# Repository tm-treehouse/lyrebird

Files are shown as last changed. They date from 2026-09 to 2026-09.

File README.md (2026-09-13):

# lyrebird

PCM audio from a host PC to an FPGA over USB, with no USB IP in the fabric.

```
Host PC ──USB 3.0──> FT601Q ──245 Sync FIFO, 32-bit, 66.67 MHz──> GateMate
                                                                     │
                                              28 element lines over mezzanine
                                                                     │
                            reclock ──> matched resistors ──> filter ──> line / headphone
```

An FTDI bridge puts the USB device controller and endpoints in silicon and
presents the FPGA with a dumb synchronous FIFO, so the fabric needs no USB
knowledge. The FPGA owns the audio clock; the host is flow-controlled by
backpressure.

There is no DAC chip. The FPGA runs an interpolator and a three-bit
delta-sigma modulator with dynamic element matching, and drives a resistor
network directly.

Two boards, joined at the element lines. The main board carries USB, the FPGA,
and the power tree. The output module carries the oscillators, the reclocking
flip-flops, the resistors, and the analog stage, so nothing analog crosses a
connector and the output stage can be revised without respinning the expensive
half.

See [docs/usb-audio-handoff.md](docs/usb-audio-handoff.md) for the original
design context, [docs/decisions/](docs/decisions/) for the rationale behind the
load-bearing choices, [docs/open-items.md](docs/open-items.md) for what is
still undecided, and [hardware/interface.md](hardware/interface.md) for the
contract between the two boards.

## Layout

| Path | Holds |
| --- | --- |
| `hardware/` | Two KiCad projects, datasheets, fab output, board interface |
| `hdl/` | Synthesizable RTL, constraints, cocotb testbenches |
| `host/` | C driver and WAV pump against the FTDI D3XX API |
| `docs/` | Design context and architecture decision records |
| `tools/` | Build, program, and bring-up scripts |

## Toolchain

- **PCB** — KiCad
- **FPGA** — Cologne Chip GateMate CCGM1A1, Yosys plus nextpnr-himbaechel via
  Project Peppercorn
- **Simulation** — Verilator with cocotb, driven by `hdl/sim/run.py`
- **Host** — C against FTDI D3XX

See [0013](docs/decisions/0013-simulation-and-build-toolchain.md) for verified
versions and which tools are still missing locally.

## Status

Simulation and synthesis both run end to end. Three HDL modules exist with 35
passing cocotb tests under Verilator, and `tools/synth.sh` takes a design from
source to a packed bitstream.

The audio chain is modelled numerically in [model/](model/), which settled the
modulator order, the interpolation cascade, the fixed-point coefficient widths
and the rotation algorithm with measurements. Both boards are described as code
in [hardware/netlist/](hardware/netlist/), which generates KiCad netlists and
makes an unfinished board show up as unconnected pins.

What is not done is tracked in [docs/open-items.md](docs/open-items.md).

Supports 44.1 through 192 kHz, switched at runtime by an in-band control word.
Bus powered from a single USB cable, with precision regulation confined to the
three module rails that reach the signal. Three-bit differential drive is a
recommendation rather than a measurement, which is why 32 element lines are
provisioned for 28 in use.

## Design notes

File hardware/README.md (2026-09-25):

# hardware

Two boards, split at the I2S boundary per
[0007](../docs/decisions/0007-two-board-split-at-i2s.md). The contract between
them is [interface.md](interface.md).

**The boards are described as code, not drawn.** `netlist/` holds SKiDL
generators that emit KiCad netlists; see [netlist/README.md](netlist/README.md)
for why, and for what is a real part versus a placeholder. Unconnected pins in
the generated netlist are the honest measure of how finished a board is, which
is why a missing part shows up as an open pin rather than as something nobody
wrote down.

- `netlist/` — the generators, and the authority on connectivity.
- `lyrebird-main-reva/` — USB connector, FT601Q, GateMate, power tree, SPI
  flash, programming header, mezzanine header. Generated netlist lands here.
- `lyrebird-dac-reva/` — audio oscillators, clock chain, reclocking registers,
  resistor elements and the analog output stage. There is no DAC chip: the FPGA
  is the converter, per
  [0008](../docs/decisions/0008-multibit-delta-sigma-with-dwa.md).
- `datasheets/` — vendor PDFs for parts on either board. Committed
  deliberately, because vendor links rot faster than the boards do.
- `fab/` — gerbers, drill files, BOM, and pick-and-place. Git-ignored by
  default since it is regenerated from source. When a board is actually
  fabricated, force-add a dated zip so the artifact that was built is
  recoverable.

One directory per board revision, so an old revision stays buildable after a
respin. The two boards revise independently, which is the point of the split.

## Main board

| Part | Role |
| --- | --- |
| FT601Q | USB 3.0 bridge, QFN-76, 32-bit FIFO. VCCIO on the 2.5 V rail |
| GateMate CCGM1A1 | FPGA, BGA324 15x15 mm. GPIO banks on the same 2.5 V rail |
| MX25R6435F | 64 Mbit quad SPI flash, FPGA configuration, SPI Active mode |
| LTM4622 | Dual switching module, the 2.5 V and 1.0 V rails |
| USB 3.0 Micro-B | Bus power and data, one cable |
| 30 MHz crystal | The bridge's only clock source; an oscillator will not do |

Roughly 43 pins face the bridge and 32 are provisioned for element lines to the
mezzanine, against 162 single-ended GPIO. Put the element outputs in their own
GPIO bank. The part has nine independently supplied banks, and while the module
reclocks everything anyway, there is no reason to share a rail between the
element drivers and the bridge interface.

Bus powered, with the core in economy mode. See
[0009](../docs/decisions/0009-usb-bus-power.md).

| Rail | Feeds | Part |
| --- | --- | --- |
| 5 V | Passed through to the module | Ferrite only |
| 3.3 V | FT601Q `VCC33`/`VDDA` | LT3045 |
| 2.5 V | FT601Q `VCCIO`, GateMate GPIO banks, mezzanine logic | LTM4622, ch 1 |
| 1.0 V | GateMate `VDD`, `VDD_PLL`, `VDD_SER`, `VDD_SER_PLL` | LTM4622, ch 2 |

Run the core at 1.0 V in economy mode rather than 0.9 V in low power mode. The
SerDes supplies have a 1.0 V minimum, so the lower setting would force a second
low-voltage rail for pins this design does not even use.

Nothing on this board is precision regulation. Every rail here is reclocked away
on the module, so none of it reaches the audio signal. The 3.3 V rail uses a
regulator rather than a switcher only because it feeds the USB PHY's analog
supply and FTDI's reference design does the same.

**Fit a noise filter between every regulator and the FPGA.** The GateMate
datasheet asks for this explicitly. There are no restrictions on the order rails
come up, so no sequencer is needed; the on-chip power-on reset handles it.

**Gate the FPGA rails with the LTM4622 run pins**, releasing them after the
bridge enumerates, so the board respects the one-unit-load limit that applies
before configuration.

## The 2.5 V rail is load-bearing

GateMate GPIO are LVCMOS up to 2.5 V with an absolute maximum VDDIO of 2.75 V.
They are not 3.3 V tolerant. The FT601Q is on this board specifically because
its VCCIO can be set to 2.5 V, which lets the two parts connect with no level
translation. Do not substitute a 3.3 V-only bridge without adding translators,
and do not hand 3.3 V logic to the mezzanine header. See
[0005](../docs/decisions/0005-ft601q-bridge-io-voltage.md).

Note that 100 MHz FIFO operation requires 2.5 V or 3.3 V on the FT601Q, so the
2.5 V choice does not close off the faster clock. The design uses 66.67 MHz
anyway, for timing margin rather than necessity.

## Output module

There is no DAC chip. The FPGA runs the modulator; this board turns element
lines into an analog waveform. See
[0008](../docs/decisions/0008-multibit-delta-sigma-with-dwa.md).

| Section | Part or role |
| --- | --- |
| Audio oscillators | Crystek CCHD-957 at 49.152 and 45.1584 MHz. One runs, the other in standby |
| Divider and fanout | Divide by two to the element clock, distribute with tight skew |
| Level translator | 74AVC4T245, 2.5 V toward the connector, 3.3 V toward the module |
| Reclocking registers | One 16-bit package per channel, on the element reference rail |
| Matched resistors | Summing network, 28 elements for three-bit differential stereo |
| Reconstruction filter | Passive, before the op amp |
| Output stage | Differential to single-ended, then line and/or headphone |

**The module domain is 3.3 V**, the header stays at 2.5 V, and the translator
sits on this side of the boundary so the mezzanine never carries 3.3 V. Full
scale is therefore 3.3 V rather than 2.5 V, worth about 2.4 dB. See
[0012](../docs/decisions/0012-module-clock-architecture.md).

Two oscillators are required because the sample rate families sit at a ratio of
147 to 160, which no divider bridges. They run at twice the element clock
because jitter expressed in time improves with carrier frequency, and because a
16 ns round trip through the translator would leave only about 4 ns of setup
margin at the undivided rate. The standby pin shuts the resonator down rather
than only gating the output, which is what keeps an idle oscillator from
radiating next to the analog section.

### Reclocking

The flip-flops are what make this architecture work. Without them the analog
output would be generated by the FPGA's output drivers, timed by the FPGA's
global clock mesh, and referenced to the FPGA's I/O bank supply. All three are
poor analog references: the mesh carries tens of picoseconds of jitter, driver
on-resistance shifts with process, voltage and temperature and differs between
the high and low states, and the I/O rail is a switching-regulator-fed digital
supply.

The flip-flop replaces all three at once. Its output swing becomes full scale,
its clock comes from the oscillator, and its drivers are one consistent type on
one die.

**Use one 16-bit register per channel, not two octal parts.** Three-bit
differential is fourteen elements per channel, which fits a single package with
two bits spare, putting both polarities on the same die with one supply pin and
one clock-to-output distribution. Even-order cancellation depends on the two
sides matching, so this is worth protecting. Decouple at the package, because
that supply pin is where the element switching current actually comes from.

**Choose a logic family whose input threshold is 2.0 V at a 3.3 V supply.** The
registers sit on the 3.3 V rail but their data inputs are driven at 2.5 V by
the FPGA, which guarantees 2.4 V. A family referencing its threshold to 0.7
times the supply would sit at 2.31 V and be marginal. This is why the element
lines need no translators, which would otherwise mean seven more packages
injecting skew into the signals least able to tolerate it.

### The element reference rail

**This is a voltage reference, not a logic supply.** Each element contributes
the rail voltage divided by its resistor, so the output is directly
proportional to the rail. Noise there is multiplicative rather than additive:
it rides on the signal as modulation sidebands instead of sitting under it as a
floor.

For a dynamic range near 110 dB, rail noise wants to be about 110 dB below the
rail, which on 3.3 V is roughly 10 uV across the audio band. Good low-noise
regulators reach that and generic ones do not. This is the one place in the
design where the specific regulator part matters.

Separate its two jobs. The regulator sets the DC value and the low-frequency
noise; it cannot hold the rail at the modulator rate, because its loop
bandwidth is orders of magnitude too low. Local ceramics supply the
high-frequency current. Neither substitutes for the other.

Give this rail to the flip-flops alone. Regulate the oscillator and the op amp
stage separately from a common upstream rail.

Differential thermometer drive keeps exactly seven elements high per channel at
every code, which is what stops the load itself from varying with the signal.

### The resistor elements

Dynamic element matching rotates mismatch into out-of-band noise, so absolute
tolerance matters much less than intuition suggests. One percent parts work,
and slow temperature drift is handled for free because it is slow compared to
the rotation.

**But it is not free, and an earlier version of this note overstated it.** The
model measured the cost of one percent mismatch at order 2, where the
modulator's own floor hides the rotation residual. At the recommended order 3
it costs 33 dB, not the fraction of a decibel first reported. What changes is
which component sets the floor: above order 2 it is element matching, not the
modulator.

**Specify the ratio tolerance, not the absolute tolerance.** The rotation
averages the elements against each other, so what matters is how closely the
seven match, and an element's absolute value only sets overall gain, which
nothing here depends on. An array at one percent absolute with a tenth of a
percent ratio spec beats half-percent discretes comfortably. Arrays are
specified this way precisely because it is the number that matters.

Measured end-to-end at order 3, rotation on, one seed —
`model/results/endtoend.txt`:

| Matching | 48 kHz | 96 kHz | 192 kHz | 44.1 kHz | 88.2 kHz | 176.4 kHz |
| --- | --- | --- | --- | --- | --- | --- |
| matched | 137.5 dB | 140.3 dB | 143.8 dB | 137.6 dB | 140.2 dB | 143.3 dB |
| 0.1 % | 137.4 | 140.1 | 143.5 | 137.5 | 140.0 | 143.0 |
| 1.0 % | 132.9 | 133.7 | **134.0** | 132.8 | 132.8 | 133.3 |

**This table replaces one that was wrong, and the way it was wrong is worth
recording.** The version here until now carried 0.05 % and 0.5 % rows, and the
only mismatch values ever measured anywhere in `model/` are 0, 0.1 % and 1 %.
It also made 192 kHz the *worst* rate where the model makes it the best, and
described itself as averaged over three element draws when no such run exists.
The two conclusions drawn from it — that tightening from one percent to half
buys about 4 dB, and that going past a tenth of a percent buys nothing — rested
on rows that were never produced.

What the real numbers say instead:

- **0.1 % is free.** It costs 0.1 to 0.3 dB against perfectly matched elements
  at every rate. There is no reason to pay for tighter.
- **1 % costs 4.6 dB at 48 kHz and 9.8 dB at 192 kHz**, and the loss grows with
  rate because a matched chain improves with oversampling while the rotation
  residual does not. That is the opposite of what the old table implied.
- **The number to hold the hardware to is 132.8 dB**, the worst rate at 1 %.
  Two cautions on it, both from measurements made since: it is a *tone's*
  figure and a median window's, not a bound — real material's worst window is
  111.5 dB — and a single seed spans 5.3 dB across five draws, so this row is
  one sample of a distribution rather than a property.

The elements specified for the board are 0.1 % thin film, which is the first
row that costs nothing.

What the rotation does not fix is nonlinearity within a single resistor.
Voltage coefficient is real in thick film and small in thin film, so specify
thin film and do not let a purchasing substitution quietly change it. Prefer
thin film arrays over discretes for the same die-sharing reason as the
registers.

The summing resistors are already in the signal path, so a shunt capacitor at
the summing node buys the first filter pole for one part, before anything
active sees the stepped waveform.

**Filter the out-of-band noise passively before the op amp.** Noise shaping
works by moving quantization noise above the audio band, and it is still there.
An op amp asked to slew on it will intermodulate it back down.

A combined module shares the differential-to-single-ended stage, then splits to
a fixed-gain line buffer that bypasses volume control and a volume-controlled
headphone amplifier gated by the jack switch contact.

If the output stage needs a bipolar supply, generate it on the module and
post-regulate it. Op amp power supply rejection falls off steeply with
frequency, so at a charge pump's switching frequency the op amp rejects far
less than its headline figure. Run the pump a little hot and drop to the final
rail through low-dropout regulators.

## Layer stack

Roughly 43 FIFO signals run between the bridge and the FPGA on the main board,
plus USB 3.0 SuperSpeed differential pairs needing controlled impedance.
Cologne Chip advertises that the BGA324 escapes in two signal layers. Do not
take that as permission to build a two-layer board; budget for a solid ground
plane.

## Configuration

GateMate selects its configuration mode by strapping `CFG_MD[3:0]` to GND or
VDD_WA at reset. This design uses SPI Active, so the FPGA loads itself from
flash with no host involvement. A separate header carries the programming
interface. See [0006](../docs/decisions/0006-configuration-from-spi-flash.md).

**The flash is an MX25R6435F, 64 Mbit.** Two things fix that. The bitstream
scales with utilisation rather than being a fixed image
([0013](../docs/decisions/0013-simulation-and-build-toolchain.md)), so the
2 Mbit an earlier revision called ample is not; and Cologne Chip's own
evaluation board for this die fits exactly this part at exactly this size.
Its 1.65 to 3.6 V supply range is the other half of the choice: `VDD_WA` is
2.5 V and an ordinary 2.7 to 3.6 V flash cannot run there.

**Power-on reset is deliberate rather than default.** `POR_EN` goes to
`VDD_WA` and `RST_N` to `VDD_CLK`, as the datasheet's figure 3.4 has it, and
`POR_ADJ` carries a 47 k to `VDD_CLK` with 2.2 uF to ground. Against the
internal 133 k / 75 k divider the datasheet's formula gives about 19.4 ms of
release delay, which clears the 4.3 ms programmed soft start on the 2.5 V
rail by better than four times. Keeping R3a at or below 100 k is the
datasheet's own condition for the network never latching the part in reset,
so it only sets the release time.

## Committing KiCad

Commit `.kicad_pro`, `.kicad_sch`, `.kicad_pcb`, local symbol and footprint
libraries. Local state (`.kicad_prl`), autosave, lock files, and the footprint
cache are ignored. Never commit a `-backups/` directory.

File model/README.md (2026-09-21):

# model

A numerical model of the audio chain, built to answer the questions the
repository left open with numbers rather than adjectives. Run it:

```
./.venv/bin/python model/run_experiments.py   # order, cascade, coefficients, rotation
./.venv/bin/python model/run_endtoend.py      # the chain connected, and datapath width
./.venv/bin/python model/run_idle.py          # idle channel, and what the window was doing
./.venv/bin/python model/run_programme.py     # real programme material, window by window
```

Figures land in `figures/`, the logs in `results/measurements.txt`,
`results/endtoend.txt`, `results/idle.txt` and `results/programme.txt`.

**If you read an earlier version of this file, four of its claims were wrong.**
Two were measurement errors: the low-frequency limit cycle it reported does not
exist, and the 15.7 dB it attributed to round-half-up was the same error. Two
were correct measurements stated with the wrong scope: **132.8 dB is a tone's
figure and a median window's figure, not a worst case** -- real material's
worst window is 111.5 dB -- and **3 dB of headroom does not cover the case the
headroom budget exists for**, which is clipped material, at 5.39 dB. All four
are corrected below, with what actually caused them.

Real material also turned up one thing nothing predicted: **the error is worst
where the signal is quietest.** See "The error is worst where the signal is
quietest" below.

## Recommendations

### Modulator order: 3

| Order | Max stable amplitude | SNDR, 20 Hz to 20 kHz |
| --- | --- | --- |
| 2 | 0.996 | 126.3 dB |
| 3 | 0.918 | 168.1 dB |
| 4 | 0.855 | 204.2 dB |
| 5 | 0.818 | 215.3 dB |

Order 2 already clears the 110 dB target by 16 dB, so the honest statement is
that every order works and [0008](../docs/decisions/0008-multibit-delta-sigma-with-dwa.md)
was right that the modulator is not where performance is decided.

Take order 3 anyway. It costs one integrator and buys 42 dB, which covers the
idealisations this model does not include: coefficient quantisation, finite
integrator gain, and clock jitter. The real cost is stability, not logic.
Maximum stable amplitude falls from 0.996 to 0.918, so roughly 0.7 dB of
output range is given up. Going beyond order 3 spends more range for margin
that is already far past what the analog section will deliver.

### Interpolation cascade: nine stages, 163 taps in the first

Designed for a 120 dB stopband, then measured after design.

| Stage | In | Out | Taps | Non-zero | Stopband |
| --- | --- | --- | --- | --- | --- |
| 1 | 48 kHz | 96 kHz | 163 | 83 | -122.1 dB |
| 4 | 384 kHz | 768 kHz | 27 | 15 | -133.6 dB |
| 5 | 768 kHz | 1.536 MHz | 15 | 9 | -130.3 dB |
| 6 | 1.536 MHz | 3.072 MHz | 11 | 7 | -135.6 dB |
| 7 | 3.072 MHz | 6.144 MHz | 11 | 7 | -168.9 dB |
| 8 | 6.144 MHz | 12.288 MHz | 7 | 5 | -140.7 dB |
| 9 | 12.288 MHz | 24.576 MHz | 7 | 5 | -163.6 dB |

Stages 2 and 3 reuse the stage-1 design at their own rates, which is why only
seven distinct filters appear. The cost that matters for the FPGA:

| | 48 kHz | 192 kHz |
| --- | --- | --- |
| Multipliers at the element clock | 2.86 | 2.62 |
| Coefficient words | 62 | 62 |
| Delay words | 567 | 241 |
| Group delay | 1501 us | 235 us |
| Passband ripple, peak to peak | 34.9 micro-dB | 15.0 micro-dB |
| Worst image | -122.1 dB | -122.1 dB |

Under three multipliers at the element clock is the number to design against.
The delay line storage is small next to the elastic buffer.

**The group delay at 48 kHz is 1.5 ms and is not free.** It adds to the
prefill latency rather than hiding inside it.

### Coefficient word width: 26 bits worst case, 8 bits for the fast stages

Float is not buildable on an FPGA, so every filter is specified as a fixed
signed fraction. The criterion is the 120 dB design target rather than the
double-precision result, because several stages land far past the target in
float and holding them there would buy stopband nobody asked for at the price
of wider words.

| Stage | Rate in | Min bits | Stopband achieved | CSD adders |
| --- | --- | --- | --- | --- |
| 1 | 48 kHz | 26 | -120.1 dB | 249 |
| 4 | 384 kHz | 22 | -120.4 dB | 41 |
| 5 | 768 kHz | 19 | -120.2 dB | 18 |
| 6 | 1.536 MHz | 18 | -123.0 dB | 17 |
| 7 | 3.072 MHz | 10 | -142.2 dB | 9 |
| 8 | 6.144 MHz | 8 | -122.7 dB | 3 |
| 9 | 12.288 MHz | 8 | -146.8 dB | 3 |

The shape is the useful part and it favours the hardware. The stages needing
wide coefficients run slowly, so they can be time-shared. The stages running at
the element clock need only eight bits and three adders each, so they can be
built as shifts and adds with no multiplier at all.

Worst case is 26 bits. The 340 adder total is dominated by stage 1's 249, and
stage 1 runs at the base sample rate, so it does not need 249 physical adders.

**Both rate families share one coefficient set.** The passband edge is
normalised so 20 kHz falls at the same fraction of the lower family's rate,
which means the 44.1 and 48 kHz families use identical filters and only the
oscillator changes. That halves the coefficient storage.

### Rotation: plain data weighted averaging is enough

Measured over 2^21 samples, with the DC offset removed. Element
mismatch produces a static output offset that real hardware trims or couples
away, and the lowest FFT bins otherwise fall inside a band starting at 20 Hz,
which would count that offset as audio-band noise.

| Element mismatch | Rotation | SNDR | THD |
| --- | --- | --- | --- |
| none | on | 126.9 dB | -144.4 dB |
| 0.1% | on | 126.9 dB | -144.3 dB |
| 0.1% | off | 77.1 dB | -77.1 dB |
| 1% | on | 126.4 dB | -142.5 dB |
| 1% | off | 57.1 dB | -57.1 dB |

Without rotation the output is distortion-limited: SNDR and THD track each
other exactly, which is the signature of mismatch appearing as harmonics rather
than as noise. Element loading was verified constant at seven across every
code, which is the invariant the differential drive exists to provide.

#### Correction: that table is at order 2, and 0.5 dB was the wrong reading

`run_experiments.py` selects the lowest order meeting the 110 dB target, which
is 2, and measures rotation there. At order 2 the modulator's own floor is
126.3 dB, which sits *above* the rotation residual and hides it. Re-measured at
order 3, with the source quantizer removed so nothing else masks it either:

| Element mismatch | Rotation | SNDR, order 2 | SNDR, order 3 |
| --- | --- | --- | --- |
| none | on | 126.9 dB | 167.9 dB |
| 0.1% | on | 126.9 dB | 154.5 dB |
| 0.1% | off | 77.1 dB | 77.1 dB |
| 1% | on | 126.4 dB | 134.7 dB |
| 1% | off | 57.1 dB | 57.1 dB |

**One percent mismatch costs 33.3 dB with rotation, not 0.5 dB.** The residual
is a real noise floor at 134.7 dB, and it only looked free because a noisier
modulator was sitting on top of it. The lower panel of
[endtoend_spectrum.png](figures/endtoend_spectrum.png) shows it directly: with
rotation on, the mismatch error is shaped, rising out of the audio band exactly
as 0008 claims; with rotation off it is a flat -125 dBFS floor plus a comb of
harmonics.

The recommendation is unchanged and the argument for it is stronger. Rotation
still buys 77.6 dB at one percent mismatch, it still clears the 110 dB target
by 24.7 dB, and it still confirms the claim in
[hardware/README.md](../hardware/README.md) that ordinary one percent parts are
adequate.

What changes is what sets the floor. **Above order 2 it is element matching,
not modulator order.** Going from order 2 to order 3 buys 8.3 dB at one percent
mismatch, not the 41.8 dB the order sweep promises. Tighter elements buy more
than a higher order does: 0.1 percent parts measure 154.5 dB.

## The chain end to end

`run_endtoend.py` connects the two halves that had only ever been measured
apart: real 24-bit PCM at Fs, through the cascade, into the modulator, through
the rotation and the differential elements, and out of the weighted sum. Order
3, a 1 kHz tone at -3.7 dBFS, which is 3 dB below the order-3 maximum stable
amplitude, 2^20 samples at the element clock, matched elements.

| Rate | SNR | SNDR | THD | Source floor in band |
| --- | --- | --- | --- | --- |
| 48 kHz | 138.5 dB | 137.6 dB | -144.9 dB | -142.2 dBFS |
| 96 kHz | 141.4 dB | 140.3 dB | -146.8 dB | -145.1 dBFS |
| 192 kHz | 144.8 dB | 143.8 dB | -150.5 dB | -148.6 dBFS |
| 44.1 kHz | 138.4 dB | 137.6 dB | -145.0 dB | -142.1 dBFS |
| 88.2 kHz | 141.1 dB | 140.2 dB | -147.4 dB | -144.8 dBFS |
| 176.4 kHz | 144.3 dB | 143.4 dB | -150.5 dB | -148.0 dBFS |

**Every rate clears the 110 dB target by at least 27.6 dB.** The quantizer
never clipped and the loop never left its bound at any rate.

### The chain as it will actually be built

The table above has perfect elements. With everything at once -- 24-bit TPDF
PCM, coefficients at their settled widths, the datapath at the widths
recommended below, order 3, rotation on, and elements with real tolerance:

SNDR, 20 Hz to 20 kHz:

| Rate | Matched | 0.1% elements | 1% elements |
| --- | --- | --- | --- |
| 48 kHz | 137.5 dB | 137.4 dB | 132.9 dB |
| 96 kHz | 140.2 dB | 140.1 dB | 133.7 dB |
| 192 kHz | 143.8 dB | 143.5 dB | 134.0 dB |
| 44.1 kHz | 137.6 dB | 137.5 dB | 132.8 dB |
| 88.2 kHz | 140.2 dB | 140.0 dB | 132.8 dB |
| 176.4 kHz | 143.3 dB | 143.0 dB | 133.3 dB |

**132.8 dB is the worst case over every rate with one percent elements, for a
tone**, 22.8 dB above the 110 dB target of 0012.

**It is not a bound, and an earlier version of this section said it was.**
Measured against real programme material window by window -- `run_programme.py`,
`notes-programme.md` -- the same chain at the same widths gives a median of
128.6 dB and a worst window of **111.5 dB**, 1.5 dB above the target rather
than 22.8. A tone's figure varies by 1.1 dB from window to window; real
material's varies by 27.7 dB.

So the number keeps its meaning and loses its scope. 132.8 dB is what a tone
measures, and it is also what a typical window of music measures, which is why
it is still the right figure to quote for the design and to hold the hardware
to on a bench. What it does not do is bound the worst 42 ms of a record. The
distribution, not this number, is the description of the chain against music;
see [Q1 in notes-programme.md](notes-programme.md) and
[programme_windows.png](figures/programme_windows.png).

### The error is worst where the signal is quietest

This is the one result real material turned up that nothing in the tone
measurements predicted, and it is the wrong way round.

16.7 seconds of real 48 kHz recording, one percent elements, split by how much
in-band signal each 42.7 ms window carries:

| In-band signal in the window | Windows | Median error | Matched elements |
| --- | --- | --- | --- |
| Above -12 dBFS | 5 | -137.3 dBFS | -142.5 dBFS |
| -30 to -12 dBFS | 50 | -135.2 dBFS | -142.3 dBFS |
| **-60 to -30 dBFS** | **71** | **-125.2 dBFS** | **-142.3 dBFS** |
| Below -60 dBFS | 234 | -135.8 dBFS | -142.3 dBFS |

**Windows 30 to 60 dB down measure 12 dB worse than loud ones.** The
matched-element column is flat at -142.3 dBFS across every band, so there is
nothing else it can be: it is the rotation residual, and rotation works less
well where there is less to rotate. Data weighted averaging makes every element
carry every code equally often *over time*; with a small signal the code
sequence has a short range and the pointer traverses the ring less thoroughly
per unit time.

It is not a fault, it is not a limit cycle, and it does not threaten the 110 dB
target -- the worst single window of 360 still measures 111.5 dB. What makes it
worth stating in the README rather than leaving in the notes is that **quiet
passages are where a listener is most able to hear a converter's floor**, and
this chain's floor is at its worst exactly there. Any listening test that plays
loud material will miss it.

The lever is element tolerance, which README already identifies as the term
that sets performance. This says it also sets the worst case, and that the
worst case is not where a tone measurement would look for it.

Note which term dominates. With one percent elements the mismatch residual sits
close to the 24-bit source floor, so element tolerance and source word length
are within a few dB of each other and everything else in the digital chain --
modulator, cascade, coefficients, datapath -- is 25 dB or more below both. The
rate spread also collapses: matched elements span 6.3 dB across the rates,
one percent elements span 1.2 dB, because mismatch noise is shaped by the loop
and does not care what the sample rate was. That is 0008's "the digital side
has large headroom, the analog side sets performance", now with numbers.

### Yes, it differs from the subsystem numbers, by 30 dB

| | SNDR |
| --- | --- |
| Modulator alone, tone generated at the element clock | 168.1 dB |
| Same modulator behind the cascade, source quantizer removed | 167.9 dB |
| Same, fed real 24-bit TPDF-dithered PCM at 48 kHz | 137.6 dB |

The first two lines answer the question the gap was actually about: **the
cascade costs 0.2 dB, which is the measurement floor.** Its transition-band
behaviour reaches the modulator and does nothing to it. The modulator order
sweep, the cascade design and the coefficient widths all survive contact with
each other unchanged. The rotation *recommendation* survives too; the 0.5 dB
figure quoted for it does not, and is corrected above.

The third line is the one that matters. **The end-to-end figure is set by the
24-bit source, not by anything in the FPGA.** A 24-bit TPDF-dithered sample
stream carries a floor of -142.2 dBFS in a 20 Hz to 20 kHz band at 48 kHz, and
the modulator's own floor is 30 dB below that. The rate trend is the giveaway:
the source floor is white over Fs/2, so every doubling of the sample rate
spreads it over twice the bandwidth and buys about 3 dB in band. Nothing else
in the chain behaves that way.

Two consequences for the HDL:

* **Do not spend logic on modulator order beyond 3.** At order 2 the
  end-to-end figure is 126.8 dB against order 3's 137.6 dB, so order 3 earns
  its integrator. Order 4 would earn nothing: the order-3 modulator floor
  already sits 30 dB below the source floor, and 6 dB of that is spent for
  free by moving from 48 to 192 kHz.
* **Undithered 24-bit input measures 4.5 dB better, not worse** (142.1 dB at
  48 kHz against 137.6 dB), because the cascade decorrelates what would
  otherwise be distortion. Both are reported since the chain has no say in
  which the host sends.

## Headroom: the cascade moves where full scale is

Maximum stable amplitude was characterised against a clean tone generated at
the element clock. Re-measured with PCM through the cascade, same bisection and
same bound, so the numbers compare directly:

| Content | MSA at the PCM input | Peak reaching the quantizer |
| --- | --- | --- |
| Modulator alone, clean tone | 0.900, -0.92 dBFS | -0.92 dBFS |
| 1 kHz tone, 48 kHz | 0.900, -0.92 dBFS | -0.92 dBFS |
| 1 kHz tone, 192 kHz | 0.911, -0.81 dBFS | -0.81 dBFS |
| Passband-edge tone, 21.6 kHz at 48 kHz | 0.911, -0.81 dBFS | -0.81 dBFS |
| Passband-edge tone, 86.4 kHz at 192 kHz | 0.955, -0.40 dBFS | -0.40 dBFS |
| Fs/4 inter-sample, 48 kHz | 0.644, **-3.83 dBFS** | -0.82 dBFS |
| Fs/4 inter-sample, 192 kHz | 0.659, **-3.63 dBFS** | -0.62 dBFS |

**Max stable amplitude holds, measured at the quantizer. It does not hold
measured at the PCM input.** Every row above overloads at the same place, a
peak of -0.4 to -0.9 dBFS at the quantizer. What changes is how much PCM level
that corresponds to, and for inter-sample content it is 3 dB less.

The last two rows are the standard inter-sample overload probe: a tone at Fs/4
sampled at 45 degrees, so every sample sits at the stated level and the
reconstructed waveform peaks 3.01 dB above it. The cascade is a reconstruction
filter, so it produces that peak faithfully and hands it to a modulator that
cannot take it. Measured peak out of the cascade for a 0 dBFS record of this
kind is exactly 1.4142.

This is not a corner case. Heavily limited material contains inter-sample overs
routinely.

### The headroom budget exists for clipping, and 3 dB does not cover it

Measured against real material by `run_programme.py`, two things changed here.

**Nothing that has not been clipped asks for any headroom at all.** Sixteen
seconds of real 48 kHz recording, crest factors 15 to 26 dB, normalised so its
loudest sample sits at full scale, hands the quantizer a peak of exactly
1.0000 -- zero overshoot -- and survives to within 0.66 to 0.80 dB of full
scale. A 1 kHz sine asks for 0.84 dB. The synthetic percussive record, at a
21.8 dB crest factor, overshoots by 0.029 dB.

What creates an inter-sample over is the run of samples sitting flat at full
scale that only clipping produces, and the probe is the limiting case of it:
every one of its samples is at full scale by construction, which is why it
reaches exactly 3.010 dB. **So the budget has a named cause. It is not sized by
how loud music is; it is sized by how hard the host's material was limited.**

**And 3 dB is 2.4 dB short of the worst case measured.** Percussive material
clipped 12 dB overshoots by 4.876 dB and needs **5.39 dB** of headroom against
the probe's 3.84:

| Material | Overshoot | Headroom needed |
| --- | --- | --- |
| Real audio, unprocessed | +0.000 dB | 0.80 dB |
| Real audio, clipped 12 dB | +0.653 dB | 1.22 dB |
| Percussive, unprocessed | +0.029 dB | 0.61 dB |
| **Percussive, clipped 12 dB** | **+4.876 dB** | **5.39 dB** |
| 1 kHz tone | +0.000 dB | 0.84 dB |
| Fs/4 inter-sample probe | +3.010 dB | 3.84 dB |

**Recommendation: clip at the modulator input. Do not use a -3 dBFS volume
default.** README previously offered the two as equivalent alternatives; they
are not. A fixed -3 dB default gives away 2.2 dB of range on everything that
was never limited *and* is still 2.4 dB short of material that was. A clipper
costs nothing on material that never reaches it and has no upper bound to get
wrong. Either sits inside the interpolation chain, which is where
[0010](../docs/decisions/0010-192khz-and-control-word.md) already puts the
volume control and for the same reason.

**A cheap indicator comes with it.** The fraction of samples sitting on the top
or bottom quantizer code -- one comparator, free in the FPGA -- rises about
threefold per dB for several dB before the loop lets go:

| PCM level | Real audio | Real, clipped 12 dB |
| --- | --- | --- |
| -6 dBFS | 0.0000 | 0.0000 |
| -3 dBFS | 0.0016 | 0.0052 |
| -2 dBFS | 0.0056 | 0.0163 |
| -1 dBFS | 0.0164 | **unbounded** |
| 0 dBFS | **unbounded** | -- |

The in-band error stays flat at -135 to -137 dBFS right up to the edge, so
performance does not degrade into the overload: it is fine, and then it is
gone. A threshold anywhere between 1e-4 and 1e-2 gives warning with margin.
One caveat: percussive material clipped 12 dB goes from 0.0002 to unbounded in
1.5 dB, so the warning is shortest where it is most needed. The counter is an
early indication to pair with the clipper, not a replacement for it.

A measurement note that cost a wrong answer here: **the analysis window has to
be centred on the peak the cascade reconstructs, not on the loudest sample.**
For unprocessed material they are the same event. For clipped material they are
seconds apart -- 1.5 s on the percussive record, 5.9 s on the real one --
because clipping makes the reconstruction overshoot wherever a flat run happens
to sit, not where the record is loudest. Windowed on the loudest sample this
same bisection returned 3.75 dB and appeared to confirm the probe to 0.09 dB.

A smaller correction to the existing table: the 0.918 in the order sweep was
measured over 2^15 samples, which is 1.3 cycles of a 1 kHz tone. Over 2^18 it
is 0.900. The order recommendation does not change; the figure is 0.17 dB
optimistic.

## Datapath width

Coefficient width was settled above. These are the other two numbers the HDL
needs, both measured rather than reasoned.

The criterion is stated before the measurement. The most demanding source floor
of any supported rate is 192 kHz at -148.6 dBFS, so the whole interpolator is
budgeted 10 dB below that, at -158.6 dBFS, which costs 0.41 dB end to end. Nine
stages share it equally, so each gets -168.2 dBFS.

Noise is measured by difference: the same record is run twice, once at the
stated widths and once exact, and the in-band power of the difference is taken.
The difference carries no signal, so there is no lobe to excise and no pair of
near-equal spectra to subtract, and a floor 80 dB below the signal reads as
directly as one 10 dB below it.

### Signal word: 28 bits, flat across all nine stages

Sign, one integer bit, 26 fractional bits. One integer bit because the largest
peak the cascade can present is the inter-sample 1.4142, and anything past that
is already overloading the quantizer and belongs clipped rather than
represented.

Measured one stage at a time, with the rest exact, the minimum does taper with
the rate, exactly as the noise argument predicts -- a stage's rounding is white
over its own output rate, so the same word is 3 dB quieter in band at every
doubling:

| Stage | 1 | 2 | 3 | 4 | 5 | 6 | 7 | 8 | 9 |
| --- | --- | --- | --- | --- | --- | --- | --- | --- | --- |
| Output rate, MHz | 0.096 | 0.192 | 0.384 | 0.768 | 1.536 | 3.072 | 6.144 | 12.288 | 24.576 |
| Minimum fractional bits | 27 | 26 | 26 | 25 | 24 | 24 | 24 | 23 | 22 |

**Building that taper is a mistake, and this is the main datapath finding.** A
half-band stage has two phases. The filtered phase accumulates products and has
to round. The pass-through phase is the centre tap against an interpolation
gain of two -- a wire -- and it rounds only if the next word is narrower than
the one the sample already sits on. A tapering chain therefore re-rounds every
sample at every stage. Measured on the whole chain:

| Schedule | 48 kHz, 9 stages | 192 kHz, 7 stages | Delay-line bits at 48 kHz |
| --- | --- | --- | --- |
| taper 26..22 | -155.9 dBFS | -156.3 dBFS | 15,259 |
| flat 24 | -153.3 dBFS | -159.1 dBFS | 14,579 |
| flat 25 | -160.5 dBFS | -165.4 dBFS | 14,983 |
| **flat 26** | **-165.5 dBFS** | **-172.3 dBFS** | **15,387** |
| flat 27 | -172.0 dBFS | -178.8 dBFS | 15,791 |

**The taper is 9.6 dB noisier than a flat word of the same starting width and
saves 0.8 percent of the delay-line storage.** Per-stage minima are real;
composing them is not, because the per-stage measurement cannot see a cost that
only exists where two stages meet. The taper measured is 26..22, one bit
narrower at stage 1 than the per-stage table asks for, so if anything the
comparison flatters it.

25 fractional bits is the narrowest flat word that meets the budget at every
rate. 26 is the recommendation, for 5 dB of margin at 2.7 percent more storage,
which is nothing against the 25 block RAMs 0011 spends on the elastic buffer.

The equal per-stage share of -168.2 dBFS is an allocation device for the table
above, not a constraint on the answer. The flat word is chosen against the
chain budget directly, and clears it by 6.9 dB, because only stage 1 comes
anywhere near its share and the other eight land far under it.

### Accumulator: 35 bits at the steep stages, 31 at the fast ones

Each product is rounded into the accumulator, which is the pessimistic reading:
a MAC whose output register is the accumulator rounds every product, not only
the final sum. The criterion is that the accumulator must not be the louder of
the two noise sources in its own stage, at or below 0.5 dB added to the signal
word's own contribution.

| Stage | Products | Signal word alone | Min fractional bits | Guard | Bits above the point | Total | Full precision would be |
| --- | --- | --- | --- | --- | --- | --- | --- |
| 1 | 41 | -167.8 dBFS | 30 | +4 | 4 | 34 | 51 |
| 2 | 41 | -170.8 dBFS | 31 | +5 | 4 | 35 | 51 |
| 3 | 41 | -174.2 dBFS | 31 | +5 | 4 | 35 | 51 |
| 4 | 7 | -177.4 dBFS | 30 | +4 | 3 | 33 | 47 |
| 5 | 4 | -180.7 dBFS | 30 | +4 | 3 | 33 | 44 |
| 6 | 3 | -182.9 dBFS | 28 | +2 | 2 | 30 | 43 |
| 7 | 3 | -185.4 dBFS | 28 | +2 | 2 | 30 | 35 |
| 8 | 2 | -188.2 dBFS | 28 | +2 | 2 | 30 | 33 |
| 9 | 2 | -191.7 dBFS | 29 | +3 | 2 | 31 | 33 |

Rounded into three groups the HDL can parameterise: **35 bits for stages 1-3,
33 for stages 4-5, 31 for stages 6-9.** A full-precision accumulator would be
51 bits at stage 1, so this saves 16 bits there and 2 at stage 9.

Bits above the binary point come from the L1 norm of each stage's filtered
phase against the largest peak the cascade can present. That bound is 4.06 at
the three steep stages and under 2 from stage 6 on. The symmetric pre-add is
exact and one bit wider than the signal word; keeping it costs nothing.

The shape is the opposite of the coefficient result and favours the hardware
the same way. The stages needing the widest accumulators run slowest, so they
are time-shared; the stages at the element clock need 31 bits and two products.

### Round ties to even

Round-half-up is one adder and is the obvious choice. It is also biased: a word
already sitting on a finer grid ties exactly half the time and every tie goes
up, so each rounding leaves about a quarter of an LSB of offset and nine stages
of them add. Measured at the modulator input that offset is -160.4 dBFS, which
is half an LSB of a 26-bit word and looks like nothing.

It is also very nearly nothing, and an earlier version of this section said
otherwise. **The 15.7 dB this table used to report was a measurement error, not
a property of the rounding.** The corrected figures, from `run_idle.py`
section D:

Measured over 2^22, which is what the corrected columns are; the last column
is the figure this table used to print, from the same records over 2^20 with
the arithmetic mean removed.

| Rate | Ties up | Ties to even | Ties up, as published |
| --- | --- | --- | --- |
| 48 kHz | 138.41 dB | 138.42 dB | 137.45 dB |
| 96 kHz | 141.39 dB | 141.41 dB | **124.58 dB** |
| 192 kHz | 144.35 dB | 144.35 dB | 143.43 dB |
| 44.1 kHz | 137.98 dB | 137.99 dB | 124.73 dB |
| 88.2 kHz | 140.88 dB | 140.88 dB | 140.14 dB |
| 176.4 kHz | 144.10 dB | 144.07 dB | 142.79 dB |

**Worst case costs 0.02 dB**, and `results/endtoend.txt` now prints the same
figure from its own table. The old numbers came from subtracting the
arithmetic mean rather than the windowed mean before a 2^20 transform, which
counts a sub-20 Hz residue as audio-band noise; `spectra.remove_dc` now does
it correctly for every measurement in the model and explains why. The full
account is in [notes-idle.md](notes-idle.md).

The giveaway, had anyone looked: re-running the old code today puts the 124 dB
row at **44.1 kHz**, not 96 kHz. Half-up leaves the same offset at every rate,
so a fault caused by that offset cannot move between rates from one run to the
next.

**Round ties to even anyway.** It costs one adder's difference and it removes a
real static offset: measured at the modulator input, half-up leaves -168.7 to
-170.3 dBFS where ties to even leaves -187.3 to -210.3 dBFS. That offset
reaches the output as DC, where it is the output coupling capacitor's problem rather than
the FPGA's, and an unbiased rounding is the cheaper place to deal with it. What
is no longer claimed is that it costs audio-band performance. It does not,
measurably.

### What the recommended datapath measures

Signal word 28 bits flat, accumulators as above, coefficients as settled, ties
to even. `SNDR exact` is the same chain with an infinite-precision datapath.

| Rate | Datapath noise | SNDR exact | SNDR sized | Cost |
| --- | --- | --- | --- | --- |
| 48 kHz | -165.8 dBFS | 137.57 dB | 137.54 dB | 0.03 dB |
| 96 kHz | -168.6 dBFS | 140.29 dB | 140.25 dB | 0.04 dB |
| 192 kHz | -172.7 dBFS | 143.83 dB | 143.83 dB | 0.00 dB |
| 44.1 kHz | -165.6 dBFS | 137.56 dB | 137.55 dB | 0.01 dB |
| 88.2 kHz | -168.6 dBFS | 140.18 dB | 140.15 dB | 0.03 dB |
| 176.4 kHz | -171.7 dBFS | 143.40 dB* | 143.33 dB | 0.07 dB |

**The whole sized datapath costs at most 0.07 dB.**

\* This row used to read 125.06 dB and carried a footnote blaming a limit
cycle. **That was a measurement error.** The same record, with the windowed
mean removed instead of the arithmetic mean, measures 143.40 dB; measured over
2^21 with nothing else changed it measures 143.69 dB. The conclusion the
footnote drew -- that the discrepancy had nothing to do with word width -- was
right, for the wrong reason. See below and [notes-idle.md](notes-idle.md).

## There is no low-frequency limit cycle. That was a measurement error.

This section used to report one, and several figures elsewhere in this file
were adjusted for it. **All of it was the analysis window.** Anyone who read
the earlier text should discard it: there is no intermittent fault in the loop,
dither was never failing to fix anything, and the 1-in-36 rate was a count of
how often a rounding residue landed where a too-short transform could see it.
`run_idle.py` establishes this and [notes-idle.md](notes-idle.md) gives the
full account.

### What was measured

The claim was that one run in 36 came back 15 to 19 dB low with every bit of
the excess in the 20 Hz to 100 Hz bins, worst case 125.1 against 143.3 dB. That
run reproduces exactly, so it could be taken apart:

| The same 2^20 record | SNDR | 20-100 Hz |
| --- | --- | --- |
| DC removed arithmetically, `x - x.mean()` | 125.06 dB | -130.2 dBFS |
| DC removed with the window | **143.40 dB** | **-172.9 dBFS** |

and the same trajectory, with nothing corrected, simply measured for longer:

| Window | Bin width | DC main lobe reaches | SNDR |
| --- | --- | --- | --- |
| 2^20 | 21.5 Hz | 258 Hz | 125.06 dB |
| 2^21 | 10.8 Hz | 129 Hz | 143.69 dB |
| 2^22 | 5.4 Hz | 65 Hz | 143.94 dB |
| 2^23 | 2.7 Hz | 32 Hz | 144.11 dB |

The Kaiser at beta 26 has a main lobe 12 bins wide, which at 2^20 samples of a
22.6 MHz element clock is ±258 Hz. **At that record length, near-DC energy and
20-100 Hz energy are the same bins.** Subtracting the arithmetic mean does not
remove the DC the transform sees, because the window weights the centre of the
record far above its ends, so whatever residue is left lands in the lowest
audio bins at nearly full strength.

Rerunning the whole limit-cycle experiment -- six rates, six perturbations,
with and without 0.25 LSB of quantizer dither -- gives **1 run of 72 more than
5 dB below its row median as published, and 0 of 72 on the same records
measured correctly.** Dither was not moving the fault around; every remedy
changes the record, every record leaves a different residue, and the short
window reported the residue.

### What is really there, and why it does not matter

A residue is unavoidable and it is not a limit cycle. The output takes eight
levels spaced 2/7 apart, so **the mean of an N-sample record can only sit on a
grid of (2/7)/N**: a finite record of this alphabet cannot express its own mean
exactly. One unbalanced sample per window is

| Window | |
| --- | --- |
| 2^20 | -128.3 dBFS |
| 2^22 | -140.3 dBFS |
| 2^24 | -152.4 dBFS |

and that is what the tripped record had -- measured per 2^20 block, an
imbalance of `+1 -1 +1 -1 0 0 0 0` samples. A -128 dBFS component at about
10 Hz. It is **below the audio band**, it is at the smallest level the output
alphabet can express over that window so nothing in the digital design can
reduce it, and it is DC at the output, which is what the coupling capacitor is
already there for.

Measured directly at idle it is not even that large. Over 180 trials of
`material.py`'s idle catalogue -- fades into silence, digital silence, near
silence at -100 dBFS, small DC offsets, six rates, six preambles each -- the
20 Hz to 100 Hz band of the element sum measures:

| Idle material | 20-100 Hz, over 180 trials |
| --- | --- |
| digital silence | -324 to -346 dBFS |
| small DC offset, -60 dBFS | -321 to -331 dBFS |
| after a fade to silence | -147 to -153 dBFS |
| digital silence, dithered 24-bit source | -162 to -175 dBFS |
| near silence, -100 dBFS | -126 to -140 dBFS |

The last two rows are the source's own noise arriving at the output, which is
what should happen. The first two are nothing at all. Measured the old way the
same trials put 22 of 180 more than 10 dB above their own median, with digital
silence reading -130 dBFS where it is really -340.

A constant at the modulator input does not produce an idle tone either. Swept
from -160 to -60 dBFS, including the -133 to -119 dBFS range where a
first-order loop's correction rate would land between 20 and 100 Hz, the
in-band figure stays at -179 dBFS and all of it is the shaped floor above
2 kHz. A third-order loop with an eight-level quantizer does not lock to a
constant.

### What this cost, and what stops it recurring

Three published results were wrong: this section, the ties table above, and the
capacitor-tolerance table in `results/analog.txt`. Everything else checked --
every per-rate figure, the 132.8 dB tone figure, the rotation table, the order
sweep, the volume placement, the datapath widths -- is unaffected to 0.01 dB,
because the term only shows when the residue happens to be large.

(132.8 dB survived this correction unchanged, and was then corrected for a
different reason: it is a tone's figure and a median window's figure, not a
bound. See the end-to-end section above and `notes-programme.md`.)

The fix is in one place. `spectra.remove_dc` removes the windowed mean and
documents why; `spectra.Measurement` now calls it for every measurement, so a
new measurement site cannot get this wrong by forgetting.

### What this leaves unmeasured

Closing this item is a negative result, and it is worth being precise about how
negative. **The low-frequency behaviour of this loop has not been
characterised; it was mis-measured, and the mis-measurement has been removed.**
What is established is that 180 near-idle trials and 72 tone runs show nothing
in the audio band, and that a constant at the modulator input produces no idle
tone. What is not established: nothing here was measured *below* 20 Hz on
purpose, since every measurement treats sub-20 Hz energy as something to
remove; no record longer than 341 ms was run, so a wander slower than about
3 Hz would not have been seen; and no threshold in physical units was ever set
for what an idle-channel fault worth acting on would look like, because nothing
came close enough to need one. `notes-idle.md` lists these in full.

## Measurement traps found while building this

Each cost real time and would cost it again.

**The FFT has to be long.** At the 24.576 MHz element clock, a 2^16 transform
gives 375 Hz bins, so the entire audio band is about 53 bins. Removing the
signal lobe and the harmonic lobes leaves nothing, and the measurement reports
infinite signal-to-noise with nonsensical distortion. Use 2^20 or longer, which
gives 23.4 Hz bins and around 600 usable noise bins. Simulation is not the
bottleneck: 2^20 samples takes under a second.

**Element mismatch produces a DC offset as well as noise.** Left in, it lands
in the lowest FFT bins, which sit inside a band starting at 20 Hz, and it then
dominates the in-band figure and makes the rotation look ineffective. It showed
up as in-band power 55 dB above a band nine times wider, which is the signature
of concentrated rather than broadband energy.

**Removing the mean means removing the mean the *transform* sees, and this one
cost three published results and two investigations to find.**

`x - x.mean()` zeroes the flat average of the record. The transform does not
take a flat average: it weights by the window, and a Kaiser at beta 26 weights
the record's centre enormously more than its ends. A record whose offset drifts
across the window therefore still has a DC bin after `x - x.mean()`, and that
bin is not confined to bin 0 -- the main lobe is 12 bins, ±281 Hz at 2^20 of
the element clock -- so the leftover lands inside a band starting at 20 Hz and
is counted as audio. Use `spectra.remove_dc`, which subtracts
`sum(w*x)/sum(w)`. `spectra.Measurement` now calls it for every measurement, so
a new measurement site cannot reintroduce this by forgetting.

*What it looks like when you hit it.* A figure comes back 15 to 19 dB low.
Every bit of the excess is in the 20 Hz to 100 Hz bins, so it looks like a
low-frequency fault rather than a raised floor. It is intermittent: most runs
are fine and roughly one in thirty is not. It survives every remedy you try,
and dither appears to *move* it to a different run rather than remove it. It
responds to perturbations far below the audio -- adding 2^-40 at the modulator
input switches it on or off -- so it looks like a real property of an exact
loop. Every one of those is the artifact, and together they are convincing
enough to have been written up here as a loop fault.

The reason a delta-sigma record always has the offset to leak: the output
alphabet is eight levels 2/7 apart, so the mean of an N-sample record can only
sit on a grid of (2/7)/N. One unbalanced sample per 2^20 window is already
-128 dBFS, which is 18 dB above the floor being measured. Which side of that
grid a record lands on is a lottery, and every remedy -- dither, a different
seed, one more sample of settling -- reshuffles it.

*The signature that gives it away, and the general rule.* Rerunning the ties
table today put the bad row at 44.1 kHz where it had been published at 96 kHz.
Round-half-up leaves the same offset at every rate, so **a fault that migrates
between rates from one run to the next cannot be caused by something that is
identical at every rate.** When a fault moves like that, it is a lottery over
records, and a lottery over records means the measurement, not the design. The
cheap confirmation is to measure the same record over a longer window: a real
in-band fault stays, an artifact of this kind is gone by 2^21.

**A DC offset is not only a mismatch problem, and removing the mean is not
optional anywhere.** The interpolator's own rounding leaves one too. Measured
on the nine-stage chain it was -143.1 dBFS against a rounding noise of
-159.5 dBFS, so reporting the chain without removing it made the datapath look
18 dB worse than it is. An earlier version of this paragraph went on to say
that the same offset at the modulator input was "not a measurement problem at
all but a real 15.7 dB fault". It was a measurement problem: see the ties
section above, where it now measures 0.02 dB. Removing the mean correctly is
what settles both. Any time a figure comes back bad, look at the 20 Hz to 100 Hz bins
first: if the excess is all there, it is an offset, not noise. Note what that
check cannot tell you, since it took two independent investigations to notice:
excess confined to those bins is equally the signature of a DC residue the
window is spreading into them, which is what the "limit cycle" turned out to
be. Confirm by re-measuring the same record over a longer window before
believing the loop did it.

**The FFT has to be long enough for the tone's harmonics to clear its own main
lobe, which is a stricter rule than having enough noise bins.** At 2^18 the
element-clock bins are 93.75 Hz and the Kaiser main lobe is 12 bins, so a
1 kHz tone's second harmonic falls inside the signal lobe, the harmonic
excision removes the signal, and SNDR is reported as 0.41 dB. The requirement
is `n > half_lobe * fs / f_sig`, which for a 1 kHz tone at 24.576 MHz is 2^19.
2^20 is the working minimum for both reasons.

**Peaks read off an un-faded record are the record's edge, not the signal.** A
record that switches on at a non-zero sample is a step and the cascade rings on
it. An un-faded 0 dBFS sine measured a peak of 1.118 through the chain where
the true reconstructed peak is 1.000, and the inter-sample probe measured 1.429
where its true peak is sqrt(2) = 1.4142. That is 1 dB of headroom invented out
of nothing, on the one measurement where headroom is the answer.

**If a figure does not move when the input level moves, the instrument has
stopped listening to the input.** This is the cheapest check in the list and it
caught the largest error `run_programme.py` made. An error figure that came
back at -88.4 dBFS at -12, -40 and -70 dBFS, to the last decimal and in the
same FFT bins, was not measuring the converter -- it was measuring a gain fit
that had been taken on un-centred signals, so the mismatch DC offset biased it
by whatever the reference happened to carry below 280 Hz. The fitted gain came
out 1.207 instead of 0.9988 on the quiet record. It cost a complete pass and
produced a 40 dB finding that did not exist. **Removing the mean from the error
is not enough; anything fitted to the error has to have it removed too.**

**A scalar fitted to broadband data has to be fitted in the band you report.**
Signal-to-noise against a tone excises the signal lobe; broadband material has
no lobe to excise, so the equivalent is fitting and removing a scalar gain --
element mismatch is a static weight and shows up as one. Fitted over the whole
record, that fit is dominated by the modulator's out-of-band noise, which is
90 dB above the in-band error and whose inner product with the signal is not
zero. The leftover gain error then injects a pure in-band residual around
-77 dBFS. Restricting the fit to 20 Hz-20 kHz drops it below -160.

**A lag check over a few samples cannot check alignment.** The signal is
band-limited to 20 kHz and sampled at 24.576 MHz, so its autocorrelation is
flat to six decimal places over plus or minus eight samples: an argmax there
reports where the out-of-band noise fell, and it false-alarmed on 34 of 90
segments of real material. Check the in-band error at the offset used against
the in-band error a few hundred samples away instead -- 256 samples is a fifth
of a period at 10 kHz, and a correct alignment wins by 90 dB or more.

**A peak window has to be centred on the reconstructed peak, not the loudest
sample.** They are the same event in unprocessed material and seconds apart in
clipped material. Getting this wrong made a headroom bisection return 3.75 dB
where the answer is 5.39 dB, and it looked right because it agreed with the
inter-sample probe to 0.09 dB.

**Per-stage results do not always compose.** Each interpolator stage's minimum
signal word, measured with the other stages exact, is real. The chain built
from those minima is 9.6 dB noisier than the flat word they suggest is
wasteful, because the cost lives where two stages meet and no single-stage
measurement can see it. Measure the whole chain before believing a schedule.

## What this model does not include

Three gaps listed here previously are now closed and their results are above.
**The interpolator and the modulator are connected**, measured with real
24-bit PCM at all six rates, and the cascade costs 0.2 dB against the
modulator measured alone. **The datapath is sized**: 28-bit signal word flat
across the nine stages, 35/33/31-bit accumulators, ties to even. **The
low-frequency limit cycle did not exist**: it was the analysis window, the
loop is clean at idle down to -324 dBFS in the 20-100 Hz band, and the
measurement is fixed in `spectra.remove_dc` so it cannot recur.

What is still missing, in the order it is likely to matter:

**Programme material has now been run**, by `run_programme.py` against 16.7
seconds of real 48 kHz recording plus multitone and noise; see
`notes-programme.md`. Three things came back: 132.8 dB is a median and not a
bound, the error is worst in quiet passages, and the 3 dB headroom budget is
2.4 dB short of clipped material. All three are in the sections above.

**What programme material still has not tested is anything above 10 kHz.** The
real recordings available carry nothing up there, so 0010's warning that
high-level material above 20 kHz eats modulator headroom remains tested only by
the passband-edge rows in the headroom table. Intermodulation between a signal
and the ultrasonic content a 192 kHz source may carry is still untested. Real
material was also available at 48 kHz only -- the other five rates use
synthetic stand-ins with the right spectra and the wrong crest factors -- and
every figure except the element-draw table uses a single mismatch seed, which
spans 5.3 dB across five draws of the same one percent specification.

**The modulator's arithmetic is sized**, by `run_modarith.py`. Peak integrator
states are small, which is the CIFB-with-feedforward topology doing what its
docstring claims -- every integrator is driven by the loop error, not by the
signal, so the states never carry the audio:

| | Integrator 1 | Integrator 2 | Integrator 3 |
| --- | --- | --- | --- |
| 1 kHz tone at -3.7 dBFS, worst of six rates | 0.069 | 0.265 | 0.361 |
| Inter-sample content at its max stable level | 0.082 | 0.400 | 0.630 |

So the states need no integer bits beyond the sign over the range measured.
That is a starting point for sizing, not a size: how many fractional bits they
need, and what happens when the loop coefficients are truncated, is untested.

### Modulator word widths

| | Total bits | Sign | Integer | Fractional |
| --- | --- | --- | --- | --- |
| Feedback coefficients | 10 | 1 | 1 | 8 |
| Integrator 1 state | 28 | 1 | 1 | 26 |
| Integrators 2 and 3 | 20 | 1 | 1 | 18 |

**Only the first integrator needs a wide word, and that is the opposite of the
obvious guess.** Holding all three at 20 bits and widening one to 28 gains
42.3 dB if it is the first and 0.1 to 0.3 dB if it is either of the others.
Rounding at the first integrator is integrated twice more before it reaches the
quantizer, so it is amplified at low frequency; rounding at the last is not
integrated at all. Sizing per integrator rather than flat costs 68 bits of
state instead of 84.

**The integer bit is required, not margin.** Near the maximum stable input the
third integrator reaches between 0.8 and 1.13 depending on how the coefficients
round, so zero integer bits would overflow. One gives a range of plus or minus
two.

**The coefficients need far less than they are exported at.** Ten bits total
holds full performance, against the 24 in the export. The export is not wrong,
only generous; narrowing it is free if the multiplier size ever matters.

Checked against tones at 1, 6 and 19 kHz and against the inter-sample probe at
its maximum stable level, with no overflow in any case. Tones below about
200 Hz cannot be measured at this transform length, because at 23.4 Hz bins the
signal and its harmonics occupy the whole lower band; their peak states and
overflow counts are still valid.

### Volume goes at the modulator input

Measured at 96 kHz, order 3, comparing a digital gain applied at the chain
input against one applied after the interpolator:

| Attenuation | At the chain input | At the modulator input |
| --- | --- | --- |
| -6 dB | 140.3 dB | 140.3 dB |
| -20 dB | 138.7 dB | 140.2 dB |
| -40 dB | 123.9 dB | 134.2 dB |
| -60 dB | 104.2 dB | 114.6 dB |

Identical to about -6 dB, then late placement pulls ahead by roughly 10 dB.
What decides it is which noise sits downstream of the multiply. Applied at the
input, the interpolator's rounding is added after the attenuation and stays
fixed while the signal shrinks. Applied at the modulator input, that rounding
is attenuated along with the signal, and only the modulator's own quantization
noise stays put, which is 168 dB down and has room to spare.

**Cost: one multiplier at the element clock**, against the 2.86 the
interpolator already needs there. If that binds, the gain could be folded into
the final stage's coefficients instead, merging two multiplies into one, at the
price of wider coefficients and a glitch-free update on volume changes.

**A middle position was not measured.** The datapath analysis puts rounding at
stage 9 some 24 dB quieter in band than the same rounding at stage 1, so the
harm concentrates early and a gain after the first few stages should capture
most of the benefit at a far lower clock rate. Two attempts to measure it both
produced invalid numbers: splitting the cascade breaks the settling offset, and
compensating by taking the settled tail breaks the coherent FFT window. Only
the two endpoints above are trustworthy.

Also absent, as before: finite integrator gain, clock jitter, and the analog
reconstruction filter.

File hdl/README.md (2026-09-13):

# hdl

FPGA sources for the GateMate CCGM1A1. The FPGA is the DAC: it runs the
interpolator and the delta-sigma modulator and drives element lines directly.
See [0008](../docs/decisions/0008-multibit-delta-sigma-with-dwa.md).

- `rtl/` — synthesizable sources only.
- `constraints/` — pinout and timing. One file per board revision.
- `sim/` — cocotb testbenches and the Verilator runner.
- `build/` — Yosys and nextpnr output. Git-ignored.

## What exists

| Module | Role | Tests |
| --- | --- | --- |
| `lyrebird_tag_decode` | Decodes one bus word into a sample or a control word | 8 |
| `lyrebird_unpack` | Left/right framing, resync, lock state on top of it | 8 |
| `lyrebird_sim_stub_ft601q` | Test scaffolding, not design RTL | — |
| `lyrebird_sim_elem_dump` | Test scaffolding, not design RTL | — |

The two `sim_` modules exist so the bus model and the element sink have
something to drive. They are not part of the design and must not be extended
into it.

Still to write: the bus read master, the elastic buffer, the interpolator, the
modulator, the rotation, and the I2S-domain output. The model in
[../model/](../model/) carries the numbers the DSP blocks must be built
against, including fixed-point coefficient widths.

## Signal chain

```
FT601Q words ──> elastic buffer ──> interpolation ──> modulator ──> DWA ──> ELEM[27:0]
  66.67 MHz       hard-block FIFO     Fs to OSR*Fs     3-bit       rotation
                   async, 40K mode                     quantizer
```

## Clock domains

| Domain | Source | Contents |
| --- | --- | --- |
| 66.67 MHz | `CLK` from the FT601Q | FIFO read handshake, word unpacker |
| `MCLK` | Module oscillator, divided by two | Interpolator, modulator, DWA, element output |

Only two domains. The sample rate is a divided enable inside the `MCLK` domain
rather than a clock of its own, so the modulator and the sample tick share one
clock tree. At 24.576 MHz the oversampling ratio is 256 at 96 kHz and 512 at
48 kHz, which is ample for a modest modulator order.

`MCLK` arrives from the output module rather than from an oscillator on this
board. That is only safe because every element line is reclocked on the module
before it reaches a resistor, which removes this FPGA's clock jitter from the
output entirely. See
[0007](../docs/decisions/0007-two-board-split-at-i2s.md).

**The master clock changes frequency.** Switching between the 44.1 and 48 kHz
families switches which oscillator the module runs. Treat it as a
reconfiguration event: mute, drive the other enable, wait for settle, re-lock,
prefill, resume.

## Element output

Three-bit quantizer, thermometer coded, differential. For code k the modulator
asserts k of seven positive lines and seven minus k of the negative lines, so
exactly seven lines per channel are high at any code. That keeps the module's
reference loading constant, which is a distortion mechanism rather than a
nicety.

Dynamic element matching rotates which lines carry a given code, so element and
timing mismatch become high-frequency error the loop shapes out of band rather
than in-band distortion. The rotation state is part of the design; do not assume
a stable mapping from code to line.

The full line allocation is in [hardware/interface.md](../hardware/interface.md).

## Bus interface

245 Synchronous FIFO mode, one IN and one OUT channel. Signals are `CLK`,
`DATA[31:0]`, `BE[3:0]`, `RXF_N`, `TXE_N`, `RD_N`, `WR_N`, `OE_N`, `SIWU_N`.
Only the receive direction carries audio; the transmit direction is available
for status or control later.

## Wire format

One padded sample per bus word, with all four byte enables asserted. Four word
types, distinguished by the tag byte. See
[0010](../docs/decisions/0010-192khz-and-control-word.md).

| Tag | Direction | Payload |
| --- | --- | --- |
| `0xA5` | in | Left sample, 24-bit signed in `DATA[23:0]` |
| `0x5A` | in | Right sample, same |
| `0xC3` | in | Control: opcode in `DATA[23:16]`, payload in `DATA[15:0]` |
| `0x3C` | out | Status, on the transmit direction |

On a 32-bit bus with word-aligned transfers the interface preserves word
boundaries, so the single-dropped-byte failure mode that motivated the tags no
longer really applies. The tags stay because they recover L/R alignment if a
whole word is lost, and because they cost nothing. Require several consecutive
well-formed words before declaring lock, since real audio can contain the tag
values in the sample bits.

Control words are inline, so they take effect in stream order. `SET_RATE`
discards buffered audio, because samples already in the elastic buffer belong
to the old rate: mute, drain, reconfigure, prefill, resume.

## Sample rates

| Rate | Oscillator | Ratio | Half-band stages |
| --- | --- | --- | --- |
| 44.1 / 88.2 / 176.4 kHz | 22.5792 MHz | 512 / 256 / 128 | 9 / 8 / 7 |
| 48 / 96 / 192 kHz | 24.576 MHz | 512 / 256 / 128 | 9 / 8 / 7 |

The modulator always runs at the oscillator rate, so noise shaping is fixed in
absolute frequency and audible-band performance does not vary with sample rate.
Only the interpolator changes.

### Selecting the rate

The host sends a `SET_RATE` control word. The control plane decodes it and
drives one multiplexer in front of each stage; a stage has no bypass of its
own and does not know which rate is running.

**Every stage has one fixed rate pair, whatever the input rate.** Stage 3 takes
192 kHz in and 384 kHz out at 48, 96 and 192 kHz alike. Only the source of its
input changes: the previous stage's output, or the incoming samples. That is
what makes a multiplexer in front sufficient, and it is why the stages could be
built independently.

| Rate | Stages | Enters at | Muxes fed from the stream |
| --- | --- | --- | --- |
| 48 kHz | 9 | stage 1 | stage 1 |
| 96 kHz | 8 | stage 2 | stage 2 |
| 192 kHz | 7 | stage 3 | stage 3 |

The multiplier field of the rate payload is the select directly: entry stage is
one plus the multiplier, so no decode table is needed. See
[0010](../docs/decisions/0010-192khz-and-control-word.md).

**Hold the stages upstream of the entry point in reset.** At 192 kHz stages 1
and 2 have no valid input. Their outputs are not selected, so they cannot
corrupt the audio, but stale state left in their delay lines would be heard on
a later change down to 48 kHz. Reset is cheaper than reasoning about it.

Changing rate within a family needs no oscillator settling; crossing families
does.

Volume is digital and lives here, applied inside the interpolation chain at
full internal precision rather than to the incoming PCM, so truncation lands at
the modulator input where it is shaped.

## The elastic buffer

Every GateMate block RAM has a hardware FIFO controller that runs in
asynchronous mode, with the write and read ports on separate clocks, full,
empty, almost-full and almost-empty flags, and exposed pointers. That is the
clock-domain crossing and the prefill threshold as a hard block rather than
fabric to write and verify. It requires the 40K configuration.

Prefill absorbs host scheduling jitter, which is a time-domain problem, so the
buffer is sized in milliseconds and the sample count scales with rate. Size for
the worst case. SDP 40K mode, 80 bits wide, three 24-bit samples per word, per
[0011](../docs/decisions/0011-pack-three-samples-per-fifo-word.md):

| Prefill | 96 kHz | 192 kHz |
| --- | --- | --- |
| 50 ms | 7 blocks | 13 blocks |
| 100 ms | 13 blocks | 25 blocks |

Thirty-two blocks exist, so the specified 100 ms at 192 kHz uses 25 and leaves
7 spare. Committing every block would reach 128 ms at 192 kHz. Interpolator
delay lines and coefficients come to well under one block.

Read granularity is three samples, so the Fs side reads a word every third
sample tick and tracks left/right by counter rather than by word boundary.

## Resources

Logic is not close to binding. Modulator coefficients are shifts and adds rather
than multipliers, and the early interpolation stages run at a few hundred
kilohertz, so one multiplier can be time-shared across many taps.

## Verification

Verilator with cocotb. See
[0013](../docs/decisions/0013-simulation-and-build-toolchain.md).

```
python hdl/sim/run.py              # every suite
python hdl/sim/run.py tag_decode   # one suite
WAVES=1 python hdl/sim/run.py      # dump FST waveforms
```

Sources are SystemVerilog restricted to the subset Yosys accepts: `logic`,
`always_ff`, `always_comb`, `localparam`. No interfaces, no packed structs.
Verilator would take more, but the same files have to synthesise.

**Two tiers, deliberately.** Functional tests live in cocotb: protocol
handshakes, tag resync, control word decoding, underrun behaviour, the lock
state machine. Short, event-driven, and far easier in Python than in an HDL
testbench.

The audio measurement does not use cocotb. Reading 28 element lines from Python
every cycle makes the binding the bottleneck rather than the simulator. Dump
the element lines from the simulation and analyse them in numpy afterwards,
which means you simulate once and analyse many times. Testing the rotation
against a dozen mismatch distributions then costs one simulation rather than
twelve.

The measurement itself: sum the element lines exactly as the resistors will,
take an FFT, and read in-band signal-to-noise and distortion. Deliberately
mismatch the weights to confirm the rotation converts that into out-of-band
noise rather than in-band distortion. Separately, drive word drops on the
bridge side to exercise tag resync.

**Verilator is two-state**, so it will not show X propagation and will happily
simulate a design whose reset is incomplete. Do not rely on it to catch
uninitialised state.

## Build

```
tools/synth.sh <toplevel> [sources...]
```

Yosys with `synth_gatemate`, then nextpnr-himbaechel. The script stops after
synthesis with a message when place-and-route is unavailable, which keeps it
useful for resource counts.

## Clock routing, and the one pinout constraint

The global mesh is driven from a mux fed by the PLL block, so a clock does not
reach it by an independent route. The bypass path exists and the open toolchain
uses it automatically, but not through the port the datasheet suggests.

**The recipe.** Put the clock on one of the four dedicated clock-capable pins,
`CLK0` to `CLK3`, instantiate a `CC_BUFG` driven by that pad, and do not
instantiate a PLL on it. nextpnr sees the pad is clock-capable and wires the
CLKIN reference straight into the GLBOUT mux, so the clock reaches the global
mesh without passing through the VCO.

**The trap.** `CC_PLL` declares a `CLK_REF_OUT` port, matching the datasheet,
but nextpnr rejects it outright: *"Output CLK_REF_OUT cannot be used if PLL is
used."* The bypass belongs to the CLKIN-to-GLBOUT path, not to a configured
PLL. Do not try to reach it that way.

**The constraint this puts on the pinout.** If the clock lands on an ordinary
pin rather than a clock-capable one, the packer silently falls back to routing
it through the fabric as a user global, which adds exactly the jitter the
bypass avoids. It is not an error, so nothing will tell you. Both `MCLK` and
the FT601Q clock must be assigned to dedicated clock pins.

**No PLL is needed anywhere in this design.** Neither clock requires frequency
synthesis, since the sample rate is a divided enable inside the `MCLK` domain
rather than a clock of its own. All four PLLs stay unused and both clocks
bypass straight to the mesh.

Verified against the Yosys GateMate blackbox library and the nextpnr GateMate
clock packer, not just the datasheet.

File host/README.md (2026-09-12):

# host

PC-side driver. The FT601Q does not enumerate as a USB Audio Class device, so
the OS will not offer it as an output. This program opens a **D3XX** handle and
writes raw PCM.

- `src/` — implementation
- `include/` — public headers

D3XX is the FT60x-family library, not the D2XX used by the older FT2232H. The
two APIs are not interchangeable.

## Contract

Write 32-bit words, little-endian, tag byte in the most significant position.
Samples alternate channels. The FPGA hunts for a valid tag if alignment is
lost. Full protocol in
[0010](../docs/decisions/0010-192khz-and-control-word.md).

| Tag | Direction | Payload |
| --- | --- | --- |
| `0xA5` | write | Left sample, 24-bit signed |
| `0x5A` | write | Right sample |
| `0xC3` | write | Control: opcode, then payload |
| `0x3C` | read | Status |

Control words are inline with audio and take effect in stream order. Opcodes
cover rate selection, volume, mute and reset.

**A rate change discards buffered audio.** Send `SET_RATE`, expect a gap while
the FPGA drains and prefills, then resume writing. Changing rate within a
family is quicker than crossing between the 44.1 and 48 kHz families, because
no oscillator has to settle.

**Read the status word to learn what is attached.** It reports current rate,
buffer fill, underrun and overrun counts, lock state, and the module ID
strapped on the mezzanine, which is how the host discovers whether a headphone
module is present.

## Throughput

2ch / 24-bit / 192 kHz padded to 32 bits is 1.54 MB/s, against a bus capable of
hundreds of MB/s. Bandwidth is not the constraint and never will be. Host
scheduling jitter is the only thing that can cause an underrun, and the FPGA's
prefill exists to absorb it.

Use large writes and keep several in flight so the pipe never drains.

## Sources

Bench bring-up reads a WAV file and pumps it. Real playback captures a loopback
device: a PipeWire null sink plus its monitor source on Linux, WASAPI loopback
or VB-Cable on Windows.

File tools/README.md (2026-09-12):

# tools

Build, program, and bring-up scripts.

Planned entry points:

- synthesis and place-and-route through Yosys and nextpnr-himbaechel
- SPI flash programming over the separate programming header, driven by
  openFPGALoader and an external FTDI adapter. The FPGA loads itself from flash
  at reset in SPI Active mode, so normal operation needs no programmer. See
  [0006](../docs/decisions/0006-configuration-from-spi-flash.md)
- cocotb test runner, including the modulator quality measurement described in
  [hdl/README.md](../hdl/README.md)
- host driver build against D3XX

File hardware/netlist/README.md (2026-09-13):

# netlist

Schematic as code. The two boards are described in Python and emit KiCad
netlists, which import into a PCB to start layout.

```
export KICAD10_SYMBOL_DIR="/Applications/KiCad/KiCad.app/Contents/SharedSupport/symbols"
../../.venv/bin/python main_board.py
../../.venv/bin/python output_module.py
```

Outputs land beside each board project, as `.net` for KiCad and `.xml` for
tooling.

Parts the stock libraries do not carry live in `../symbols/lyrebird.kicad_sym`,
which the generator adds to the search path itself. It holds two symbols so
far, both with pinouts taken from the manufacturer datasheet:

| Symbol | Part | Source |
| --- | --- | --- |
| `LTM4622` | LTM4622IV#PBF, LGA-25 | Datasheet Rev J, PIN FUNCTIONS |
| `MX25R6435F` | MX25R6435FM2IH0, SOP-8 | Standard serial NOR pinout |

The LTM4622 still needs a footprint drawn; its `Footprint` field names
`lyrebird:Analog_LGA-25_6.25x6.25mm_Layout5x5_P1.27mm`, which does not exist
yet. It is a 5x5 grid on 1.27 mm, but the pad size is a manufacturer number
and is not worth guessing.

## Why this rather than drawing it

Two reasons specific to this project.

The GateMate is a 324-ball part whose symbol already carries the full ball map
and bank membership. Assigning 42 bus signals and 32 element lines by hand, to
the right banks, is exactly the kind of work that produces a quiet error. Here
the allocation is a loop over pools drawn from the symbol, so a pin cannot be
used twice and a bank cannot be silently overfilled.

More importantly, the constraint that fails silently is checkable. A clock on
an ordinary pin is not an error in the FPGA toolchain: the packer routes it
through the fabric and adds the jitter the bypass path exists to avoid, with no
warning. Because the netlist is generated, that assignment is asserted rather
than hoped for, and the generated netlist confirms both clocks land on
clock-capable balls.

## What is real and what is not

Stock KiCad 10 libraries carry almost everything, including a Cologne Chip
GateMate library, which removed the obstacle I expected to dominate this work.

**Real parts, real pinouts:** GateMate CCGM1A1, FT601Q, LTM4622, LT3045,
LT3094, 74AVC4T245, MX25R6435F, the USB 3.0 receptacle, the crystal, the
ferrite, and the resistor arrays.

**Placeholder symbols**, marked in the source, with the intended part in the
value field:

| Placeholder | Intended part | Why it is a placeholder |
| --- | --- | --- |
| `ASE-xxxMHz` | Crystek CCHD-957 | Same 4-pin enable/ground/output/supply pinout, different footprint |
| `74AUP1G74` | Low-jitter fanout divider | Part never selected |
| `74HCT574` pairs | One 16-bit register per channel | No 16-bit symbol in stock libraries; a custom one is needed |
| `OPA1612AxD` | Output op amp | Part never selected |

The 16-bit register substitution is the one that matters. Decision 0012 calls
for a single package per channel so both polarities share a die, because
even-order cancellation depends on the two sides matching. Two octal parts give
the same connectivity but not that property, so the symbol has to be made
before this is a real schematic.

## The absolute maximum is asserted, not reviewed

GateMate GPIO are LVCMOS to 2.5 V with an absolute maximum VDDIO of 2.75 V,
and the mezzanine carries 2.5 V logic by contract. Both boards had shipped a
netlist where a 3.3 V module signal reached a header pin, so
`lp.assert_below_abs_max` now fails the build instead.

It works out which nets can carry more than 2.75 V, from a declared list of
rails plus anything driven by a part whose every supply sits on one of them,
and then checks that no such net reaches an FPGA signal pin or a header pin.
The header is allowed `+5V`, which `interface.md` hands to the module on
purpose.

Two distinctions make it usable rather than noisy. A part with any supply at
or below the limit is a deliberate domain crossing, not a hazard: that is the
FT601Q with `VCCIO` at 2.5 V and the 74AVC4T245 with `VCC(A)` at 2.5 V, which
are exactly the parts the design uses to get across the boundary. And an
input pin is not a source, which is what lets the 28 element lines land on
3.3 V register inputs legitimately, a threshold question rather than a
damage one.

It catches, as of now: the element clock reaching `MCLK` without passing
through the translator, `ID0` strapped to the 3.3 V reference rail, and a
3.3 V pull-up landing on any header signal.

## Bank allocation

Drawn from the symbol, not invented.

| Purpose | Banks | Count |
| --- | --- | --- |
| Bridge FIFO bus | NA, NB, EA | 42 signals |
| Element lines | SA, WB | 32 provisioned |
| Mezzanine control | WC | 5 |
| Clocks | SB | 2 of 4 clock-capable pins |
| Flash and JTAG | WA | dedicated second functions |

All banks sit at 2.5 V. The bridge interface and the element outputs are kept
in separate banks: same voltage, but no shared bank supply.

Every clock-capable pin on this part lives in bank SB, which is worth knowing
before laying out, since it fixes where both clocks must enter.

## PCB and schematic generation: tried, does not work here

SKiDL exposes `generate_pcb` and `generate_schematic` alongside the netlist
generator. Both were run against the main board and neither completed: they
spawned several processes and produced no file after minutes on the 324-ball
part, and had to be killed.

So the flow stops at the netlist. Import it into a KiCad board to begin
layout, which is the step that actually needs a person: ball escape on a
324-ball package, USB 3.0 differential pairs with controlled impedance, and a
precision analog section are not auto-placeable in any useful sense.

## Why the flash is 64 Mbit

[0013](../../docs/decisions/0013-simulation-and-build-toolchain.md) measured
97,566 bytes at 94 `CPE_LT` and 184,050 bytes at 290, so the bitstream tracks
utilisation rather than being a flat image. A straight line through those two
points is about 441 bytes per `CPE_LT` over a 56 kB fixed part. The real
design adds an interpolator, a modulator, the rotation and the elastic
buffer; at a few thousand CPEs that line predicts megabytes, and 2 Mbit is
not in the conversation.

The decisive argument is not the extrapolation, though. Cologne Chip's own
evaluation board for this die fits 64 Mbit, and the Trenz TEG2000 module fits
128 Mbit. Taking the vendor's own number for the same part is better evidence
than a two-point fit, and 64 Mbit is also about 43 times the largest figure
actually measured here.

**MX25R6435F**, the part on Cologne Chip's board. Its 1.65 to 3.6 V supply
range is what makes it usable: `VDD_WA` is 2.5 V here, and the ordinary 2.7
to 3.6 V flash parts cannot run there.

## Known gaps

The mezzanine header came out at 2x40. Thirty-two element lines each beside a
ground is 64 pins before control and power, and the spare pins become
additional ground and supply rather than being left open.

The element resistor value is still a placeholder, and so are the four
symbols above.

Pins left open on purpose, so they are not mistaken for oversights:

| Pin | Why |
| --- | --- |
| FT601Q `Reserved` | Datasheet says do not connect |
| GateMate SerDes, `NC` | SerDes unused; its supplies share the core rail |
| GateMate `SPI_FWD` | Only used when several FPGAs chain off one flash |
| Unused GateMate bank I/O | EB, and the remainder of EA, SB, WB, WC |
| USB `ID` | Device port, not OTG |
| LTM4622 `COMP1`/`COMP2` | Internally compensated, "do not drive this pin" |
| LTM4622 `INTVCC` | Internally decoupled, no external capacitor needed |
| LT3045 `PG` | Open-collector flag, unused |

Still genuinely open on the module, both waiting on parts nobody has chosen:
the LT3094's input, which needs the charge pump from
[0009](../../docs/decisions/0009-usb-bus-power.md), and the op amp's own
pins. The divider placeholder is also not wired as a divider, because the
real part is a fanout divider with a different pinout entirely.

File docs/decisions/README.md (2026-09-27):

# Architecture decisions

One file per decision, numbered, never rewritten. If a decision is reversed,
add a new record that supersedes the old one and leave the original in place.
The reasoning is worth more than the conclusion.

What is *not* decided lives in [../open-items.md](../open-items.md).

| # | Decision |
| --- | --- |
| [0001](0001-ftdi-bridge-over-ulpi-phy.md) | FTDI bridge instead of a ULPI PHY. Part selection superseded by 0005 |
| [0002](0002-fpga-owns-the-audio-clock.md) | The FPGA owns the audio clock. Oscillator placement refined by 0007 — **corrected**: the frequencies named are the element clock, and the FIFO size predates 0011  |
| [0003](0003-self-describing-sample-framing.md) | Self-describing sample framing. Rationale revised by 0005 |
| [0004](0004-defer-usb-audio-class.md) | Defer USB Audio Class support |
| [0005](0005-ft601q-bridge-io-voltage.md) | FT601Q bridge, forced by GateMate I/O voltage — **amended by 0014**: High Speed, not SuperSpeed  |
| [0006](0006-configuration-from-spi-flash.md) | Configure from SPI flash, program over a separate header |
| [0007](0007-two-board-split-at-i2s.md) | Two boards, split at I2S. Reasoning now depends on 0008's reclocker — **contradicted in detail by 0008**: the boundary is element lines, not I2S  |
| [0008](0008-multibit-delta-sigma-with-dwa.md) | Multi-bit delta-sigma with dynamic element matching. No DAC chip |
| [0009](0009-usb-bus-power.md) | USB bus power, and which rails are precision — **superseded by 0014** |
| [0010](0010-192khz-and-control-word.md) | 192 kHz support and an in-band control word. Buffer sizing corrected by 0011 |
| [0011](0011-pack-three-samples-per-fifo-word.md) | Pack three samples per 80-bit FIFO word |
| [0012](0012-module-clock-architecture.md) | Module clock architecture and a 3.3 V element rail. Supersedes 0008's 2.5 V rail — **amended**: divider and fanout chosen, analog rails moved by 0015  |
| [0013](0013-simulation-and-build-toolchain.md) | Simulation and build toolchain. Verilator with cocotb, Yosys, KiCad — **corrected**: git-lfs contradiction, bitstream figures stale  |
| [0014](0014-wall-wart-power.md) | External 12 V supply, USB for data only. Supersedes 0009 |
| [0015](0015-negative-rail-across-the-mezzanine.md) | The negative analog rail crosses the mezzanine; the module loses its charge pump. Completes 0014 |

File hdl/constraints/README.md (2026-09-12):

# constraints

GateMate pin constraints, in Cologne Chip's CCF format. One file per toplevel,
named `<toplevel>.ccf`, picked up automatically by `tools/synth.sh`.

Place-and-route **refuses to run without one**, unless overridden. The override
exists for resource counts and is never valid for hardware, since I/O would be
placed wherever the tool felt like.

## The one that will bite silently

Clocks must be assigned to the dedicated clock-capable pins, `CLK0` through
`CLK3`. A clock on an ordinary pin is not an error: the packer quietly falls
back to routing it through the fabric as a user global signal, which adds
exactly the jitter the PLL bypass path exists to avoid, and nothing warns you.

Both `MCLK` and the FT601Q bus clock therefore need explicit clock-pin
assignments here. See the clocking section of
[../README.md](../README.md) and
[0012](../../docs/decisions/0012-module-clock-architecture.md).

## Bank voltages

GPIO banks are independently supplied. The element output lines and the bridge
interface should not share a bank, per
[../../hardware/README.md](../../hardware/README.md). Nothing on this part
tolerates more than 2.75 V.

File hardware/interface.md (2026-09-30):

# Mezzanine interface contract

The boundary between the main board and the output module, per
[0007](../docs/decisions/0007-two-board-split-at-i2s.md) and
[0008](../docs/decisions/0008-multibit-delta-sigma-with-dwa.md). Both boards
must honour this. It is provisional until the first layout fixes a connector.

There is no DAC chip. The FPGA runs the modulator and drives element lines; the
module reclocks them, sums them through matched resistors, and filters the
result.

## Signals

| Signal | Direction | Purpose |
| --- | --- | --- |
| `MCLK` | module to main | Element clock, the enabled oscillator divided by two |
| `ELEM[31:0]` | main to module | Thermometer element lines, see allocation below |
| `OSC_EN_441` | main to module | Enable the 45.1584 MHz oscillator (22.5792 MHz element clock) |
| `OSC_EN_48` | main to module | Enable the 49.152 MHz oscillator (24.576 MHz element clock) |
| `MUTE_N` | main to module | Mute the analog output stage |
| `ID0`, `ID1` | module to main | Module type, strapped on the module |
| `+5V` | main to module | 5.02 V from the main board's buck, for the module's regulators |
| `-6V_A` | main to module | −5.98 V, two pins (73/74), for the module's negative analog rail |
| `GND` | — | Interleaved between signals |

## Element allocation

Thirty-two lines are provisioned; a three-bit differential stereo module uses
28. The rest are reserved so element count can change without touching the main
board or the connector.

| Lines | Use |
| --- | --- |
| `ELEM[6:0]` | Left channel, positive side |
| `ELEM[13:7]` | Left channel, negative side |
| `ELEM[20:14]` | Right channel, positive side |
| `ELEM[27:21]` | Right channel, negative side |
| `ELEM[31:28]` | Reserved. Driven low by the main board |

For code k on a given side, the main board asserts k of the seven positive lines
and seven minus k of the negative lines, so exactly seven lines per channel are
high at any code. Which specific lines carry the code is chosen by the dynamic
element matching rotation and must not be assumed stable.

## Rules

**The negative rail is flanked by ground, deliberately.** `-6V_A` occupies
pins 73 and 74 — one column of a 2×40 odd/even header — with full ground
columns at 71/72 and 75/76 either side. The pair is adjacent to itself so a
half-inserted connector cannot present one pin without the other, and isolated
from the control block because that block has no ground pin inside it: MCLK,
both oscillator enables, `MUTE_N` and both ID straps run from pin 65 to 70 with
returns only at either end. A bridge or a whisker across 1.27 mm from `ID1`
would otherwise put −6 V on a net that reaches a GateMate GPIO through nothing
but a 10 kΩ pull-down, with the input's clamp diode conducting and the current
limited only by the bridge. Three pins came out of `+5V`, which drops from
five to two, and ground went **up** from 37 to 38 — an earlier version of this
paragraph said four pins came out of a ground surplus, which is backwards.

**Logic levels on the header are 2.5 V.** This is set by the GateMate GPIO
banks, which are LVCMOS up to 2.5 V and are not 3.3 V tolerant. See
[0005](../docs/decisions/0005-ft601q-bridge-io-voltage.md). Nothing on the main
board is safe above 2.75 V.

**The module's own domain is 3.3 V**, including the oscillators, the clock
chain and the element reference rail. A translator on the module converts
`MCLK`, `OSC_EN_441` and `OSC_EN_48` at the boundary. It lives on the module
side deliberately, so the mezzanine never carries 3.3 V. The element lines are
not translated; the registers' input threshold accepts 2.5 V directly. See
[0012](../docs/decisions/0012-module-clock-architecture.md).

**Every element line is reclocked on the module** before it reaches a resistor,
by a flip-flop clocked from the module oscillator and powered from the reference
rail. This is what removes the FPGA's clock jitter and supply noise from the
output, and it is the reason the oscillator may stay on the module at all.
Nothing on the main board should be treated as analog-grade.

**Keep reclock skew tight.** Timing mismatch between flip-flop packages behaves
like element mismatch. The rotation scrambles it, but it is cheaper not to
create it.

**Every element line sits adjacent to a ground pin.** Element return currents
are the analog signal.

**Exactly one oscillator runs at a time**, and this is still a rule rather
than a guarantee — an earlier version of this paragraph claimed it was
enforced, and it is not. The main board enables the family it needs; a module fitted
with only one family ignores the other enable and straps its ID accordingly.

The rule matters because a module may share one output net between two
oscillators, which is legal only while exactly one is enabled — the CCHD-957
tri-states its output in standby, so an idle part neither drives nor radiates.
It used to be a rule with nothing behind it: both enables floated before the
FPGA was configured, and an open E/D pin on that part *runs*, so both
oscillators could start and drive the shared net into each other. **Both boards
now pull the enables down** — the main board because the floating input is on
its side of the translator, the module as well because a pull-down there only
decides the case where the translator's output is high impedance.

**The module regulates its own rails** from the +5V and −6V it is handed. Only
the negative rail comes in pre-inverted: the output stage needs about 3.5 V on
the positive side and the header's 5 V covers it, so a module needs no
bipolar converter of its own. A module that wants more than the main board's
inverter delivers should take its own supply input (0009 defers that case for a
headphone stage).

**The element reference rail is the critical one**: it sets full scale, so it
multiplies the signal, and it carries the elements' own switching current.

**A correction to what this document used to promise.** It said the
constant-current property of differential thermometer drive keeps that load
signal-independent, and that heavy local decoupling handles the rest. Both
halves are wrong in a way a module designer would act on:

- 0008 guarantees exactly seven of fourteen elements high at every code, so the
  **DC** load is constant. It guarantees nothing about how often lines
  *change*, and the element filter capacitors and the registers both draw
  current in proportion to that. Because the DWA pointer advances by the code,
  the count of changing lines is a full-wave rectification of it, which puts a
  signal-correlated current on the rail.
- Decoupling does not answer that, because the disturbance is at twice the
  signal frequency and at the programme envelope rather than at the switching
  rate. Eight 100 nF parts are about 100 Ω where it lives; reaching the chain's
  own noise floor would need 170 µΩ at 2 kHz.

Predicted at −101.1 dBFS against a chain held to −136.5. It is the project's
lead open item, it is a prediction from a digital proxy rather than a
measurement, and it wants a bench. See
[docs/open-items.md](../docs/open-items.md).

**There is no declared current budget any more.** This section used to require
the module to stay inside a figure fixed in the USB descriptor at enumeration.
0014 replaced bus power with a 12 V supply, so nothing is negotiated and the
constraint is simply what the main board's converters deliver.

## Module identification

`ID0` and `ID1` are strapped on the module and read by the FPGA.

| ID1 | ID0 | Module |
| --- | --- | --- |
| 0 | 0 | No module fitted, pins pulled low on the main board |
| 0 | 1 | Line output only |
| 1 | 0 | Headphone output only |
| 1 | 1 | Combined line and headphone |

The oscillator complement is not encoded here. A module that lacks a family
never asserts a clock when that enable is driven, and the main board treats the
missing clock as an unsupported rate.

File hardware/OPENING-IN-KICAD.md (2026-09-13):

# Opening this in KiCad

The boards are described as code, so nothing here was drawn by hand. Both a
**schematic** and a **board** are generated from the netlist, and both open in
KiCad.

## To review the circuitry, open the schematic

**Start with the PDF.** Each board has a multi-page one beside it, a page per
functional block:

- `lyrebird-main-reva/lyrebird-main-schematic.pdf` — 8 pages
- `lyrebird-dac-reva/lyrebird-dac-schematic.pdf` — 6 pages

The individual sheets are in each board's `sheets/` directory if you want them
in the editor. A single all-in-one sheet also exists as
`lyrebird-main.kicad_sch` and `lyrebird-dac.kicad_sch`.

### How the pages are chosen

A sheet is anchored on each major part, meaning anything with eight or more
pins, and every other part joins the major part it belongs with. Association
is by shared net, ignoring ground because it touches everything and associates
nothing. A part touching only supply rails, which is most decoupling, joins
the owner of its rail: the major part with the most pins on it. Without that
rule a bypass capacitor lands with whatever happens to share its rail, which
put 55 parts on the programming header.

Page names come from the generators' own section comments where the part was
created there, and from the part's value where it came from the shared parts
library. Regenerate with:

```sh
./.venv/bin/python tools/netlist_to_sheets.py \
    hardware/lyrebird-main-reva/lyrebird-main.net \
    hardware/lyrebird-main-reva/sheets
```

Every part appears as its real symbol with its reference and value.

**Nets of two or three pins are drawn as wires**, and parts sharing one are
placed next to each other so the wire is short. 119 of the main board's 125
nets and 68 of the module's 82 are wired this way. Only ground, the supply
rails and the element bus stay as labels, which is what a person does by hand:
nobody draws a wire joining 245 ground pins.

There is no global routing, which is the part that cannot be automated and
where SKiDL's own schematic generator hangs on the 324-ball part. Two-pin nets
route as an L, three-pin nets as a comb to a shared vertical.

**Layout is packed to roughly a square rather than run out in a strip.** Each
cluster is arranged as a compact block, and the blocks are shelf-packed to
about the proportions of a sheet of paper. The main board reads as 663 by
706 mm across 14 bands; laid out as a single row it was 1765 mm wide across
five, which is not something anyone can follow.

Regenerate after the netlist changes:

```sh
./.venv/bin/python tools/netlist_to_schematic.py \
    hardware/lyrebird-main-reva/lyrebird-main.net \
    hardware/lyrebird-main-reva/lyrebird-main.kicad_sch
```

A PDF of each is committed beside its board, and regenerates with:

```sh
/Applications/KiCad/KiCad.app/Contents/MacOS/kicad-cli sch export pdf \
    --output hardware/lyrebird-main-reva/lyrebird-main-schematic.pdf \
    hardware/lyrebird-main-reva/lyrebird-main.kicad_sch
```

The netlist stays the source of truth. The schematic is generated for reading,
so edits to it will be overwritten.

What you can open is a **board**, generated from the netlist. Both already
exist:
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

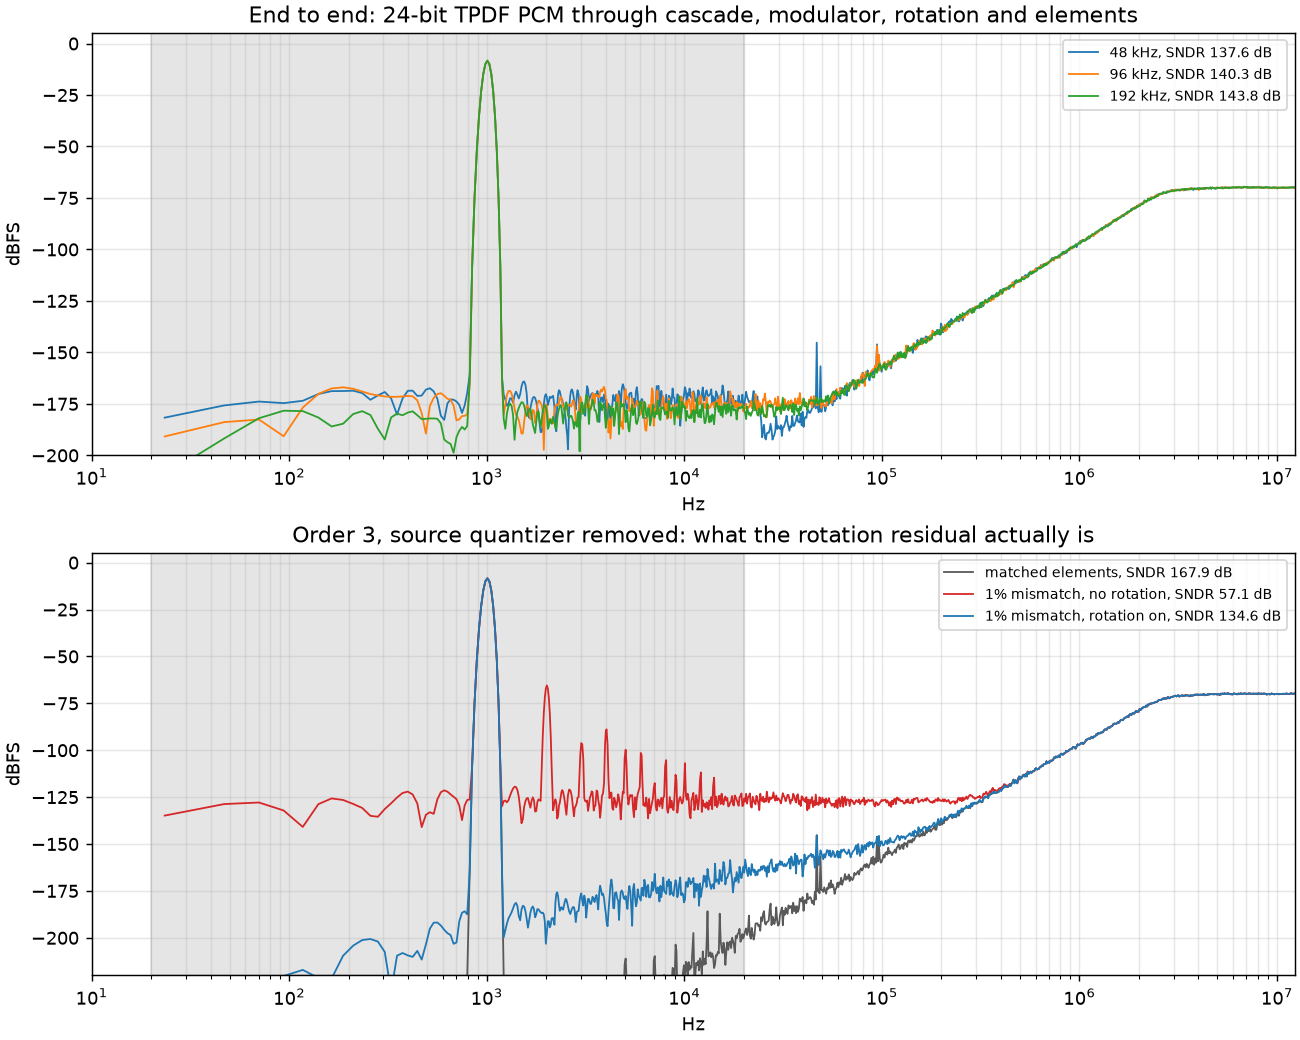
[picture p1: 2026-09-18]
model/figures/endtoend_spectrum.png

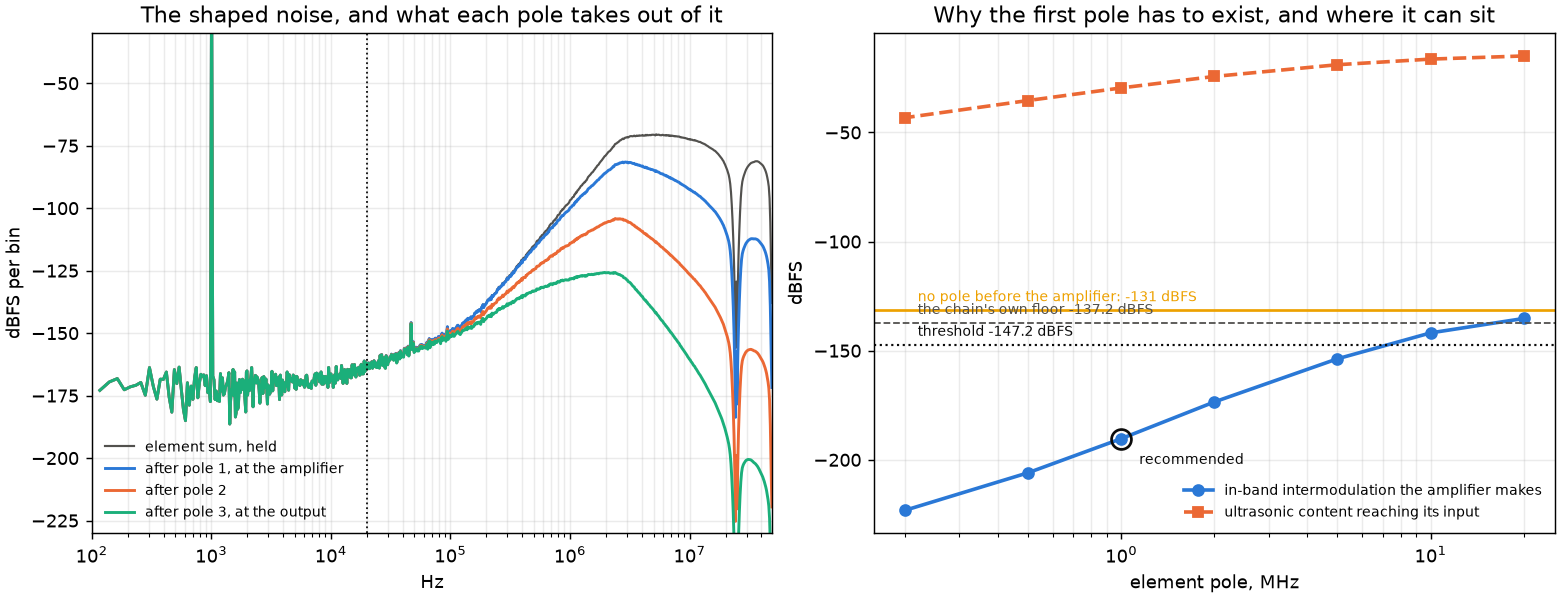
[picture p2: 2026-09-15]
model/figures/analog_filter.png

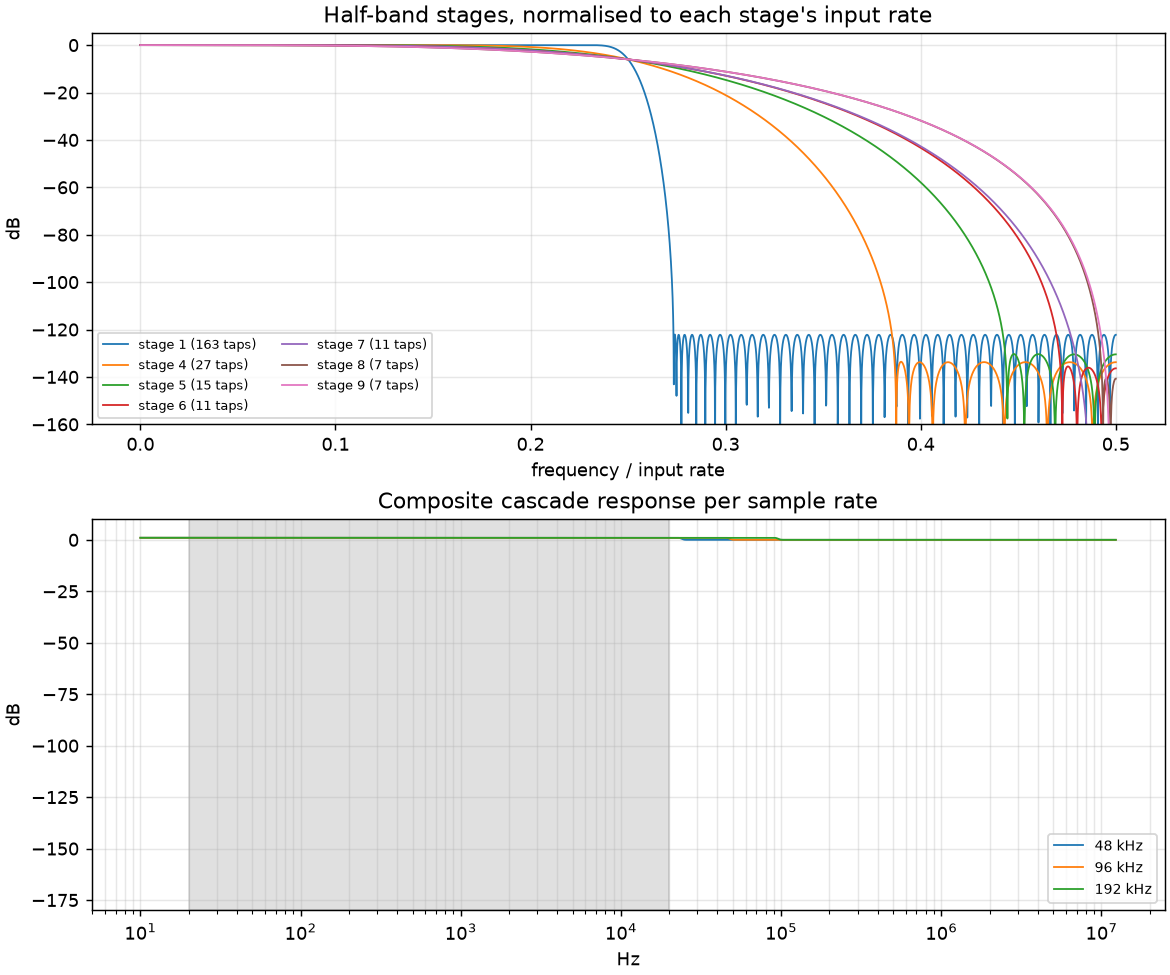
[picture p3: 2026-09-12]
model/figures/interpolation.png

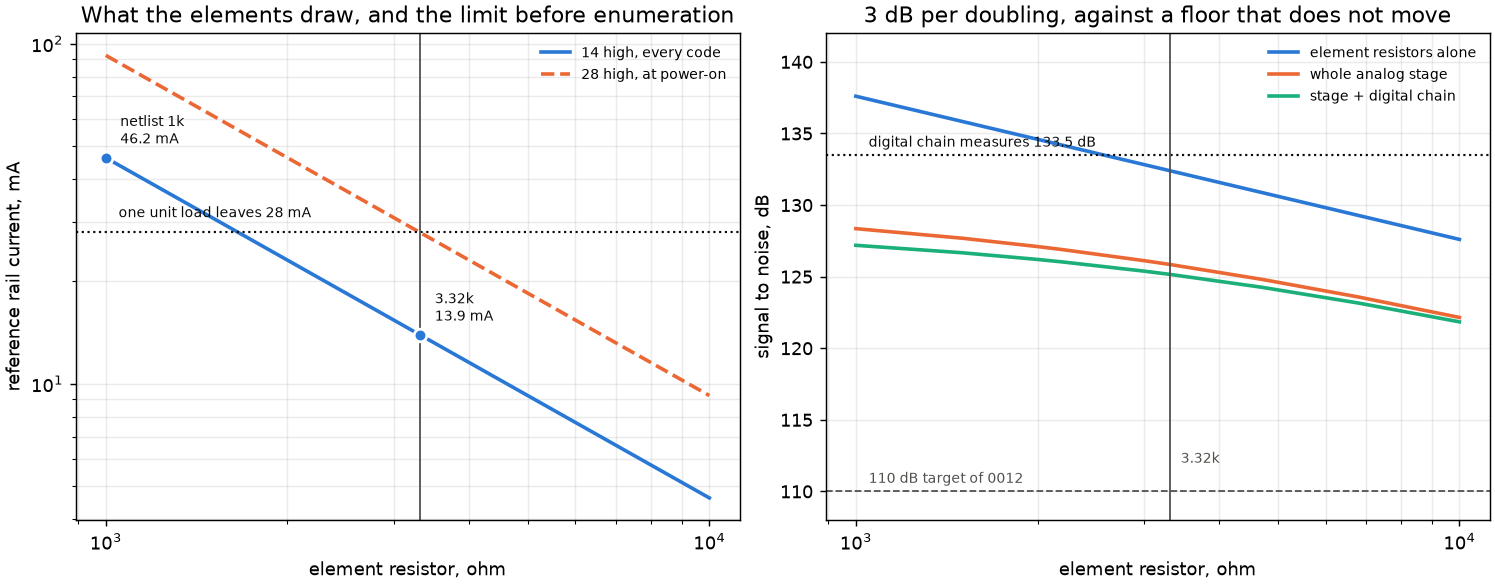
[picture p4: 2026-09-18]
model/figures/analog_resistor.png

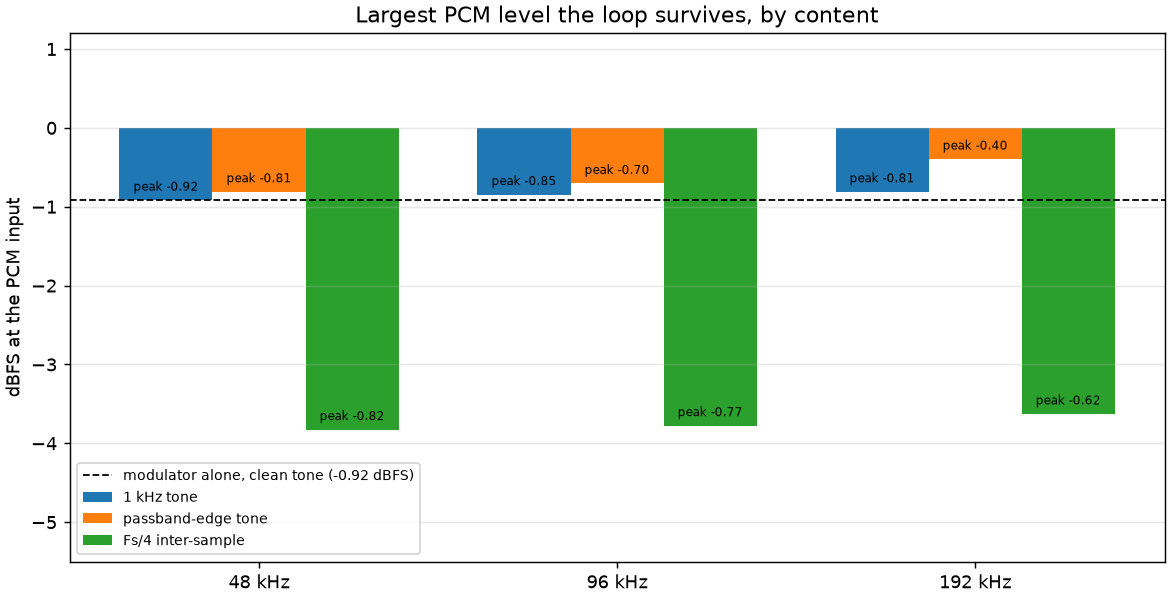
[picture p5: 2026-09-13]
model/figures/endtoend_headroom.png

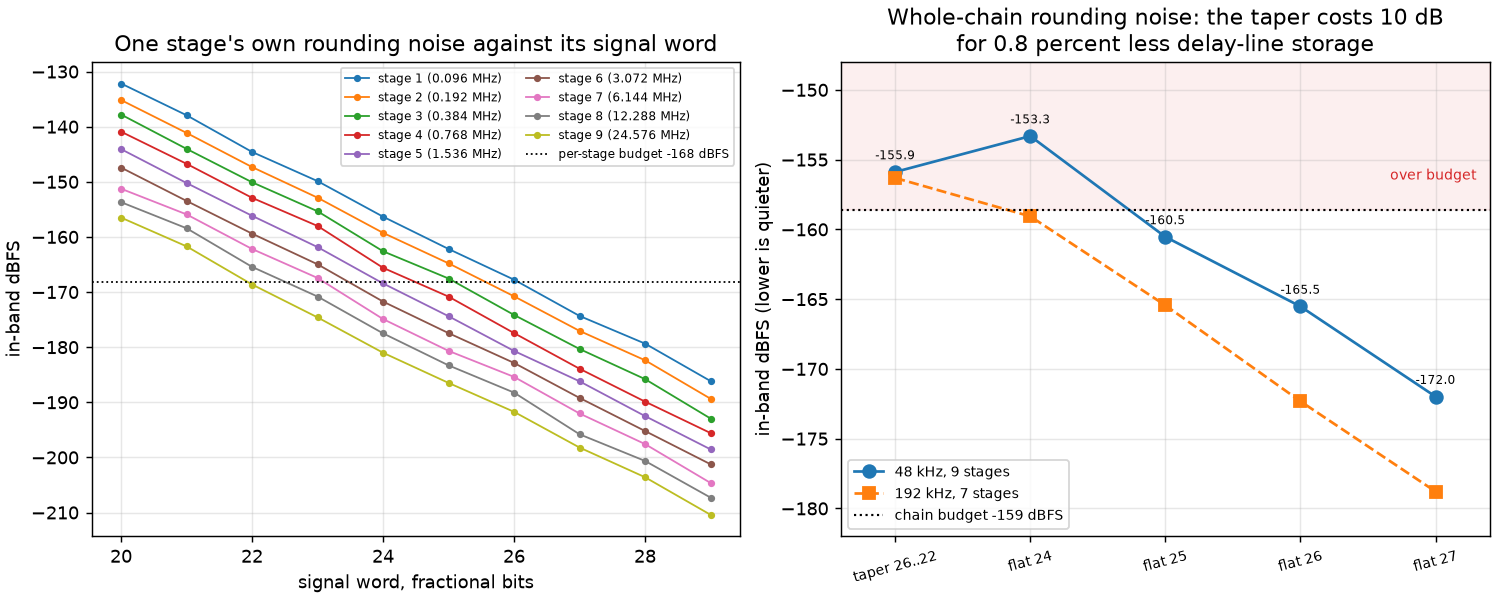
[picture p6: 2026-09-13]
model/figures/datapath_widths.png

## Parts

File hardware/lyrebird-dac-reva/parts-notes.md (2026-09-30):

# lyrebird-dac-reva — part selections

Every part the module was missing, why it was chosen, and what was verified
against a datasheet rather than assumed. The netlist that carries these is
[../netlist/output_module.py](../netlist/output_module.py); the numbers they
are chosen against are [model/results/analog.txt](../../model/results/analog.txt)
and the decisions in [docs/decisions](../../docs/decisions).

**Where a specification could not be verified it says so.** Nothing here is a
manufacturer part number that was not read off a datasheet.

## Output op amp — OPA1612AID (U7, U10, U11)

Texas Instruments OPA1612, dual, SOIC-8 (D). Verified against SBOS450C.

| Parameter | Datasheet | Why it matters |
| --- | --- | --- |
| Input voltage noise density | **1.1 nV/√Hz typ at 1 kHz** (1.5 max), 1.5 at 100 Hz, 2 at 10 Hz | The largest single term in the stage's noise |
| Gain-bandwidth | **40 MHz** at G = +1, unity-gain stable | Sets the intermodulation margin |
| Input current noise | 1.7 pA/√Hz at 1 kHz | 0.2 % of noise power; irrelevant here |
| Supply range | ±2.25 V to ±18 V | ±5 V rails are inside it with room |
| Quiescent current | 3.6 mA per channel typ, 4.5 max | What power.md already budgets per amplifier |
| Output | rail to rail within 600 mV at 2 kΩ, ±30 mA | ±2.83 V peak on ±5 V, and a 400 Ω load |
| Common-mode range | (V−) + 2 to (V+) − 2 | ±3 V on ±5 V rails; the difference stage sits inside it |
| Slew rate | 27 V/µs | The figure analog.txt's output threshold is argued against |
| THD+N | 0.000015 % at 1 kHz, 3 V RMS | Below anything this design measures |

**This is the most consequential choice on the board**, because the analog
stage is now the floor: 125.8 dB against the digital chain's 133.5
([analog.txt](../../model/results/analog.txt) Q1c). The measured sensitivity to
amplifier voltage noise at the chosen 3.32 kΩ element is

| e_n | Stage SNR |
| --- | --- |
| 1.1 nV/√Hz | **126.3 dB** |
| 1.3 | 125.8 |
| 2.5 | 122.8 |
| 5.0 | 117.9 |

so the OPA1612 buys the best row on that table, half a decibel above the part
the model assumed and 3.5 dB above an ordinary 2.5 nV/√Hz audio dual. Paying
for a quieter part than this is not possible without leaving the class: the
sub-1 nV parts (ADA4898, LT1128) cost 8 mA per amplifier or more against a
budget that is already 76 % of a USB 2.0 host's, and buy at most 2 dB.

The gain-bandwidth is the other half. The filter was designed to clear its
intermodulation threshold **with a 10 MHz part** — the loosest case, leaving
9.8 dB of margin. At the OPA1612's 40 MHz the same filter measures −190.3 dBFS
in band, 43 dB inside the threshold, so the whole intermodulation argument
stops being close.

**Six amplifiers, three packages.** Two transimpedance stages per channel hold
the summing nodes at virtual ground, then one difference amplifier per channel
converts to single ended. power.md costed four amplifiers at 3.6 mA; six is
21.6 mA on each rail rather than 14.4, which is 15 mA more from the 5 V input
than that page's op amp line. It is still inside 0009's 65 mA for the op amp
stage and charge pump.

Two details of the wiring are deliberate and worth not undoing:

- **The non-inverting inputs of the transimpedance stages go straight to
  ground**, not through a bias-current compensation resistor. 60 nA through
  402 Ω is 24 µV of offset, while the 218 Ω that would cancel it would add
  1.9 nV/√Hz to the one stage whose noise this whole selection is about.
- **The difference amplifier's four resistors are one array, and they are
  604 Ω rather than the 200 Ω analog.txt names.** They set common-mode
  rejection, and what they have to reject is the 1.4 V of DC that both
  transimpedance outputs carry at mid code, so the array matters. The value
  is set by a supply-current argument, below.

### The negative rail carries the signal, and that set two values

The finding here is not in analog.txt's model, because that model has no
supply in it. It changed two component values once and has since been partly
undone by 0015, so both states are recorded.

**Every milliampere of element current ends up in the negative supply.** The
elements push current into a node held at 0 V; it leaves through the
transimpedance resistor into the amplifier's output pin, and the output stage
sinks it to `V−`. That is 13.9 mA, constant at every code by construction
(0008) — and it is signal, not quiescent current.

**The difference network is a second such load.** Its current scales as 1/R
while its own noise scales as √R, so the value is a genuine trade:

| Network | Its current, both channels | Negative rail | Stage SNR |
| --- | --- | --- | --- |
| **200 Ω — fitted** | **21.0 mA mid code, 28.0 worst** | **56.5–63.5 mA** | **125.6 dB** |
| 402 Ω | 10.4 / 14.0 | 46.0–49.4 | 124.3 |
| 604 Ω — was fitted | 7.0 / 9.3 | 42.5–44.8 | 123.5 |
| 1 kΩ | 4.2 / 5.6 | 39.7–41.1 | 122.4 |

**200 Ω is fitted, and the 2.1 dB is recovered.** It was 604 Ω for one round
because the module made its own negative rail with a charge pump, which cost
about twice its output current at the input and made 63 mA unaffordable.
0015 moved that rail to the main board; the current is ordinary again
and the noise-optimal value is affordable. Pole 3 follows the resistance:
3.9 nF across 200 Ω is 204 kHz, the same corner 1.3 nF across 604 Ω gave.

**A correction, because the reason recorded here was wrong.** This section
used to say 604 Ω was forced by the LTC3265's 50 mA internal LDO rating. It
was not: the LT3094 took `VOUT−` directly and `LDO−` drove nothing on this
board, as the netlist's own comment said. The constraint that actually bound
was the USB total — 509 mA against 500 at 200 Ω. The conclusion was right and
the reason given for it was not, which is worth knowing because the reason is
the part somebody would have acted on.

**The op amp choice stands, and at a better margin than it did.** The OPA1612
was picked against a curve putting the stage at 126.3 dB with its
1.1 nV/√Hz; with the 200 Ω network in the sum it is 125.6 dB:

| Amplifier voltage noise | Stage SNR, 200 Ω network |
| --- | --- |
| 1.1 nV/√Hz, OPA1612 | **125.6 dB** |
| 1.3 nV/√Hz, what analog.txt assumed | 125.2 |
| 2.5 nV/√Hz, an ordinary audio dual | 122.0 |

A 1.3 nV/√Hz part is within 0.4 dB, so that comparison was always thin. The
2.5 nV/√Hz part costs 3.6 dB, which is the comparison that decided it, and the
OPA1612's 40 MHz against the 10 MHz the filter was designed for is not
something a cheaper part matches either.

## Reclocking registers — SN74ALVCH16374DGGR (U3, U4)

Texas Instruments, 16-bit edge-triggered D-type flip-flop with 3-state
outputs, TSSOP-48 (DGG). Verified against SCES021L; the part is listed ACTIVE
in DL, DGG and DGV. A custom symbol was needed, and the pinout in
[../symbols/lyrebird.kicad_sym](../symbols/lyrebird.kicad_sym) is the
datasheet's own terminal assignment (1OE on 1, 1CLK on 48, VCC on 7/18/31/42,
GND on 4/10/15/21/28/34/39/45).

**The input threshold is what picks the family.** VIH is **2.0 V for VCC =
2.7 V to 3.6 V**, against the 2.4 V the FPGA guarantees at 2.5 V. That is the
rule 0012 states, and it is the reason the 28 element lines cross the
mezzanine untranslated:

| Family | VIH at 3.3 V | Verdict |
| --- | --- | --- |
| ALVCH | **2.0 V** | 400 mV of margin |
| LVC / LVCH | 0.7 × VCC = 2.31 V | The marginal case 0012 rejects |
| AVC | 0.65 × VCC = 2.15 V | Still referenced to the supply |
| LVTH, ALVTH | 2.0 V | Threshold passes, output fails — see below |

**The output has to be CMOS, not BiCMOS.** The register supply *is* full
scale, so the output high level is the reference the whole converter is
measured against. ALVCH specifies VOH as VCC − 0.2 V at −100 µA and 2.4 V at
−12 mA, so at the 1 mA an element draws it sits a few tens of millivolts under
the rail through an output impedance around 20 Ω — which is the figure
analog.txt already assumes, 0.6 % of a 3.32 kΩ element, and identical on every
element, so gain error rather than distortion. The LVT and ALVT families have
the same 2.0 V threshold but a bipolar output stage whose VOH is specified as
2.4 V at −8 mA; that is an uncontrolled drop in series with full scale.

Other specifications read off the datasheet: tpd CLK→Q 4.2 ns max at 3.3 V,
fmax 150 MHz against 24.576 MHz, ICC 40 µA static, Cpd 30 pF, data input
capacitance 6 pF. **Output-to-output skew is not specified in SCES021L** —
the minimum and typical columns of the switching table are marked "not
available at the time of publication" — so the one-package-per-channel
argument rests on both banks sharing a die and a supply, not on a published
skew number. Nothing was found to substitute for it.

**Bus hold is the one thing to know about this part.** The data inputs carry
an active bus-hold latch, which the datasheet offers as the reason no external
pull resistors are needed, and which explicitly warns against combining with
pull-ups or pull-downs. It sources up to **75 µA at VI = 2 V** toward its own
3.3 V rail. While the FPGA drives an element line, the line sits at the FPGA's
level and the hold current is absorbed by its driver. While the FPGA does
**not** drive — before configuration, or on a board whose flash has never been
programmed — bus hold pulls that line toward 3.3 V, and the line runs across
the mezzanine to a GateMate ball with a 2.75 V absolute maximum.

This is not caught by `lp.assert_below_abs_max`, because a data input is not a
driving pin and the check is right about that in general.

**It is settled against Cologne Chip's UG1003**, the GateMate interface guide
for 3.3 V peripherals. UG1003 states plainly that VDDIO may not exceed 2.7 V
and that "any voltage above VDDIO supply voltage should be avoided on the
GateMate pins", so the hazard is real rather than theoretical. But for a 3.3 V
source driving a GateMate input at low speed its recommended circuit is a bare
**10 kΩ to 100 kΩ series resistor and nothing else**, because "the input
overvoltage security circuitry of the GateMate input pin will limit the input
voltage". A 10 kΩ resistor from 3.3 V into a 2.5 V pin delivers about **80 µA**
into that clamp, and Cologne Chip endorses it. Bus hold is specified as a
**75 µA maximum current**, not a resistance, so it sits just inside the
envelope the vendor sanctions, and it stays inside it at any line voltage
because it is a current limit by construction.

**So no pull-down is needed, on either board**, and the element lines stay as
they are: straight from the header to the register inputs, which is what 0012
wants them to be.

One gap remains and is stated rather than papered over: **whether GateMate
GPIO are high impedance before configuration completes is not spelled out in
the datasheet**, so whether the bus hold ever gets to pull a line up is
unconfirmed. It does not change the conclusion, because the clamp covers the
worst case either way.

No ALVC-family 16-bit flip-flop without bus hold exists; the alternatives are
the threshold and output-stage failures in the tables above.

Spare bits: 14 elements in a 16-bit package leaves bit 8 of each bank unused.
Its data inputs are tied low rather than left to the hold latch, so the spare
outputs have a defined state; the spare outputs themselves are left open.

## Clock divider and fanout — SN74LVC1G74DCUR (U1) + LMK1C1104PWR (U12)

Two packages, not one, and the reason is current rather than preference.

**What was rejected.** Skyworks Si53308-B-GM is the closest single-chip
answer: dual 1:3 universal buffer, pin-strapped ÷2 per bank (DIVx low),
LVCMOS output format, 120–130 fs additive jitter from a single-ended input,
50 ps output skew. Its core supply current is **65 mA typical, 100 mA
maximum** (Si5330x data sheet rev 1.0, DC common characteristics), because it
is built for 725 MHz.

**The reason for rejecting it has since evaporated, and the choice survives
anyway.** It was rejected because 65 mA did not fit inside one unit load
before enumeration, and 0014 retired that rule with bus power. What still
holds is simpler: 65 mA of core current to replace two parts drawing 16 mA
between them is a poor trade on a board whose whole point is a quiet clock,
and the two-package arrangement has measured skew where the single chip has a
different set of unknowns. The original text read:

> The module's rails are not gated, and one unit load before enumeration
> leaves roughly 50 mA for the whole clock rail including 17 mA of oscillator
> (analog.txt Q1b). It does not fit.

Renesas 870S208, the other divider-plus-fanout part found, takes only
differential inputs and is listed obsolete — that rejection stands on its own.

**U1, SN74LVC1G74** wired as a toggle: `~Q` drives `D`, so `Q` is the input
divided by two at a 50 % duty cycle by construction. Verified against SCES794G:
fmax 175 MHz minimum at 3.3 V against 49.152 MHz in, tpd 2.2 ns typical,
±24 mA of output drive, ICC 10 µA static, Cpd 37 pF — about 6 mA at
49.152 MHz. VSSOP-8 (DCU); the pinout in the project symbol is figure 5-1.
Preset and clear are tied to the rail.

**U12, LMK1C1104** 1:4 LVCMOS fanout. Verified against SNAS791D: **additive
jitter 17.5 fs typical, 50 fs maximum** (12 kHz to 20 MHz) and
**output-to-output skew 50 ps maximum**, which is the number that matters,
because skew between the register packages behaves like element mismatch.
fmax 250 MHz at 3.3 V, propagation delay 1.5 ns typical, output impedance
60 Ω, and about 10 mA at 24.576 MHz read off the current-against-frequency
curve (the tabulated 33 mA is at 100 MHz with four outputs into 5 pF). `1G`
has a 300 kΩ internal pull-down and needs the external pull-up the datasheet
asks for. Y0 goes to U3, Y1 to U4, Y2 to the translator, Y3 spare and
floating, which the datasheet permits.

Both clock inputs of a register package hang on **one** buffer output, so the
two banks of a channel see the same edge rather than two outputs 50 ps apart.

**The divider's own additive jitter is not specified.** No 74-series datasheet
publishes one. This is the weakest number in the clock chain and it is stated
rather than estimated: what the datasheet does give — 175 MHz fmax, ±24 mA of
drive into a 5 pF buffer input, and a dedicated LT3045-regulated rail — is
the argument that its contribution is small, not a measurement. The
alternative that would have removed the question costs 65 mA.

Clock rail total: 17 mA of oscillator (one running, one in standby) + 6 mA
divider + 10 mA buffer + 0.5 mA translator ≈ 33.5 mA, against power.md's
37.5 mA estimate, which had allowed 20 mA for an unchosen divider.

## Oscillators — CCHD-957X-25-49.152 and CCHD-957X-25-45.1584 (Y1, Y2)

The part was already chosen in 0012; what was missing was a correct symbol.
The netlist carried an Abracon ASE stand-in with a 3.2 × 2.5 mm footprint.
Verified against the Crystek spec sheet rev N:

- **The package is 9 × 14 mm**, not a 7050. No stock KiCad footprint matches.
- Pad connection: **1 = E/D, 2 = GND, 3 = OUT, 4 = Vcc**. E/D is active high,
  with "1" at 0.7 × Vcc minimum, and an **open pin runs**.
- 3.3 V ±0.3 V, 15 mA typical and 25 mA maximum running, **1.5 mA maximum
  disabled** — the two figures 0012 costs the pair at.
- Phase noise floor −169 dBc/Hz typical, −100 dBc/Hz at 10 Hz offset.
- Option X is −40 to +85 °C at ±25 ppm, which is what 0012 specifies, and the
  part number example in the datasheet is exactly `CCHD-957X-25-49.152`.

**Both outputs share one net, and the datasheet is what makes that legal**:
"when placed in disable mode, the internal oscillator is completely shut down
in addition to its output buffer being placed in Tri-State". The idle part
neither drives the net nor radiates.

**The footprint is drawn**, at
`../footprints/lyrebird.pretty/Oscillator_SMD_Crystek_CCHD-957_9x14mm.kicad_mod`,
from the datasheet's SUGGESTED PAD LAYOUT: four pads of 0.050 × 0.090 in
(1.27 × 2.28 mm) on a 0.280 in (7.11 mm) by 0.200 in (5.08 mm) centre grid,
against package pad metal of 0.040 × 0.070 in (1.01 × 1.77 mm) in the bottom
view. Two things about it are read rather than stated, and both should be
checked against the vendor drawing before a board is fabricated:

- **Which axis the 0.090 in dimension lies along.** The text carries the four
  numbers without saying which belongs to which axis. It is drawn with the
  longer land along the 7.11 mm axis. If that is backwards the joint still
  forms — the land is larger than the pad metal either way, 2.28 against 1.77
  and 1.27 against 1.01 — but the fillet is smaller than intended.
- **Which corner is pad 1.** The pad *functions* are the datasheet's own Pad
  Connection table. Their geometric arrangement follows the universal four-pad
  oscillator convention, the same one KiCad's SG-8002CA footprint uses: pad 1
  lower left in top view, then 2, 3, 4 anticlockwise.

## Element resistors and the reconstruction filter

3.32 kΩ was already decided in [notes-analog.md](../../model/notes-analog.md).
What the netlist carried was a 1 kΩ placeholder, a single resistor per element
and a 1 nF capacitor at each summing node. All three changed.

**Value.** 1.69 kΩ + 1.65 kΩ = 3.34 kΩ per element, both E96, seven
four-element arrays of each. The split is the filter pole, below. The total is
0.6 % above the decided 3.32 kΩ, which is gain and nothing else, and it stays
above the 3312 Ω that the one-unit-load-at-power-on argument requires; an even
1.65 + 1.65 split would be 3.30 kΩ and fail that by a hair.

**The first filter pole is not a capacitor at the summing node.** This is the
one place where this work departs from the wording it was given, and it
follows analog.txt Q2b, which measured it:

> A shunt capacitor at the summing node is therefore not the first filter
> pole. Against a true virtual ground it sees no resistance and forms no pole
> at all; buy it a resistance by floating the node and the rail modulation
> arrives before the pole does. The netlist's 1 nF is not a filter.

What does work, and what the same file recommends, is splitting each element
resistor around a shunt capacitor: both ends stay at an AC ground — a
flip-flop output on one side, the virtual ground on the other — so the
capacitor sees R1‖R2 = 834 Ω while the DC current stays V_ref/(R1+R2) at
every code, and the constant-current property that 0008 depends on is
untouched. **180 pF C0G per element, 28 places**, gives 1.06 MHz.

The cost is the seven extra arrays and it is worth paying: with no real pole
in front of the first amplifier, analog.txt Q2c measures its in-band
intermodulation at −131.3 dBFS against a −147.2 dBFS threshold. That is a
failure by 15.9 dB. With the 1 MHz pole it is −190.3 dBFS. C0G rather than X7R
because a voltage coefficient inside one element is a nonlinearity the
rotation does not fix, and Q2e measured that 10 % capacitor tolerance costs
only 2 dB, so ordinary parts are fine.

**What the capacitors do to the reference rail, which is worth a model run.**
Each 180 pF has to be charged through the register-side half of its element
every time that element goes high, and discharged every time it goes low. At
the rotation's assumed transition rate — half the element clock, which is
power.md's own figure — that is about 0.37 mA per element averaged over a
cycle, or roughly **10 mA across 28 elements**, on top of the 13.9 mA of DC
element current. Two things follow, and neither is settled here:

- The reference rail's current is no longer only the constant 13.9 mA that
  0008's differential drive guarantees. **The constant-current property covers
  the DC term only**; this term and the registers' own dynamic current both
  scale with how often lines change, which the rotation ties to the code.
- That makes a signal-correlated current on the rail that sets full scale, and
  the rail is a multiplier. Against the 10 mΩ in-band source impedance
  analog.txt assumes, 10 mA of envelope variation is 100 µV on 3.32 V, about
  −90 dB — well above this design's floor if it were fully correlated, and far
  below it if the rotation whitens it, which is exactly what the rotation is
  for.

**This has since been measured, and it is the worst of the two cases above.**
`model/results/reference-current.txt` finds the current strongly correlated,
and finds that the rotation *creates* the correlation rather than whitening
it: with the DWA pointer advancing by the code, the number of lines that
change is `T = 14 − 4|s|` for a code `s` about mid scale, which is a full-wave
rectifier, so the transition rate carries the signal's magnitude. The
predicted in-band error is −101.1 dBFS against the −136.5 dBFS the chain is
held to.

**The mitigation named above is the wrong one, and so is 0008's.** Heavy local
decoupling answers a disturbance at tens of megahertz. This one is at twice
the signal frequency and at the programme envelope — an audio-frequency
current, where the eight 100 nF parts are about 100 Ω and the regulator's
10 mΩ is what the rail actually sees. Reaching the chain's floor would need
170 µΩ at 2 kHz, which is farads. The decoupling is still right for what it
was fitted for; it does not touch this.

What the identity does point at is a **transition ballast**: `T` is bounded
above by 14 and the modulation is the deficit, so dummy lines toggled to make
that deficit up flatten the current without altering the selection rule. It
costs the current of a fully toggling array. Not designed here.

**Poles two and three** are in the amplifier feedback: 2.0 nF across each
402 Ω transimpedance resistor (198 kHz) and 3.9 nF across each 200 Ω
difference-stage feedback (204 kHz), against the 200 kHz analog.txt asks for
and the 0.1 dB droop budget it is set by.

**Four summing nodes, not two.** The netlist summed left and right into one
differential pair, which is a mono mixer. Each channel now has its own pair
and its own amplifiers.

## Charge pump — removed (was LTC3265EDHC#TRPBF, U13)

**There is no charge pump on this board any more, and no switching converter
of any kind.** 0015 moved the negative rail to the main board, where
12 V makes an inverter cheap, and the pump went with everything that supported
it: two flying capacitors, two ADJ dividers, two reference bypasses and their
bulk. Sixteen parts.

The section that stood here worked out an LTC3265 in detail — `VIN_N` tied to
`VOUT+` per the datasheet's own instruction for symmetric rails, constant
frequency at 500 kHz rather than Burst Mode so the ripple sat at a known
rate, ADJ set to ±5.69 V by dropout arithmetic rather than symmetry, and a
`VIN_P` minimum of 4.5 V against a worst case of 4.43 that resolved on
examination. None of it was wrong. All of it is gone, and the reasoning is in
git history and in 0014 if a future module ever needs a bipolar rail from a
single supply.

**Why it was never needed.** The pump existed to make a positive rail with
headroom, because the module made both polarities symmetrically from one 5 V
input. But the output swings ±2.83 V peak and the OPA1612 reaches within
600 mV of its rails, so the positive supply wants about 3.5 V — and the
mezzanine had carried 5 V all along. Only the negative rail ever needed help
from outside. An LT3045 straight off the header gives +4.53 V, which is U14
below.

**What it cost while it was there**, recorded because it is the size of the
prize that paid for 0015: 73 mA of conversion overhead, a third of the
module's draw, for a stage that consumes 66 mA. A doubler costs about twice
its output at the input and the negative rail was inverted from the
already-doubled one, so it was paid for twice over. That is also what made
negative-rail current expensive enough to force the difference network to
604 Ω, forfeiting 2.1 dB — both now recovered.

## Positive and negative post-regulators — LT3045 (U14) and LT3094 (U8)

The LT3045 was already the part on this board; U14 is a fourth one. It sits on
the header's **+5V** — the charge pump whose LDO output used to feed it is
deleted — and is programmed to **+4.02 V by 40.2 kΩ** on SET. Its housekeeping
is the same shared helper the other three use, with `EN/UV` taken from
`MUTE_N` rather than tied to IN.

> **It was 49.9 kΩ, and that was a fault.** 49.9 kΩ programs 4.99 V, which
> suited the pump's 5.69 V and leaves 30 mV against a 260 mV dropout figure
> from the header's 5.02 V. The rail would not have reached its programmed
> voltage. The SET resistor was simply left behind when the input changed, and
> nothing caught it because `verify_power.py` checked the one LT3045 with 1.7 V
> of headroom and none of the module's five. It now reads all six out of the
> netlists.

The **LT3094** at U8 was in the netlist with only OUT and GND connected — the
netlist README lists its input as one of two genuinely open things on the
module. It is now wired against its own datasheet rather than by analogy:

- `SET`: 40.2 kΩ to ground, for 4.02 V. "The regulator's output voltage is determined by
  VSET = ISET • RSET" with a precision 100 µA reference, and 40.2 kΩ is the
  value its own Table 1 lists for −5 V. 4.7 µF of SET bypass, which is what
  the quoted noise figure is measured with.
- `EN/UV`: tied to IN. "If unused, tie EN/UV to IN. Do not float the EN/UV
  pin." The enable thresholds are ±1.2 V nominal **of either polarity**, so on
  a negative regulator tying the pin to the negative input is an enable, not a
  shutdown — worth stating, because it reads like a shutdown.
- `PGFB`: tied to IN. "If power good and fast start-up functionality are not
  needed, tie PGFB to IN."
- `ILIM`: **programmed, not tied.** The LT3045's datasheet says to tie ILIM to
  ground when the feature is unused; the LT3094's pin description gives no such
  sentence, and its scale factor is 3.75 A·kΩ, so grounding the pin is not
  obviously the same instruction. 24.9 kΩ programs about 150 mA, comfortably
  above the 22 mA this rail carries and below what the pump's LDO can deliver
  into a fault.
- `VIOC`: left open. "If unused, float the VIOC pin."
- `PG`: left open, an open-collector flag, as on the LT3045s.

## Analog output connector — SJ1-3523N (J2)

Same Sky (formerly CUI Devices) SJ1-3523N: 3.5 mm, stereo, right angle,
through hole, **three conductors and no internal switches**, rated 12 VDC.
Stock KiCad symbol and footprint both exist and agree with it — the footprint
has exactly three pads, T, R and S, which is what a switchless jack has.

Tip is left, ring is right, sleeve is ground.

**No switch, because this variant has nothing to switch.** A switched jack
earns its place on a combined module, where 0007 gates the headphone amplifier
from the jack's switch contact.

**No output coupling capacitor.** The differential arrangement puts both
transimpedance outputs at the same DC, so the difference amplifier's output
sits at zero by construction and what is left is offset: a 0.1 % mismatch
between the two 402 Ω feedback resistors on 1.4 V of common mode is about
1.4 mV. A series capacitor large enough not to intrude in band would be an
electrolytic or a film part in the signal path, which is a worse trade than
1.4 mV.

**100 pF C0G from each output to ground**, at the jack. The jack is the only
port on the board and therefore its antenna; against the 100 Ω build-out
resistor this is a 16 MHz corner, which is nothing in band and something
against radio frequency arriving from outside.
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

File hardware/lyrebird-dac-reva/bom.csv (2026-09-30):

Ref | Qty | Value | Manufacturer | MPN | Package | Rail/Function | Status | Notes
J1 | 1 | Mezzanine 2x40 | generic | 2x40 1.27 mm header | PinHeader_2x40_P1.27mm_Vertical | mezzanine | DECIDED | Mates with the main board's J2. Both halves allocate all 80 pins and no pin's net differs across the connector.
J2 | 1 | SJ1-3523N | Same Sky | SJ1-3523N | Jack_3.5mm_CUI_SJ1-3523N_Horizontal | line out | VERIFIED | 3.5 mm stereo, three conductors, no switch.
U1 | 1 | SN74LVC1G74DCUR | Texas Instruments | SN74LVC1G74DCUR | VSSOP-8_2.3x2mm_P0.5mm | +3V3_CLK | VERIFIED | Divides the oscillator by two at a 50 % duty cycle by construction. Its own additive jitter is unpublished; no 74-series datasheet gives one.
U2 | 1 | 74AVC4T245 | Texas Instruments | SN74AVC4T245PWR | TSSOP-16_4.4x5mm_P0.65mm | 2.5 V / 3.3 V | VERIFIED | Translates the clock and the two oscillator enables across the domain boundary. 0012.
U3 | 1 | SN74ALVCH16374DGGR | Texas Instruments | SN74ALVCH16374DGGR | TSSOP-48_6.1x12.5mm_P0.5mm | +3V3_REF | VERIFIED | VIH is 2.0 V at a 3.3 V supply, against the 2.4 V the FPGA guarantees -- the only family that clears it with CMOS rather than BiCMOS outputs, and the supply IS full scale. Bus hold is settled against UG1003. 0008, 0012.
U4 | 1 | SN74ALVCH16374DGGR | Analog Devices | LTM4622IV#PBF | TSSOP-48_6.1x12.5mm_P0.5mm | +2V5 and +1V0 | VERIFIED | Both RUN pins tied on. The enumeration gating 0009 specified was removed by 0014: it held the core rail off whenever no USB host was present, which on a wall-powered board is always.
U5 | 1 | LT3045 element reference | Analog Devices | LT3045EDD#TRPBF | DFN-10-1EP_3x3mm_P0.5mm_EP1.65x2.38mm | precision rails | VERIFIED | 10 pins: DFN-10, not the DFN-12 the netlist carried. The element reference rail IS full scale, so its noise is the converter's.
U6 | 1 | LT3045 clock chain | Macronix | MX25R6435FM2IH0 | DFN-10-1EP_3x3mm_P0.5mm_EP1.65x2.38mm | +2V5 VDD_WA | UNVERIFIED | 64 Mbit, runs at 2.5 V where an ordinary 2.7 V part cannot. Supply range and quad-enable default not re-read. 0006.
U7 | 1 | OPA1612AID | Texas Instruments | OPA1612AID | SOIC-8_3.9x4.9mm_P1.27mm | +/-5V analog | VERIFIED | 1.1 nV/sqrt(Hz), 40 MHz. The most consequential choice here: the analog stage is the floor. Six amplifiers, three packages.
U8 | 1 | LT3094 op amp negative rail | Analog Devices | LT3094EDD#TRPBF | DFN-12-1EP_3x3mm_P0.45mm_EP1.65x2.38mm | -5V analog | VERIFIED | Takes the mezzanine's -6 V. 13 pins, so DFN-12 is correct for this part where it was wrong for every LT3045.
U9 | 1 | LT3045 header-side 2.5 V | Analog Devices | LT3045EDD#TRPBF | DFN-10-1EP_3x3mm_P0.5mm_EP1.65x2.38mm | +2V5 translator | VERIFIED | The translator's A port faces the header and must be 2.5 V, but the header carries only +5V and ground, so the module regulates its own. Nothing on this rail reaches the signal, so a cheaper part would do; it is an LT3045 for consistency.
U10 | 1 | OPA1612AID | Texas Instruments | OPA1612AID | SOIC-8_3.9x4.9mm_P1.27mm | +/-5V analog | VERIFIED | 1.1 nV/sqrt(Hz), 40 MHz. The most consequential choice here: the analog stage is the floor. Six amplifiers, three packages.
U11 | 1 | OPA1612AID | Texas Instruments | OPA1612AID | SOIC-8_3.9x4.9mm_P1.27mm | +/-5V analog | VERIFIED | 1.1 nV/sqrt(Hz), 40 MHz. The most consequential choice here: the analog stage is the floor. Six amplifiers, three packages.
U12 | 1 | LMK1C1104PWR | Texas Instruments | LMK1C1104PWR | TSSOP-8_4.4x3mm_P0.65mm | +3V3_CLK | VERIFIED | 17.5 fs additive jitter, 50 ps output skew -- skew between register packages behaves like element mismatch. Both clock inputs of a package hang on one output.
U14 | 1 | LT3045 op amp positive rail, +4.02 V from mezzanine 5 V | Analog Devices | LT3045EDD#TRPBF | DFN-10-1EP_3x3mm_P0.5mm_EP1.65x2.38mm | +5V analog | VERIFIED | Takes the mezzanine's 5 V straight down to +4.02 V. The value solves two bounds rather than being chosen: dropout needs Vout below 4.61 V at the worst-case input, the swing needs it above 3.43 V, and 40.2 k sits at the midpoint with +510 mV each side. It read 4.99 V and then 4.53 V before the tolerances were stacked. This is what deleted the charge pump: the output swings +/-2.83 V peak and the OPA1612 reaches within 600 mV of its rails, so the positive supply needs about 3.5 V and the header already carried it. Only the negative rail ever needed help.
Y1 | 1 | CCHD-957X-25-49.152 | Crystek | CCHD-957X-25-49.152 | Oscillator_SMD_Crystek_CCHD-957_9x14mm | +3V3_CLK | VERIFIED | 1024x the element clock. Standby tri-states the output, which is what makes one shared OSC_RAW net legal. Footprint drawn here; its pad NUMBERING is still unresolved. 0012.
Y2 | 1 | CCHD-957X-25-45.1584 | Crystek | CCHD-957X-25-45.1584 | Oscillator_SMD_Crystek_CCHD-957_9x14mm | +3V3_CLK | VERIFIED | As Y1, for the 44.1 kHz family.
C1-C64 | 16 | 100nF |  |  | C_0402_1005Metric |  | GROUPED | Capacitors, grouped by value. 16 places.
C55 C56 | 2 | 100pF C0G |  |  | C_0402_1005Metric |  | GROUPED | Capacitors, grouped by value. 2 places.
C3-C30 | 28 | 180pF C0G |  |  | C_0402_1005Metric |  | GROUPED | Capacitors, grouped by value. 28 places.
C37 C38 C41 C42 | 4 | 2.0nF C0G 2% |  |  | C_0603_1608Metric |  | GROUPED | Capacitors, grouped by value. 4 places.
C47 C48 C49 C50 | 4 | 3.9nF C0G 2% |  |  | C_0603_1608Metric |  | GROUPED | Capacitors, grouped by value. 4 places.
C32 C34 C35 C36 C52 C54 | 6 | 10uF |  |  | C_0805_2012Metric |  | GROUPED | Capacitors, grouped by value. 6 places.
C31 C33 C51 C53 | 4 | 4.7uF |  |  | C_0805_2012Metric |  | GROUPED | Capacitors, grouped by value. 4 places.
R8 R9 | 2 | 100R |  |  | R_0402_1005Metric |  | GROUPED | Resistors, grouped by value. 2 places.
R1 R2 R3 | 3 | 100k |  |  | R_0402_1005Metric |  | GROUPED | Resistors, grouped by value. 3 places.
R4 R14 | 2 | 10k |  |  | R_0402_1005Metric |  | GROUPED | Resistors, grouped by value. 2 places.
R13 | 1 | 1k |  |  | R_0402_1005Metric |  | GROUPED | Resistors, grouped by value. 1 places.
R7 | 1 | 24.9k 0.1% |  |  | R_0402_1005Metric |  | GROUPED | Resistors, grouped by value. 1 places.
R12 | 1 | 24.9k 1% |  |  | R_0402_1005Metric |  | GROUPED | Resistors, grouped by value. 1 places.
R5 R6 | 2 | 33.2k 0.1% |  |  | R_0402_1005Metric |  | GROUPED | Resistors, grouped by value. 2 places.
R10 | 1 | 40.2k 0.1% |  |  | R_0402_1005Metric |  | GROUPED | Resistors, grouped by value. 1 places.
R11 | 1 | 49.9k 0.1% |  |  | R_0402_1005Metric |  | GROUPED | Resistors, grouped by value. 1 places.
RN1-RN14 | 14 | 1.65k 0.1% thin film |  |  | R_Array_Concave_4x0402 |  | GROUPED | Resistors, grouped by value. 14 places.
RN16 RN17 | 2 | 200R, 0.1% RATIO matched, thin film array |  |  | R_Array_Concave_4x0402 |  | GROUPED | Resistors, grouped by value. 2 places.
RN15 | 1 | 402R 0.1% thin film |  |  | R_Array_Concave_4x0402 |  | GROUPED | Resistors, grouped by value. 1 places.

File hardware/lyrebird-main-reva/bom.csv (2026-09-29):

Ref | Qty | Value | Manufacturer | MPN | Package | Rail/Function | Status | Notes
D1 | 1 | SS34 3A 40V | Vishay | SS34-E3/57T | D_SMA | reverse polarity | VERIFIED | Series Schottky. At 12 V its 0.35 V costs 210 mW against a supply with volts to spare, and buys the absence of a gate to protect. The FET is the better answer at 5 V and not here.
D2 | 1 | SMAJ18A unidirectional | Vishay | SMAJ18A-E3/61 | D_SMA | transient clamp | VERIFIED | 18 V, not 15 V. The 15 V part conducts on a 19 V adapter at 41 mA and 117 C indefinitely without tripping the fuse -- a heater, not a protection. Must stay unidirectional: see D3.
D3 | 1 | BAT54 negative clamp | Nexperia | BAT54,215 | D_SOD-123 | negative clamp | UNVERIFIED | Holds the reversed rail at -0.233 V against the converter's -0.3 V minimum. Without it D1's own leakage drags the node to -0.399 V, held only by D2's forward drop. Forward voltage at microamps is off the bottom of the datasheet curve.
F1 | 1 | 1812L050/30 PPTC 0.5A hold 30V 100A | Littelfuse | 1812L050/30MR | Fuse_1812_4532Metric | input protection | VERIFIED | 30 Vdc clears the 29.2 V TVS clamp; 100 A Imax clears 27.9 A of inrush; 0.50 A hold derates to 0.33 A at 70 C, still above the 219 mA drawn. The 0.35 A part derates to 0.20 A and would nuisance-trip.
J1 | 1 | Connfly DS1104-01 | Connfly | DS1104-01 | USB3_Micro-B_Connfly_DS1104-01 | USB | DECIDED | USB 3.0 Micro-B. The SuperSpeed pairs go unrouted under 0014 -- High Speed carries 192/24 stereo at 1.9 % utilisation.
J2 | 1 | Mezzanine 2x40 | generic | 2x40 1.27 mm header | PinHeader_2x40_P1.27mm_Vertical | mezzanine | DECIDED | All 80 pins assigned: 28 element lines, clock, five control, two of -6V, five of +5V, the rest ground. 0007, interface.md.
J3 | 1 | JTAG 2x5 1.27mm | generic | 2x05 1.27 mm header | PinHeader_2x05_P1.27mm_Vertical | JTAG | DECIDED | TMS, TCK and TDI carry 1k in series: 0006 specifies an ordinary FTDI adapter and the common ones drive a fixed 3.3 V into a 2.75 V ball. A 2.5 V adapter is the better answer.
J4 | 1 | 12 V 2.1 x 5.5 mm, centre positive | CUI Devices | PJ-002AH | BarrelJack_Horizontal | 12 V input | UNVERIFIED | 2.1 x 5.5 mm, centre positive. Current rating and pin geometry not confirmed against a datasheet. 0014.
L1 | 1 | 10uH 3A shielded | Wurth | 744314100 | L_12x12mm_H8mm | +5V output | UNVERIFIED | 10 uH, 3 A, shielded. Inductance from the LMR33630 datasheet's 5 V table; the specific part is not confirmed.
L2 | 1 | 10uH 3A shielded | Wurth | 744314100 | L_12x12mm_H8mm | -6V output | UNVERIFIED | As L1. In the inverting configuration this returns to system ground rather than to the output.
U1 | 1 | CCGM1A1-BGA324 | Cologne Chip | CCGM1A1 | BGA-324_15x15mm_Layout18x18_P0.8mm | +1V0 core, +2V5 banks | VERIFIED | Interpolation, third-order modulator, DWA rotation. All 324 balls checked against DS1001. 2.75 V absolute maximum on I/O is the constraint the whole part chain follows from. 0005, 0008.
U2 | 1 | FT601Q | FTDI | FT601Q-B-T | QFN-76-1EP_9x9mm_P0.4mm_EP5.81x6.31mm | +3V3 VCC33, +2V5 VCCIO | VERIFIED | USB bridge, 245 Sync FIFO. Chosen because VCCIO can be 2.5 V, which removes level translation. Runs High Speed, not SuperSpeed, since isolation has no SuperSpeed option. 0005, 0014.
U3 | 1 | LT3045 | Analog Devices | LT3045EDD#TRPBF | DFN-10-1EP_3x3mm_P0.5mm_EP1.65x2.38mm | +3V3 from +5V | VERIFIED | C_SET is 100 nF here, not 4.7 uF: PGFB tied to IN disables fast start, and 4.7 uF then ramps in 359 ms, putting the bridge's VCCIO 355 ms ahead of its own VCC33. This rail is digital only.
U4 | 1 | LTM4622IV#PBF | Analog Devices | LTM4622IV#PBF | Analog_LGA-25_6.25x6.25mm_Layout5x5_P1.27mm | +2V5 and +1V0 | VERIFIED | Both RUN pins tied on. The enumeration gating 0009 specified was removed by 0014: it held the core rail off whenever no USB host was present, which on a wall-powered board is always.
U5 | 1 | LMR33630 12V->5V 3A | Texas Instruments | LMR33630ADDAR | Texas_HSOP-8-1EP_3.9x4.9mm_P1.27mm_ThermalVias | +12V to +5V | VERIFIED | 36 V part on a 12 V rail. Everything downstream of +5V is unchanged from the bus-powered design, deliberately. 0014.
U6 | 1 | MX25R6435F 64Mb | Macronix | MX25R6435FM2IH0 | SOIC-8_3.9x4.9mm_P1.27mm | +2V5 VDD_WA | UNVERIFIED | 64 Mbit, runs at 2.5 V where an ordinary 2.7 V part cannot. Supply range and quad-enable default not re-read. 0006.
U7 | 1 | LMR33630 12V->-6V inverting | Texas Instruments | LMR33630ADDAR | Texas_HSOP-8-1EP_3.9x4.9mm_P1.27mm_ThermalVias | +12V to -6V | VERIFIED | Same part as U5, wired as an inverting buck-boost: its GND pin sits on the negative output and it sees VIN + |VOUT| = 18 V against a 36 V rating. Feeds the module across the mezzanine so the analog board needs no switching converter at all.
Y1 | 1 | ABM8G-30.000MHZ-18-D2Y-T | Abracon | ABM8G-30.000MHZ-18-D2Y-T | Crystal_SMD_3225-4Pin_3.2x2.5mm | FT601Q reference | UNVERIFIED | 30 MHz for the bridge. The ordering-suffix fields were never decoded against the datasheet.
C2-C109 | 87 | 100nF |  |  | C_0402_1005Metric |  | GROUPED | Capacitors, grouped by value. 87 places.
C20 C21 | 2 | 10nF |  |  | C_0402_1005Metric |  | GROUPED | Capacitors, grouped by value. 2 places.
C26 C27 | 2 | 27pF C0G |  |  | C_0402_1005Metric |  | GROUPED | Capacitors, grouped by value. 2 places.
C7 C14 C16 | 3 | 100nF |  |  | C_0603_1608Metric |  | GROUPED | Capacitors, grouped by value. 3 places.
C8 C11 | 2 | 1uF |  |  | C_0603_1608Metric |  | GROUPED | Capacitors, grouped by value. 2 places.
C17 | 1 | 100nF |  |  | C_0805_2012Metric |  | GROUPED | Capacitors, grouped by value. 1 places.
C18 C19 | 2 | 10uF |  |  | C_0805_2012Metric |  | GROUPED | Capacitors, grouped by value. 2 places.
C28 | 1 | 2.2uF |  |  | C_0805_2012Metric |  | GROUPED | Capacitors, grouped by value. 1 places.
C24 C25 | 2 | 22uF |  |  | C_0805_2012Metric |  | GROUPED | Capacitors, grouped by value. 2 places.
C1 C22 C23 | 3 | 4.7uF |  |  | C_0805_2012Metric |  | GROUPED | Capacitors, grouped by value. 3 places.
C15 | 1 | 10uF |  |  | C_1210_3225Metric |  | GROUPED | Capacitors, grouped by value. 1 places.
C6 | 1 | 22uF |  |  | C_1210_3225Metric |  | GROUPED | Capacitors, grouped by value. 1 places.
C10 C13 | 2 | 47uF |  |  | C_1210_3225Metric |  | GROUPED | Capacitors, grouped by value. 2 places.
R13 | 1 | 1.6k 1% |  |  | R_0402_1005Metric |  | GROUPED | Resistors, grouped by value. 1 places.
R1 R4 R11 R12 | 4 | 100k |  |  | R_0402_1005Metric |  | GROUPED | Resistors, grouped by value. 4 places.
R2 | 1 | 100k 1% |  |  | R_0402_1005Metric |  | GROUPED | Resistors, grouped by value. 1 places.
R14-R32 | 15 | 10k |  |  | R_0402_1005Metric |  | GROUPED | Resistors, grouped by value. 15 places.
R5 | 1 | 124k 1% |  |  | R_0402_1005Metric |  | GROUPED | Resistors, grouped by value. 1 places.
R8 | 1 | 19.1k 1% |  |  | R_0402_1005Metric |  | GROUPED | Resistors, grouped by value. 1 places.
R27 R29 R31 | 3 | 1k 1% |  |  | R_0402_1005Metric |  | GROUPED | Resistors, grouped by value. 3 places.
R3 R6 | 2 | 24.9k 1% |  |  | R_0402_1005Metric |  | GROUPED | Resistors, grouped by value. 2 places.
R7 | 1 | 33.2k 0.1% |  |  | R_0402_1005Metric |  | GROUPED | Resistors, grouped by value. 1 places.
R22 | 1 | 47k 1% |  |  | R_0402_1005Metric |  | GROUPED | Resistors, grouped by value. 1 places.
R10 | 1 | 649k 1% |  |  | R_0402_1005Metric |  | GROUPED | Resistors, grouped by value. 1 places.
R9 | 1 | 90.9k 1% |  |  | R_0603_1608Metric |  | GROUPED | Resistors, grouped by value. 1 places.

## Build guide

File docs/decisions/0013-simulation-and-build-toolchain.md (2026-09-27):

# 0013 — Simulation and build toolchain

**Status:** accepted, with one correction below.

> **Correction, 2026-09-25.** This record contradicted itself two table rows
> apart: git-lfs was listed as "installed" and as "**missing**". The tool is
> installed; the repository is **not configured to use it**, and whether it
> should be is still open — that decision is much cheaper before
> `hardware/datasheets/` fills with multi-megabyte PDFs than after. The
> bitstream figures below are also two designs old and should be re-read from
> `hdl/build/` rather than from here.

## Context

Earlier records said "cocotb over Icarus or Verilator" and left the choice
open. The audio measurement described in
[0008](0008-multibit-delta-sigma-with-dwa.md) settles it, because it needs long
runs rather than short ones.

## Decision

**Verilator with cocotb** for simulation. **Yosys and nextpnr-himbaechel** for
the FPGA build. **openFPGALoader** for programming. **KiCad** for the boards.

### Why Verilator rather than Icarus

A meaningful in-band noise figure wants an FFT long enough to resolve the floor
across the audio band, which is on the order of a million modulator cycles. At
24.576 MHz that is about 41 ms of simulated time. Verilator handles that in
roughly a second of compute for a small design; Icarus is one to three orders
of magnitude slower and would turn every measurement into a break.

### Two tiers of test, deliberately

**Functional tests use cocotb.** Protocol handshakes, tag resync, control word
decoding, underrun behaviour, the lock state machine. These are short,
event-driven, and far easier to express in Python than in an HDL testbench.

**The audio measurement does not.** Reading 28 element lines from Python on
every cycle makes the language binding the bottleneck rather than the
simulator. The first suite here measured about 350,000 ns of simulated time per
wall second on a trivial design, which extrapolates to minutes for a million
cycles and worsens as the modulator grows.

Instead, dump the element lines from the simulation and analyse them afterwards
in numpy. That inverts a useful ratio: **simulate once, analyse many times.**
Testing the rotation against a dozen element mismatch distributions then costs
one simulation rather than twelve, which matters because that is exactly the
experiment [0008](0008-multibit-delta-sigma-with-dwa.md) calls for.

### cocotb 2.x, and why version matters

Verified working on cocotb 2.1.0 with Python 3.14.6. The 2.x API is not the one
in most tutorials:

- `cocotb.fork` is removed; use `cocotb.start_soon`.
- `Clock(...)` takes `unit`, not `units`.
- The runner moved to `cocotb_tools.runner`.

**The floor is 2.1, not 2.0, and that is forced rather than chosen.** cocotb
2.0.x refuses to build on Python 3.14 and says so explicitly: it supports a
maximum of Python 3.13. Since the API is identical across the 2.x line, the
only reason to pin 2.0.x would be an external constraint, and it would mean
moving to Python 3.13 as well.

### HDL language subset

SystemVerilog restricted to what Yosys accepts: `logic`, `always_ff`,
`always_comb`, `localparam`. No interfaces, no packed structs. Verilator would
take the full language, but the same sources have to synthesise, and Yosys's
SystemVerilog support is partial.

### Verilator caveats to design around

Verilator is two-state by default, so it will not show X propagation and will
happily simulate a design whose reset behaviour is incomplete. Do not rely on
it to catch uninitialised state. It also rejects delays in synthesisable code,
which is a feature here.

## The build flow, and one non-obvious requirement

```
yosys  -luttree  ->  nextpnr-himbaechel  ->  gmpack  ->  openFPGALoader
```

**`synth_gatemate -luttree` is required, not optional.** Without it ABC maps
logic to `CC_LUT4`, and nextpnr-himbaechel rejects that cell type outright.
The fabric's native element is a LUT tree, so synthesis has to target
`CC_L2T4`/`CC_L2T5`. The failure is a hard error well into place-and-route,
with a message that does not point at the cause.

**Place-and-route refuses to run without a CCF pin constraints file.** There is
an `allow-unconstrained` override, which is useful for resource counts and
never valid for hardware. See [hdl/constraints/README.md](../../hdl/constraints/README.md),
which also records the clock-pin trap from
[0012](0012-module-clock-architecture.md): a clock on an ordinary pin silently
falls back to fabric routing rather than erroring.

**The OSS CAD Suite is sourced per shell, never added to PATH permanently.** It
ships its own Yosys, 0.69+24 against the 0.67 from Homebrew, and having both on
PATH means losing track of which one built a given artifact. `tools/synth.sh`
sources its `environment` script and honours an `OSS_CAD_SUITE` override.

### Bitstream size scales with utilisation

| Design | CPE_LT | CPE_FF | Bitstream |
| --- | --- | --- | --- |
| `lyrebird_tag_decode` | 94 | 28 | 97,566 bytes |
| `lyrebird_unpack` | 290 | 92 | 184,050 bytes |

**An earlier revision of this record claimed configuration was close to
fixed-size and concluded a 2 Mbit flash was ample. That was drawn from a single
data point and is wrong.** Roughly three times the logic produced nearly twice
the bitstream, so the format is not a flat image of the whole fabric.

Both designs are still under one percent of the part, and the real design adds
an interpolator, a modulator, the rotation and the elastic buffer. Do not pick
a flash part until something close to the full design has been built and
measured. 2 Mbit leaves only about 1.4 times headroom over the second figure
here, which is too thin to commit to.

## Environment as verified

| Tool | Status |
| --- | --- |
| Verilator 5.048 | installed |
| Yosys 0.67+post, with `synth_gatemate` | installed |
| cocotb 2.1.0, Python 3.14.6 | installed in `.venv` |
| KiCad 10.0.6 | installed, `kicad-cli` not on PATH |
| numpy, scipy, matplotlib | installed in `.venv` |
| GTKWave | installed, reads the FST dumps from `WAVES=1` |
| clang, make, cmake | installed |
| nextpnr-himbaechel, with CCGM1A1 and CCGM1A2 databases | installed via OSS CAD Suite |
| gmpack, gmunpack | installed via OSS CAD Suite |
| openFPGALoader 1.1.1 | installed |
| git-lfs 3.8.0 | installed. The **repository** is not configured to use it, and whether it should be is open — much cheaper to decide before `hardware/datasheets/` fills with multi-megabyte PDFs than after |
| FTDI D3XX library | universal dylib, arm64 native confirmed; not yet vendored |

Homebrew has no generic nextpnr, only `nextpnr-ice40`, so the OSS CAD Suite is
the only practical route to the GateMate target. Its build recipes include
Project Peppercorn and the GateMate database generator.

KiCad 10.0.6 is installed but `kicad-cli` is not linked; it lives at
`/Applications/KiCad/KiCad.app/Contents/MacOS/kicad-cli`.

## Consequences

The first module through both paths was `lyrebird_tag_decode`: eight passing
tests, and a complete run from source to bitstream. Worth noting what synthesis
found: 52 output bits collapsed into 28 flip-flops, because the sample field and
the control opcode and payload are the same 24 bits of the word and only one of
them is ever valid.

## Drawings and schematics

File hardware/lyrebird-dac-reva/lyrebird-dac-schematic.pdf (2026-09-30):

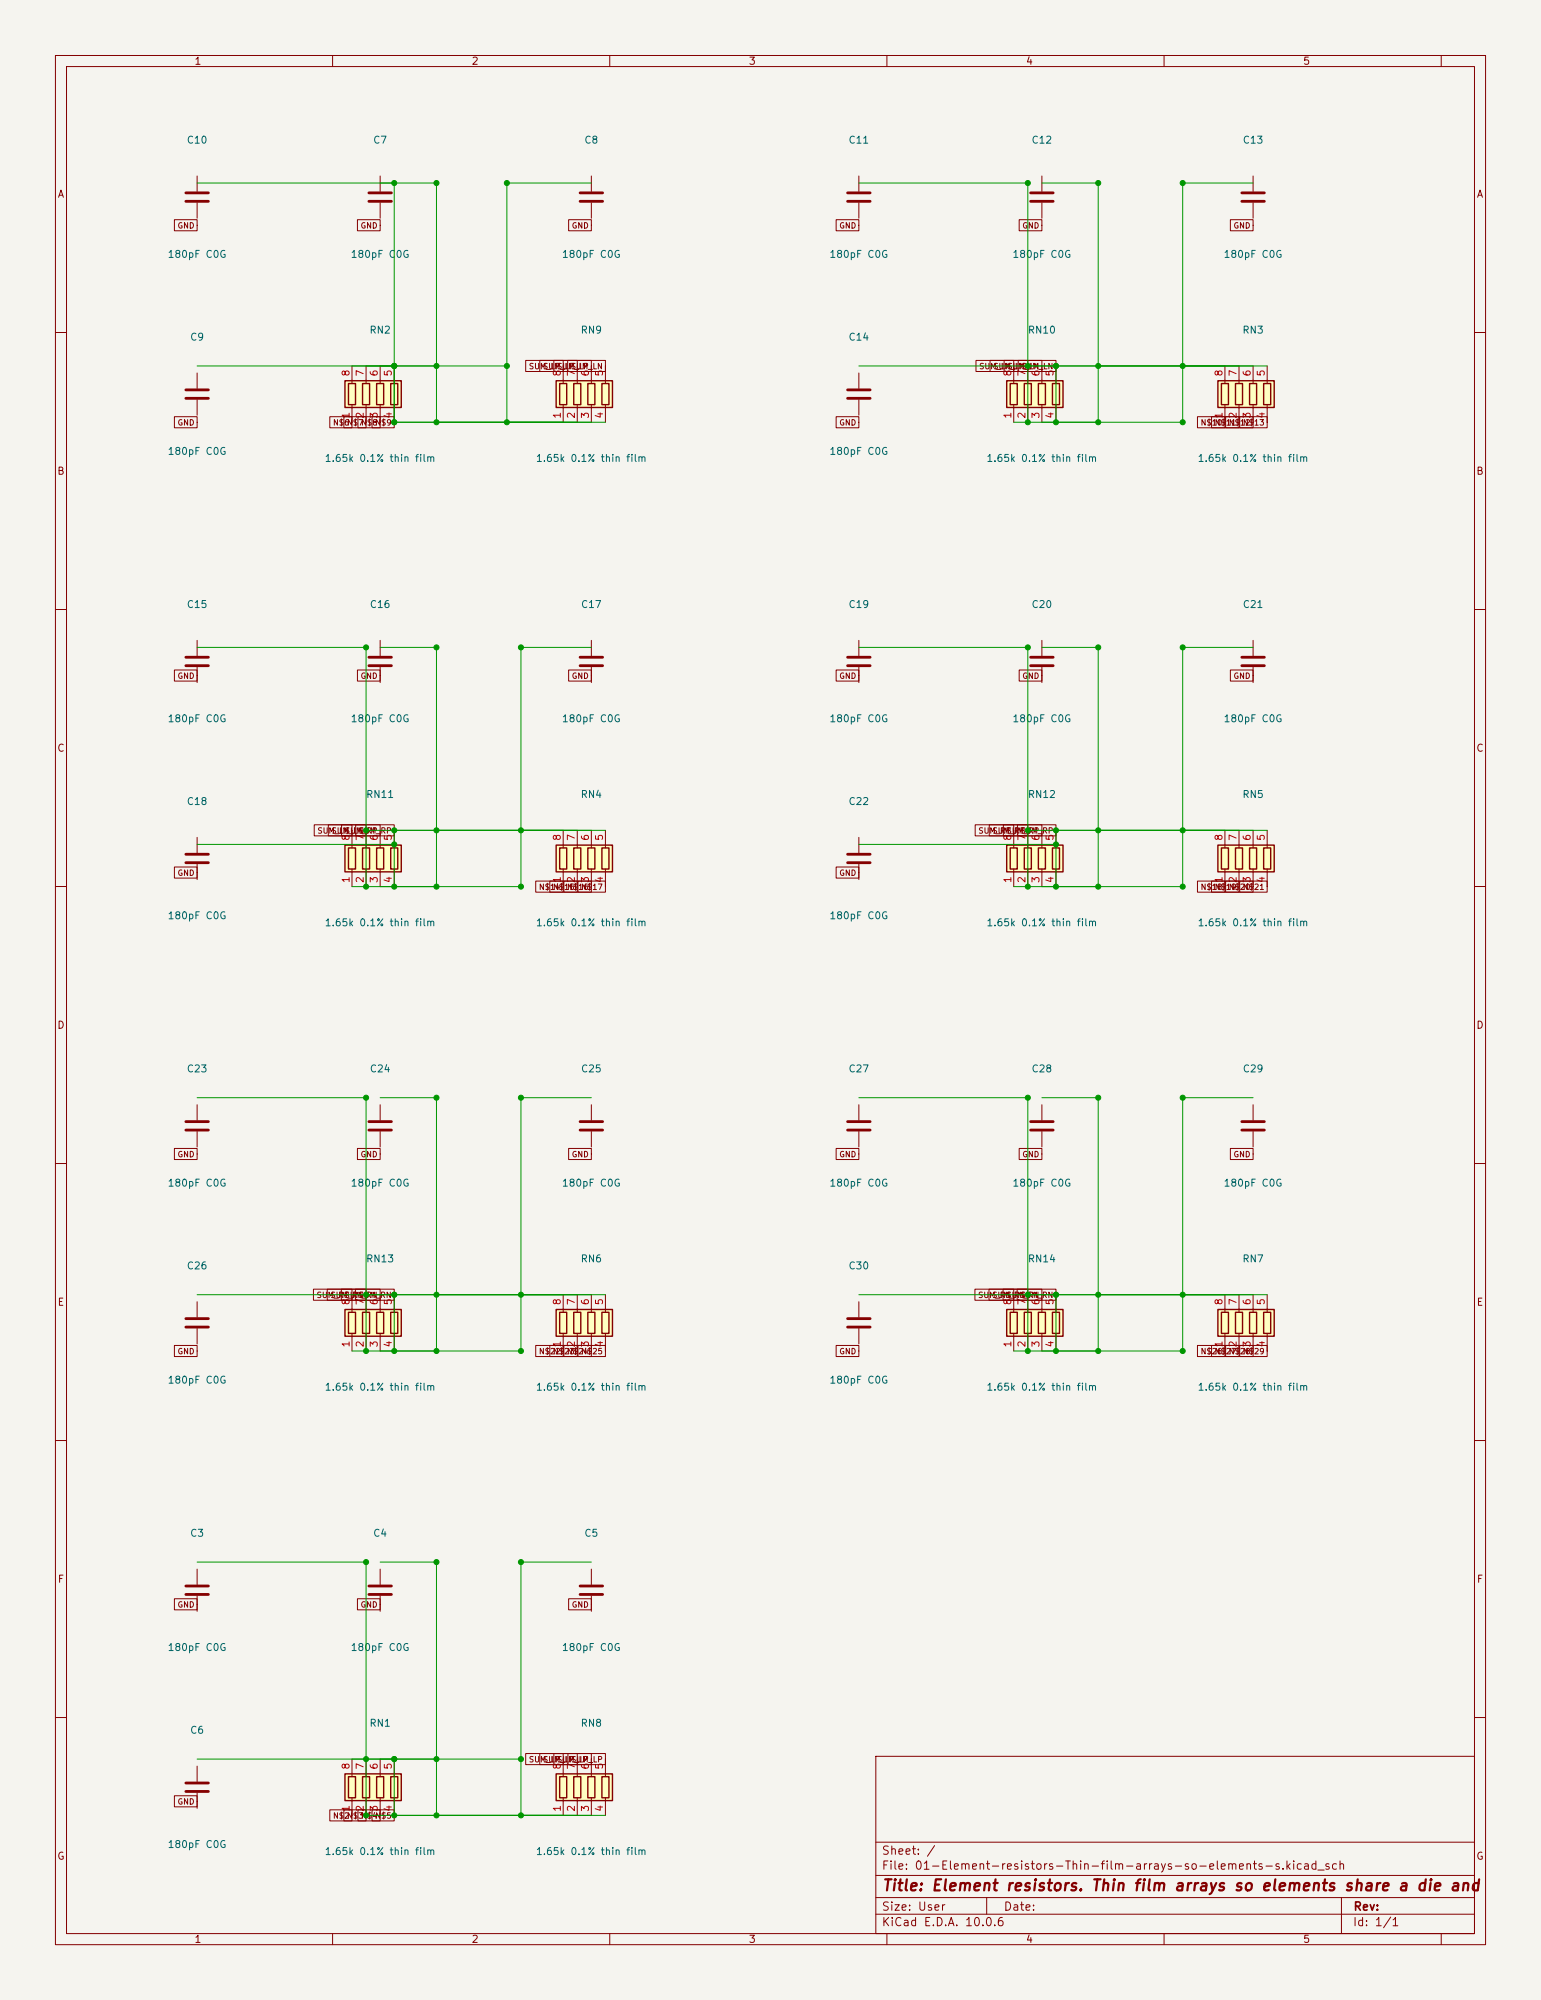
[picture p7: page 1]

Sheet: /
File: 01-Element-resistors-Thin-film-arrays-so-elements-s.kicad_sch
Title: Element resistors. Thin film arrays so elements share a die and
KiCad E.D.A. 10.0.6

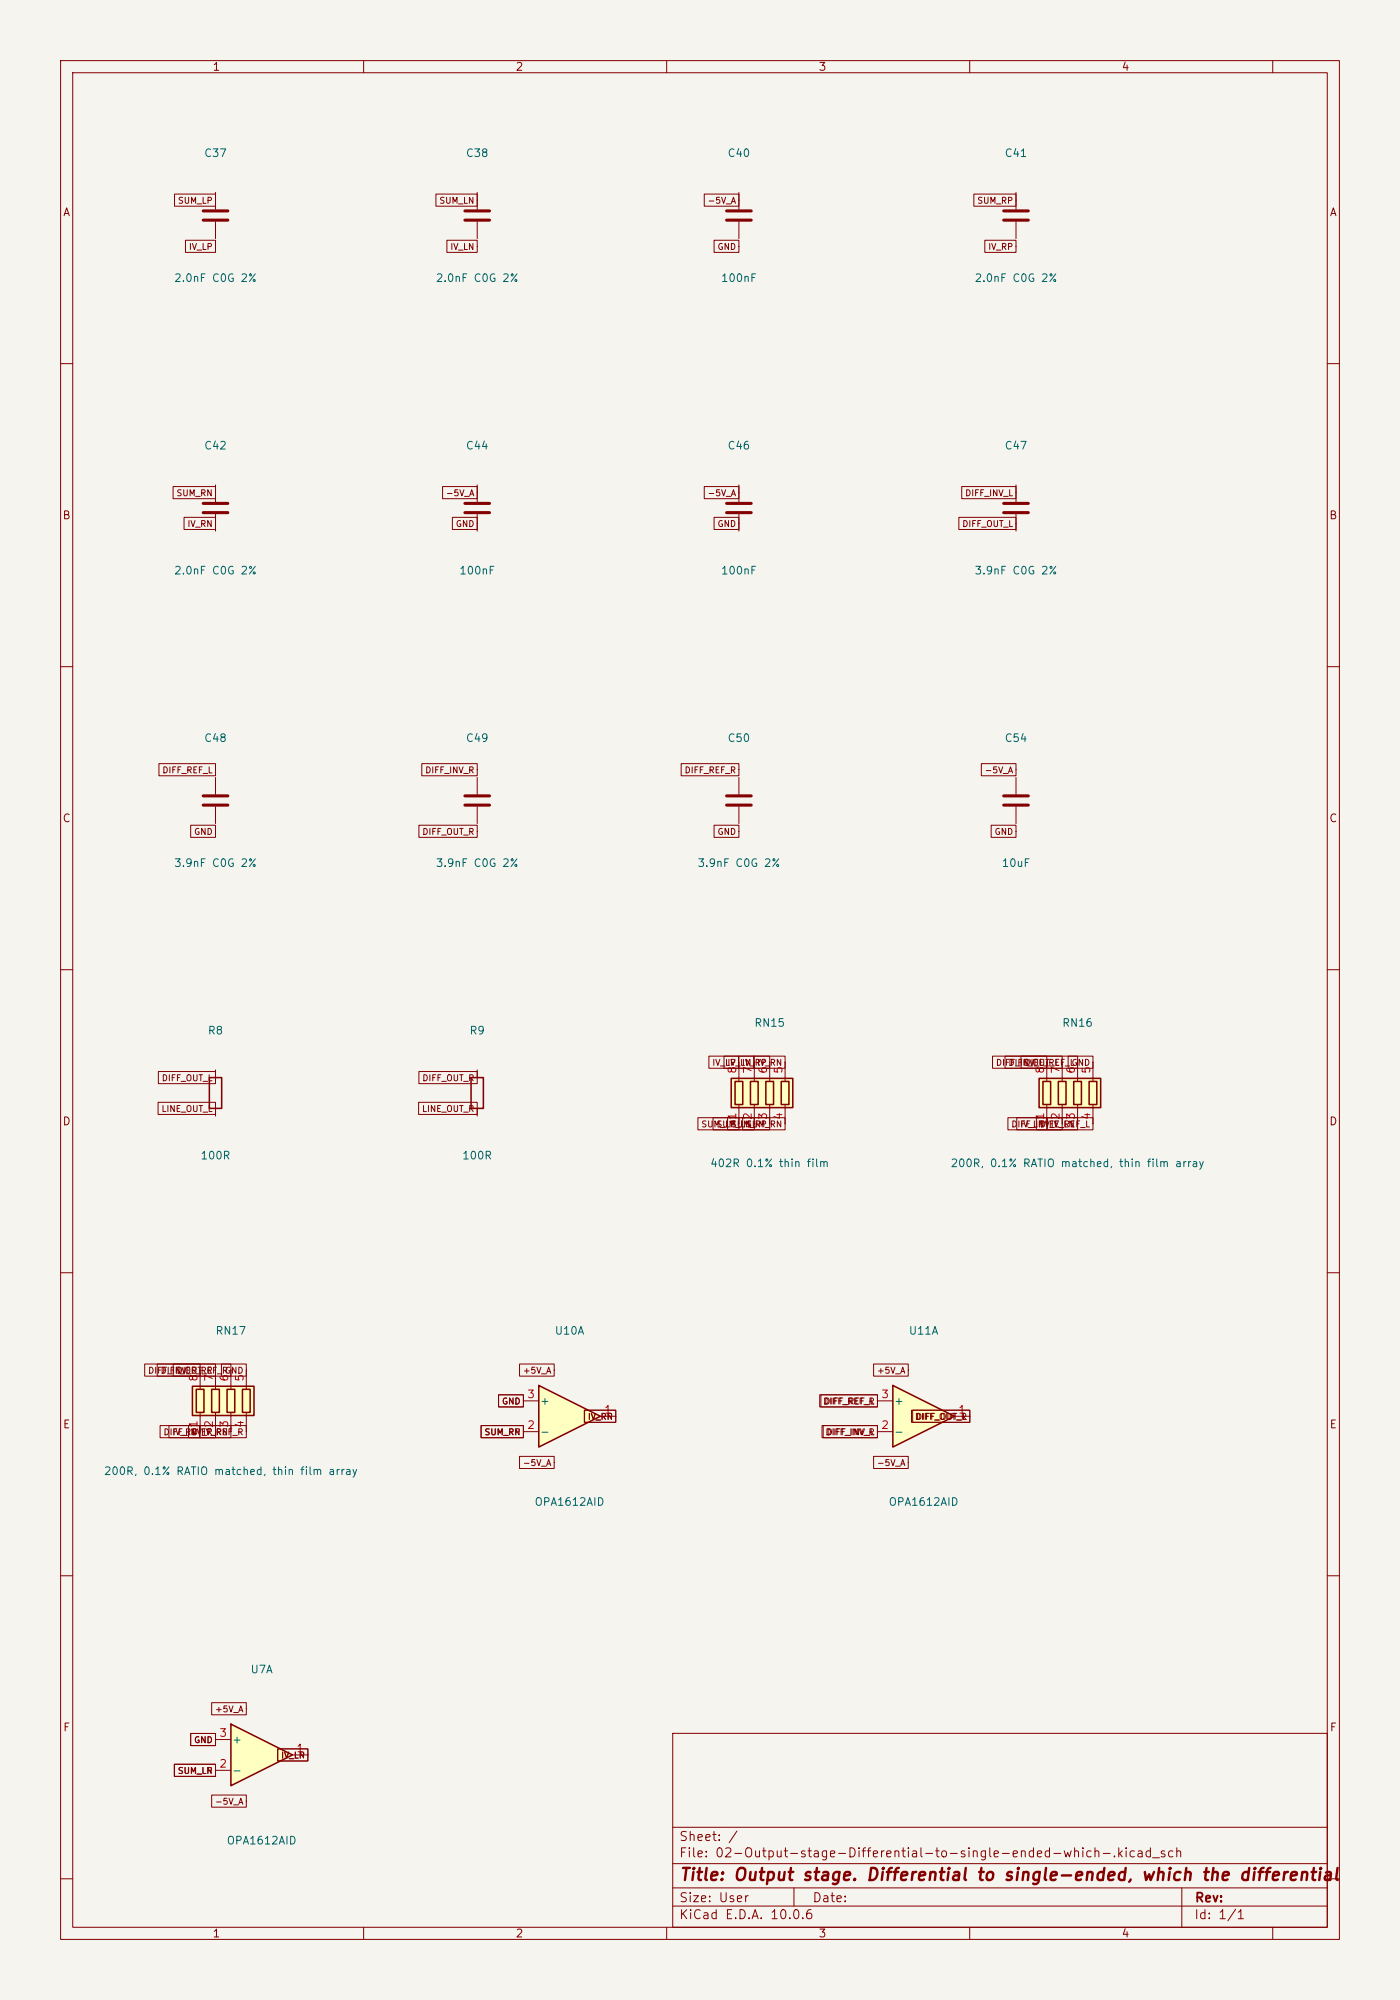
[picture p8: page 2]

200R, 0.1% RATIO matched, thin film array

Sheet: /
File: 02-Output-stage-Differential-to-single-ended-which-.kicad_sch
Title: Output stage. Differential to single-ended, which the differential

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
## F Date:

# Title: Reclocking registers, one package per channel so both polarities

## File: 03-Reclocking-registers-one-package-per-channel-so-.kicad_sch

## Sheet: /

C60

100nF | C58

100nF

1OE 1

1Q1 2
1Q2 3 GND

4

1Q3 5

1Q4 6 VCC

7

1Q5 8
1Q6 9 GND 10
1Q7 11
1Q8 12
2Q1 13
2Q2 14 GND 15
2Q3 16

2Q4 17 VCC 18

2Q5 19
2Q6 20 GND 21
2Q7 22
2Q8 23

2OE 24

2CLK 25

2D8 26 2D7 27 | GND 28
2D6 29 2D5 30 | VCC 31
2D4 32 2D3 33 | GND 34
2D2 35 2D1 36 1D8 37 1D7 38 | GND 39
1D6 40 1D5 41 | VCC 42
1D4 43 1D3 44 | GND 45

1D2 46 1D1 47

# 1CLK 48 U3

SN74ALVCH16374DGGR

C64

100nF

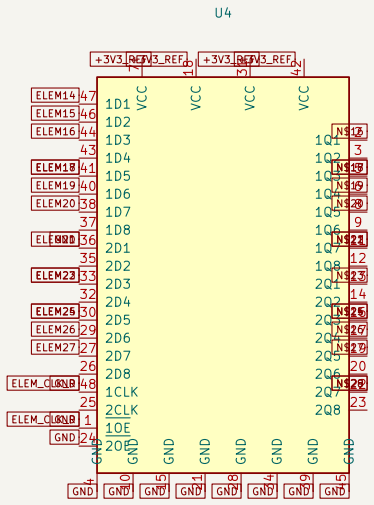
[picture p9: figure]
1Q1 2 1Q2 3 GND; 1Q4 6 VCC; 1Q5 8 1Q6 9 GND 10 1Q7 11 1Q8 12 2Q1 13 2Q2 14 GND 15 2Q3 16; 2Q4 17 VCC 18; 2Q5 19 2Q6 20 GND 21 2Q7 22 2Q8 23; 2CLK 25; GND 28; VCC 31; GND 34; GND 39; VCC 42; GND 45; 1CLK 48; ELEM15; ELEM16; ELEM178; ELEM19; ELEM20; ELEM21 GND; ELEM223; ELEM245; ELEM26; ELEM27; ELEM_CLK_R; GND

SN74ALVCH16374DGGR

C59

# 100nF C63

100nF C32

10uF | C62

100nF C61

# 100nF C57

100nF

GND

N$15

# +3V3_REF GND

GND | GND +3V3_REF | GND +3V3_REF | +3V3_REF | +3V3_REF GND

GND

+3V3_REF | +3V3_REF +3V3_REF | N$16 N$17 +3V3_REF ELEM14
+3V3_REF | +3V3_REF ELEM0
ELEM1+3V3_REF | +3V3_REF ELEM2

ELEM8
ELEM9

ELEM34
ELEM5
ELEM6
ELEM7 GND | N$2 N$34 N$5 N$6
GND | GND | GND | GND | N$245 N$26 N$27 N$289 N$23 GND | GND | GND | GND

GND

ELEM10
ELEM11

ELEM123 +3V3_REF GND

+3V3_REF

GND | GND | GND | GND | GND

ELEM_CLK_L ELEM_CLK_L GND

GND

GND

GND | N$9 GND | GNDN$10 N$78

+3V3_REF

# N$11 N$123 N$14

+3V3_REF

GND | +5V +5V_A | GND

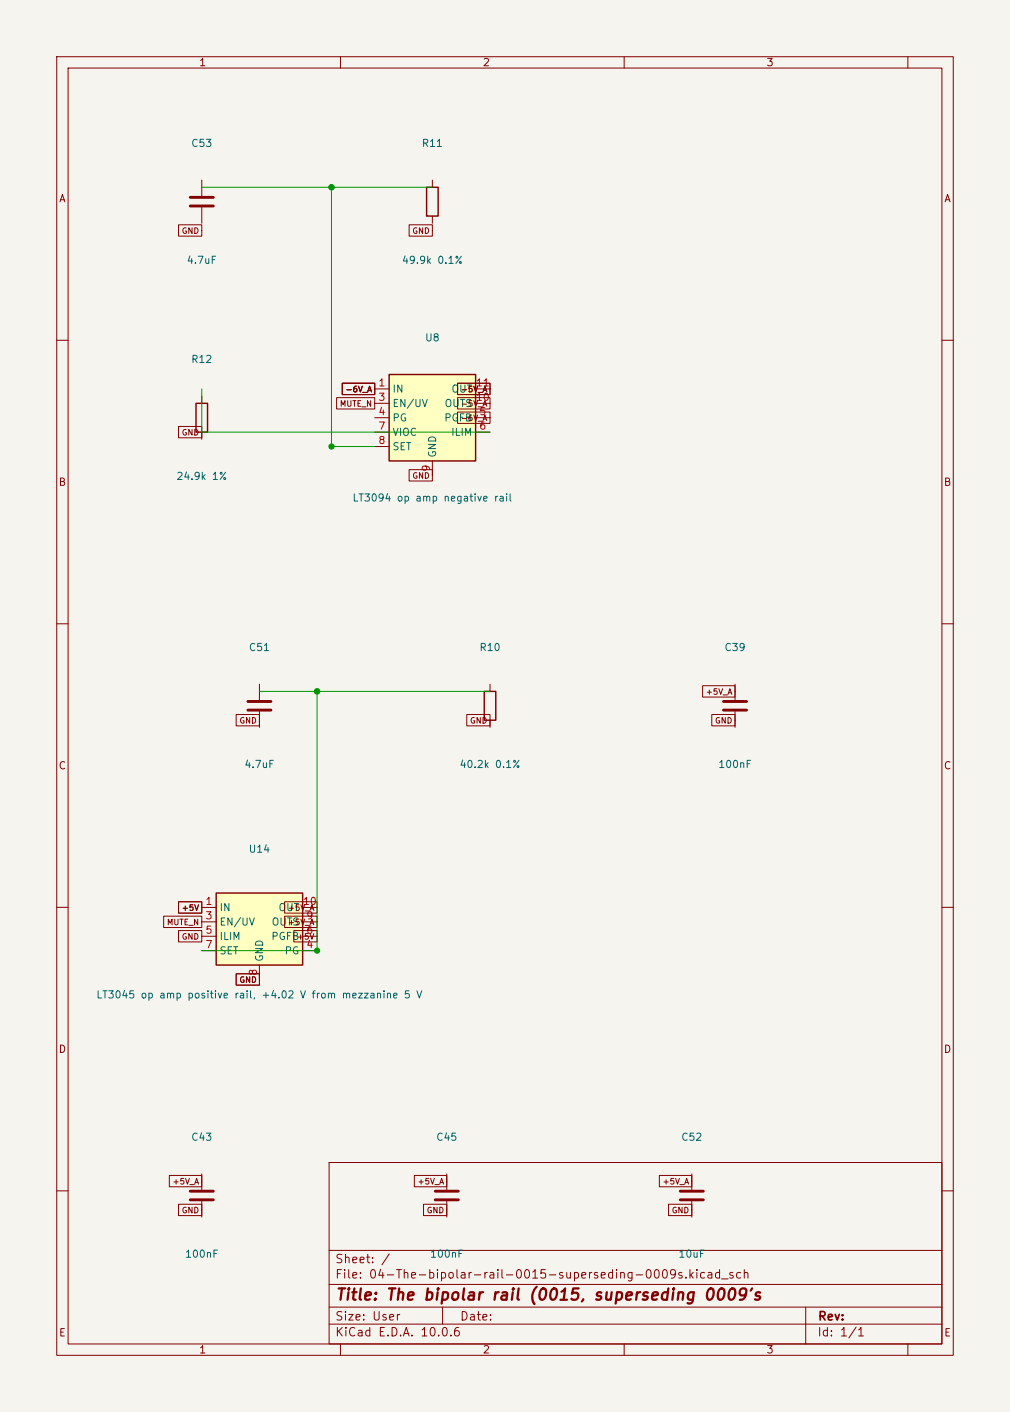
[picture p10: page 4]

LT3094 op amp negative rail MUTE_N

Sheet: /
File: 04-The-bipolar-rail-0015-superseding-0009s.kicad_sch
Title: The bipolar rail (0015, superseding 0009's

# LT3045 element reference C31

# +3V3_REF +3V3_REF GND +5V

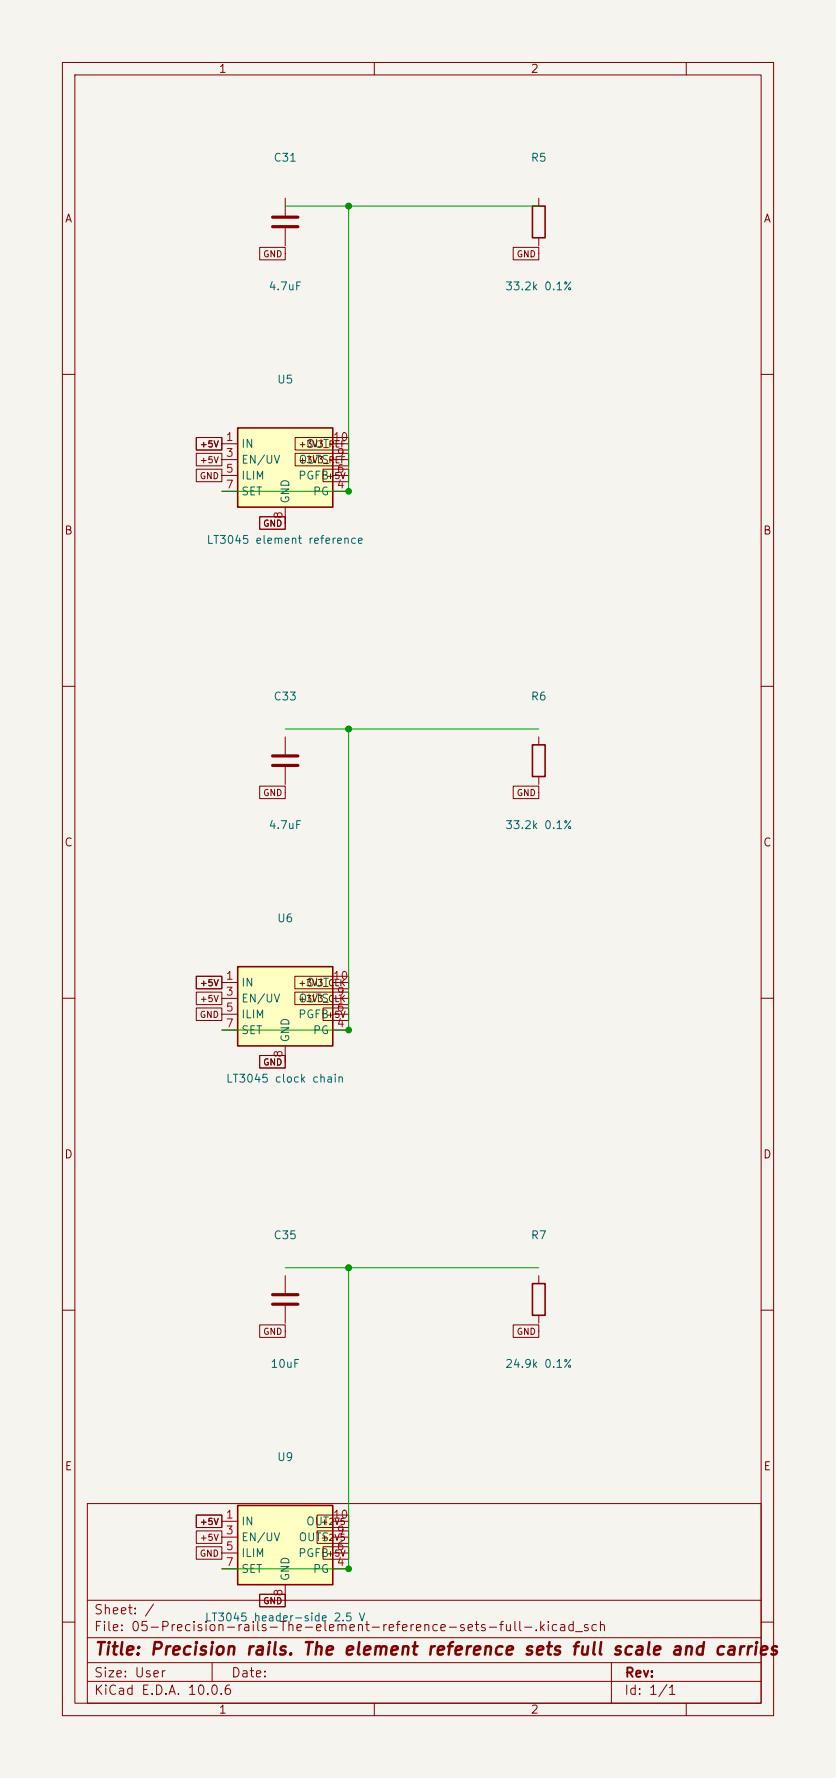
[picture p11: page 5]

Sheet: /
File: 05-Precision-rails-The-element-reference-sets-full-.kicad_sch
Title: Precision rails. The element reference sets full scale and carries

# Y2 CCHD-957X-25-45.1584 CLK 1 D

# GND +3V3_CLK

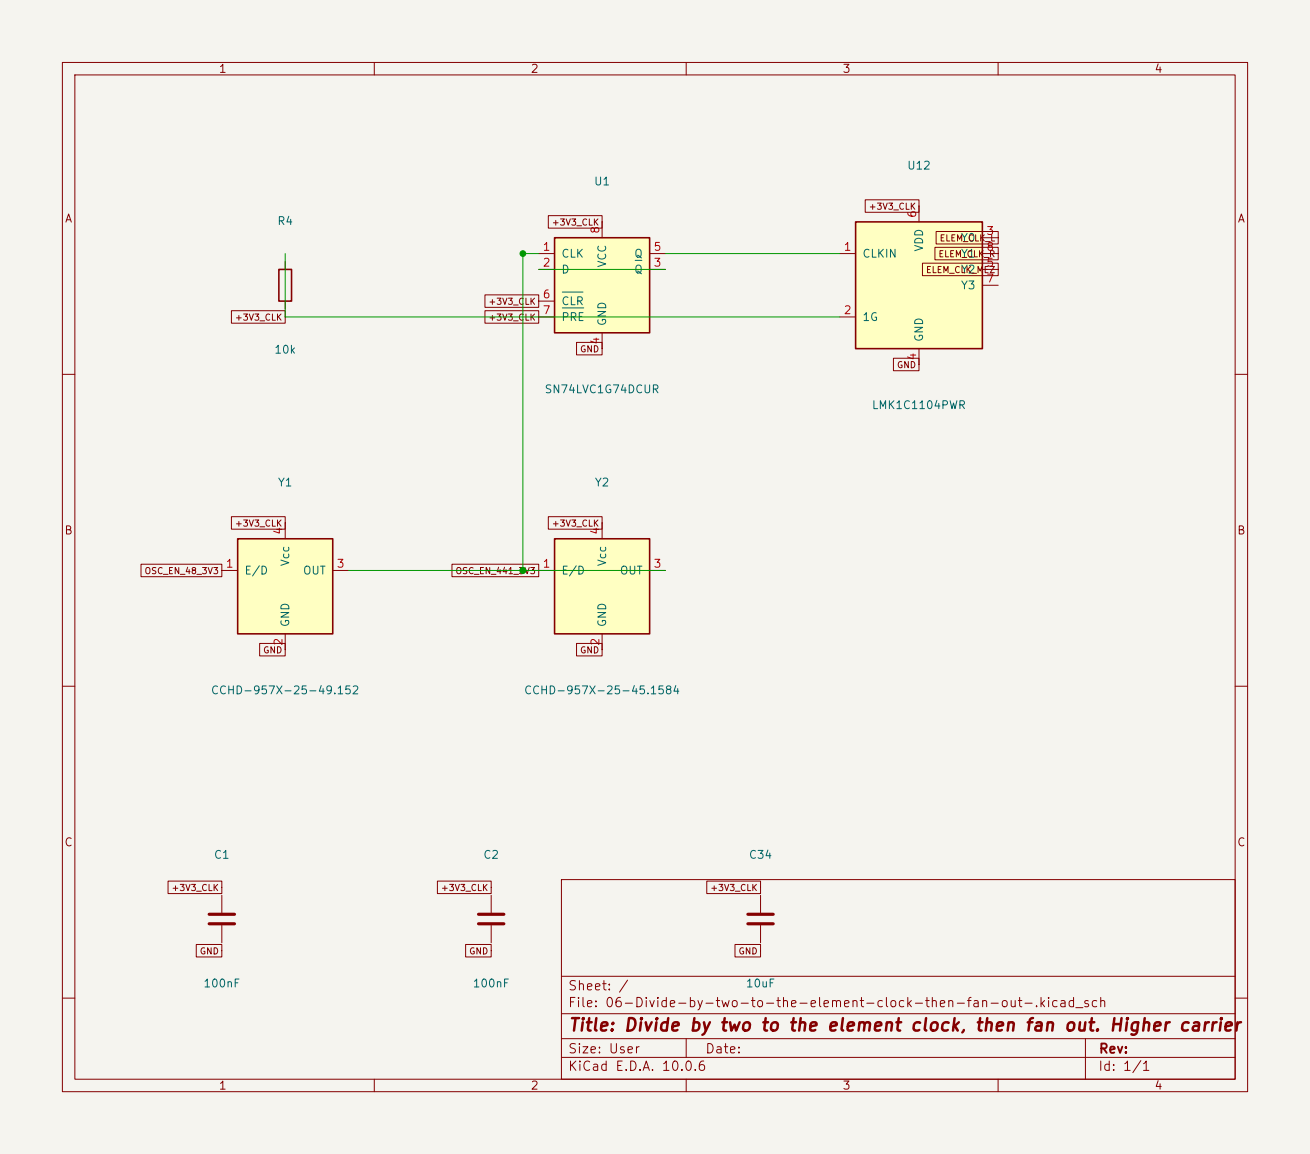
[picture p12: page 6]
C Date:; Size: User; Rev:; GND; 2 OUT Vcc 3; 3 GND; 5 CLR 6 PRE 7; VCC; SN74LVC1G74DCUR; CLKIN 1; Y0 3 GND; Y2 5 VDD; LMK1C1104PWR; Y1 CCHD-957X-25-49.152; +3V3_CLK; ELEM_CLK_L ELEM_CLK_MEZ; ELEM_CLK_R +3V3_CLK; OSC_EN_441_3V3 +3V3_CLK; GND OSC_EN_48_3V3 GND +3V3_CLK

Sheet: /
File: 06-Divide-by-two-to-the-element-clock-then-fan-out-.kicad_sch
Title: Divide by two to the element clock, then fan out. Higher carrier

AB

C

D

E

AB

C

D

## E Date:

# Title: Mezzanine header, mating with the main board's J2

## File: 07-Mezzanine-header-mating-with-the-main-boards-J2.kicad_sch

## Sheet: /

R13

1k 1 | 2
3 | 4
5 | 6
7 | 8
9 | 10
11 | 12
13 | 14
15 | 16
17 | 18
19 | 20
21 | 22
23 | 24
25 | 26
27 | 28
29 | 30
31 | 32
33 | 34
35 | 36
37 | 38
39 | 40
41 | 42
43 | 44
45 | 46
47 | 48
49 | 50
51 | 52
53 | 54
55 | 56
57 | 58
59 | 60
61 | 62
63 | 64
65 | 66
67 | 68
69 | 70
71 | 72
73 | 74
75 | 76
77 | 78
79 | 80

# J1 Mezzanine 2x40

C36

10uF VCCA 1

1DIR 2
2DIR 3

1A1 4
1A2 5
2A1 6
2A2 7 | GND

8

2B2 10 2B1 11 1B2 12 1B1 13

2OE 14 1OE 15 | VCCB 16 U2

74AVC4T245 R3

100k

R1

100k

R2

100k R14

10k

MUTE_N

GND

ELEM4

ELEM10

ELEM11

ELEM5

ELEM6

ELEM7

ELEM8

ELEM9 | GND | +2V5 GND

GND

ELEM2

GND

GNDOSC_EN_441_3V3 OSC_EN_48_3V3 GND

GND

GND | GND

ELEM1

OSC_EN_48_3V3

# ELEM0 GND

GND

GND | GND OSC_EN_441_3V3

GND

GND

GND +5V +5V -6V_A | -6V_A GND | +2V5 GND

GND

GND

ELEM_CLK_MEZ +2V5 +3V3_CLK

+2V5

ELEM17

ELEM18

ELEM19

ELEM20

ELEM21

ELEM22

ELEM23

ELEM24

ELEM25

ELEM26

ELEM27

ELEM28

ELEM29

ELEM30

ELEM31 | GND
| GND
| GND
| GND
| GND
| GND
| GND
| GND
| GND
| GND
| GND MUTE_N

GND

GND

GND

GND

GND

GND

GND

ELEM12

ELEM13

ELEM14

ELEM15

ELEM16 | GND
| GND
| GND

GND

GND

GND

GND

GND

GND

ELEM3

1

1

AB

C

AB

### C Date:

Size: User | Rev: Id: 1/1

C55

100pF C0G

C56

100pF C0G

R

S

T

J2

SJ1-3523N

LINE_OUT_R

GND

# LINE_OUT_L GND

LINE_OUT_R

GND

LINE_OUT_L

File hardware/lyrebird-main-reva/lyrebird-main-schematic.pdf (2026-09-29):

1 | 2 | 3 | 4 | 5 | 6 | 7 | 8 | 9

AB

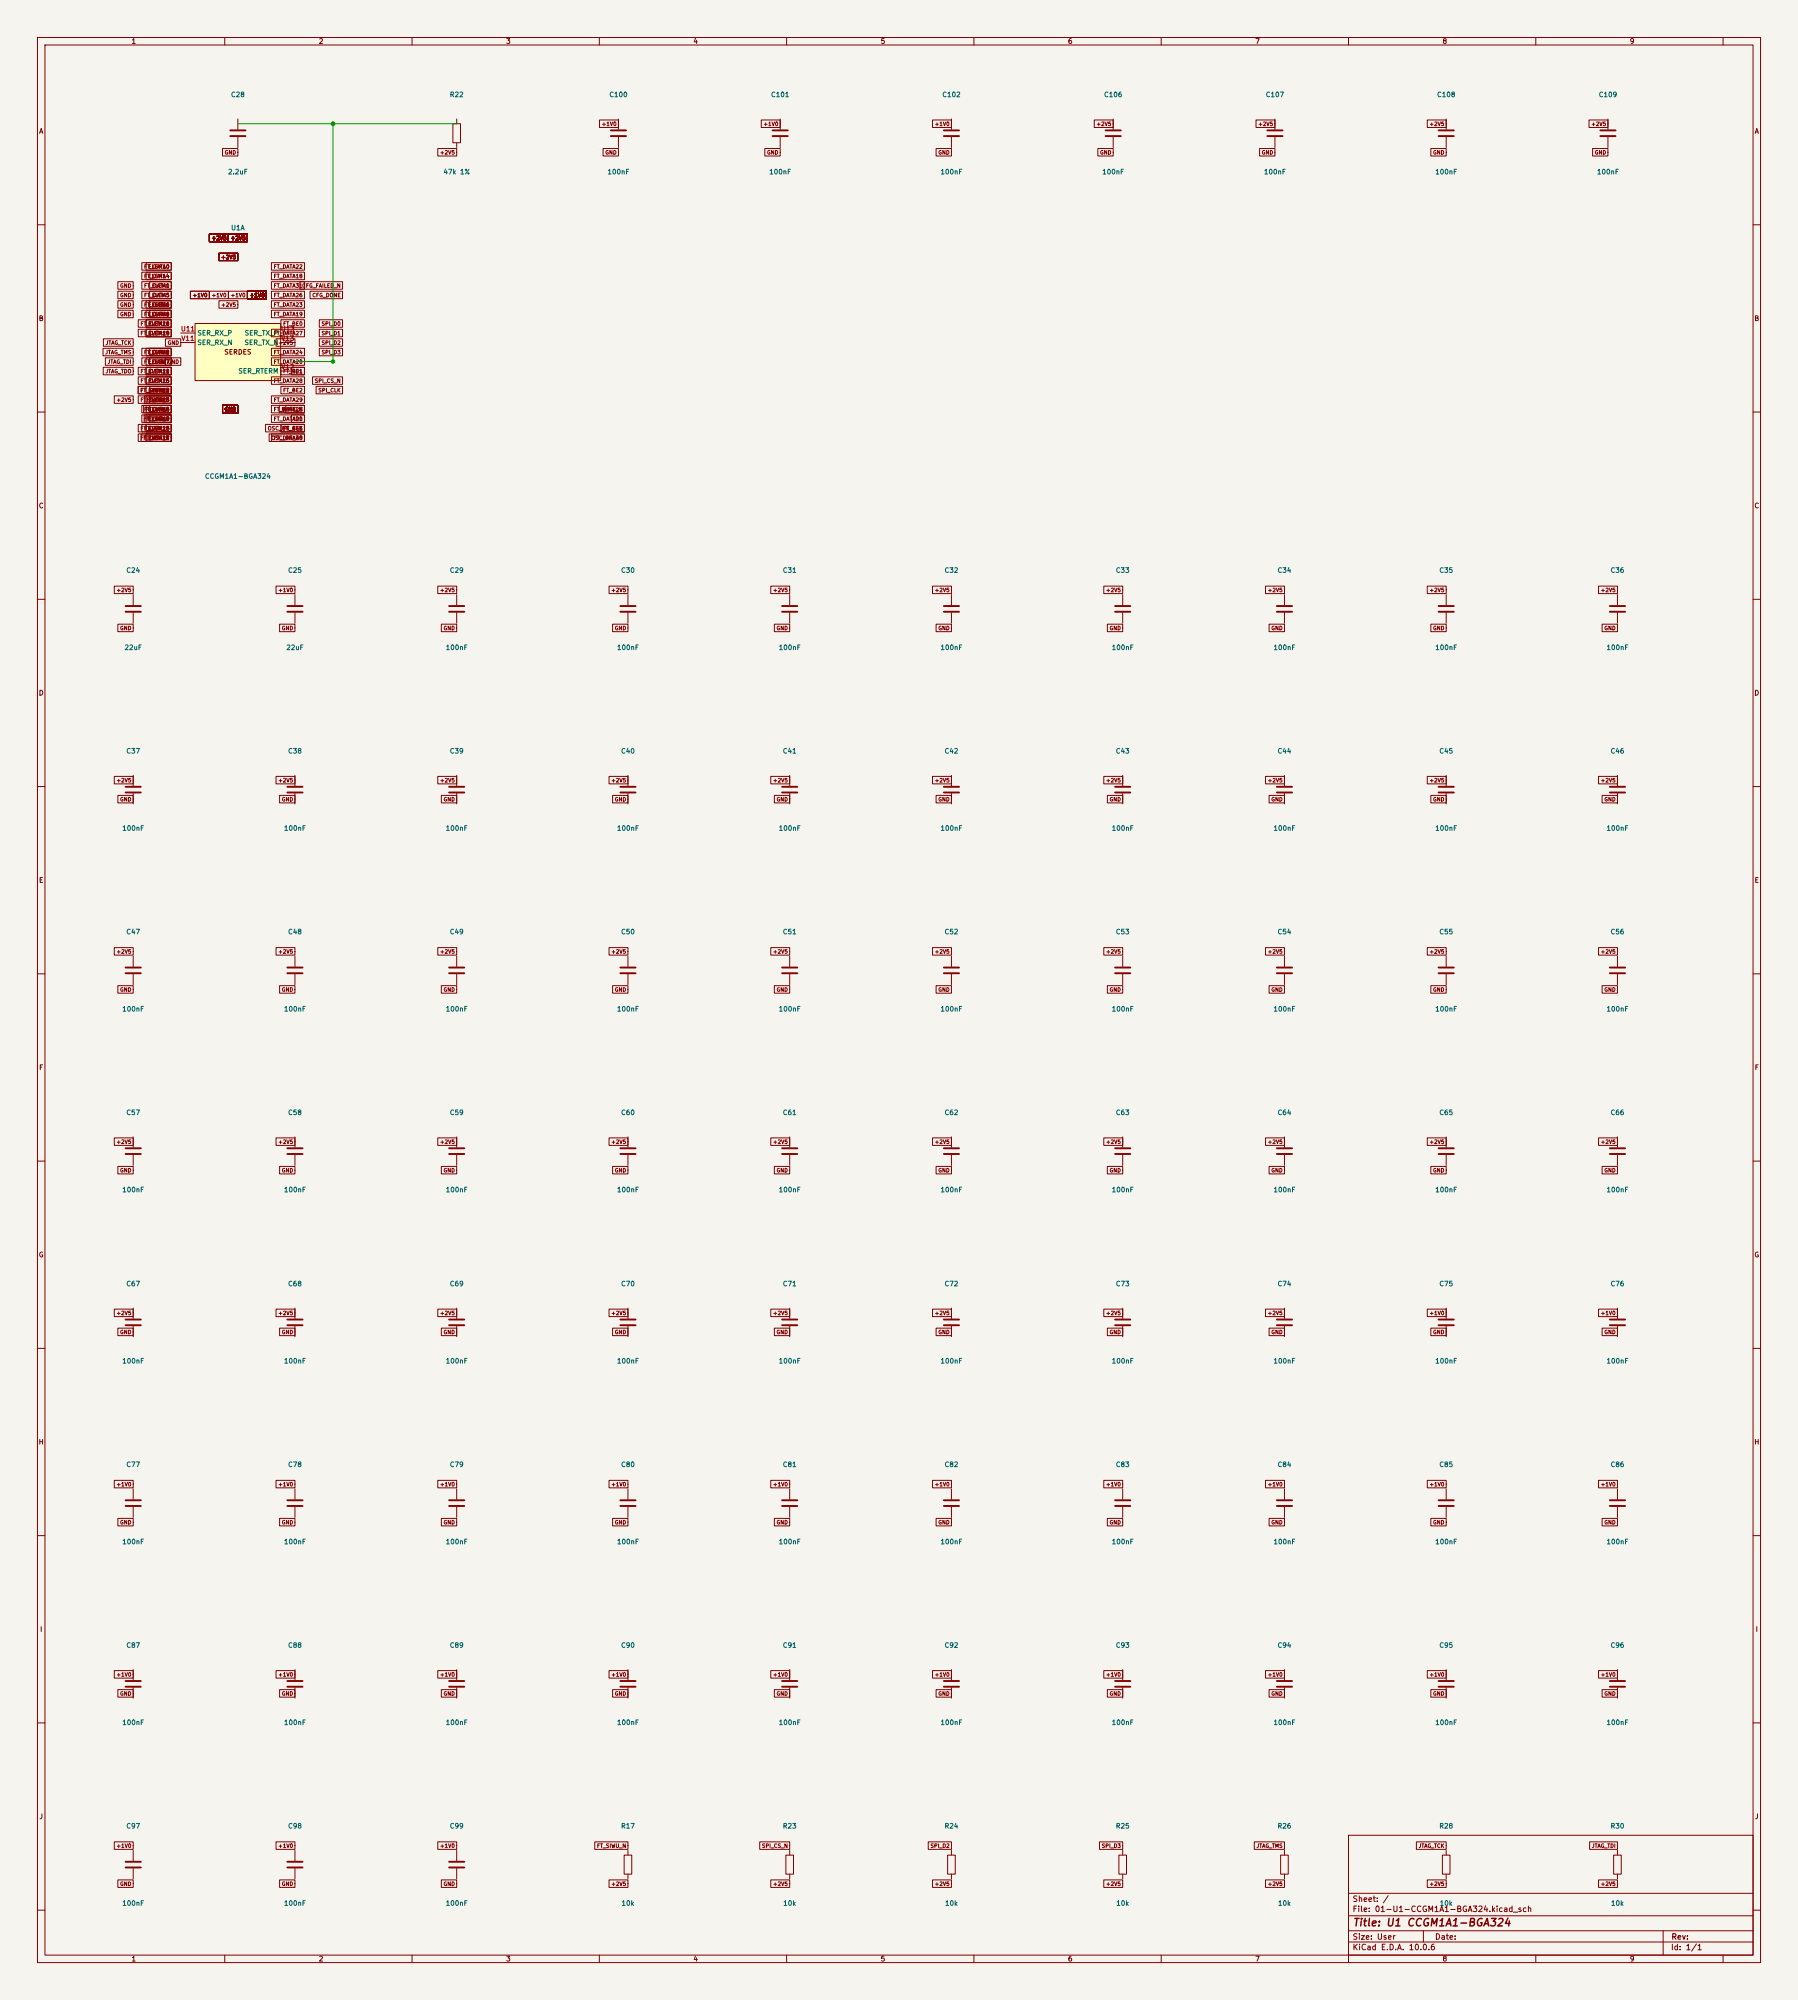
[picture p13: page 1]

1 | 2 | 3 | 4 | 5 | 6

AB

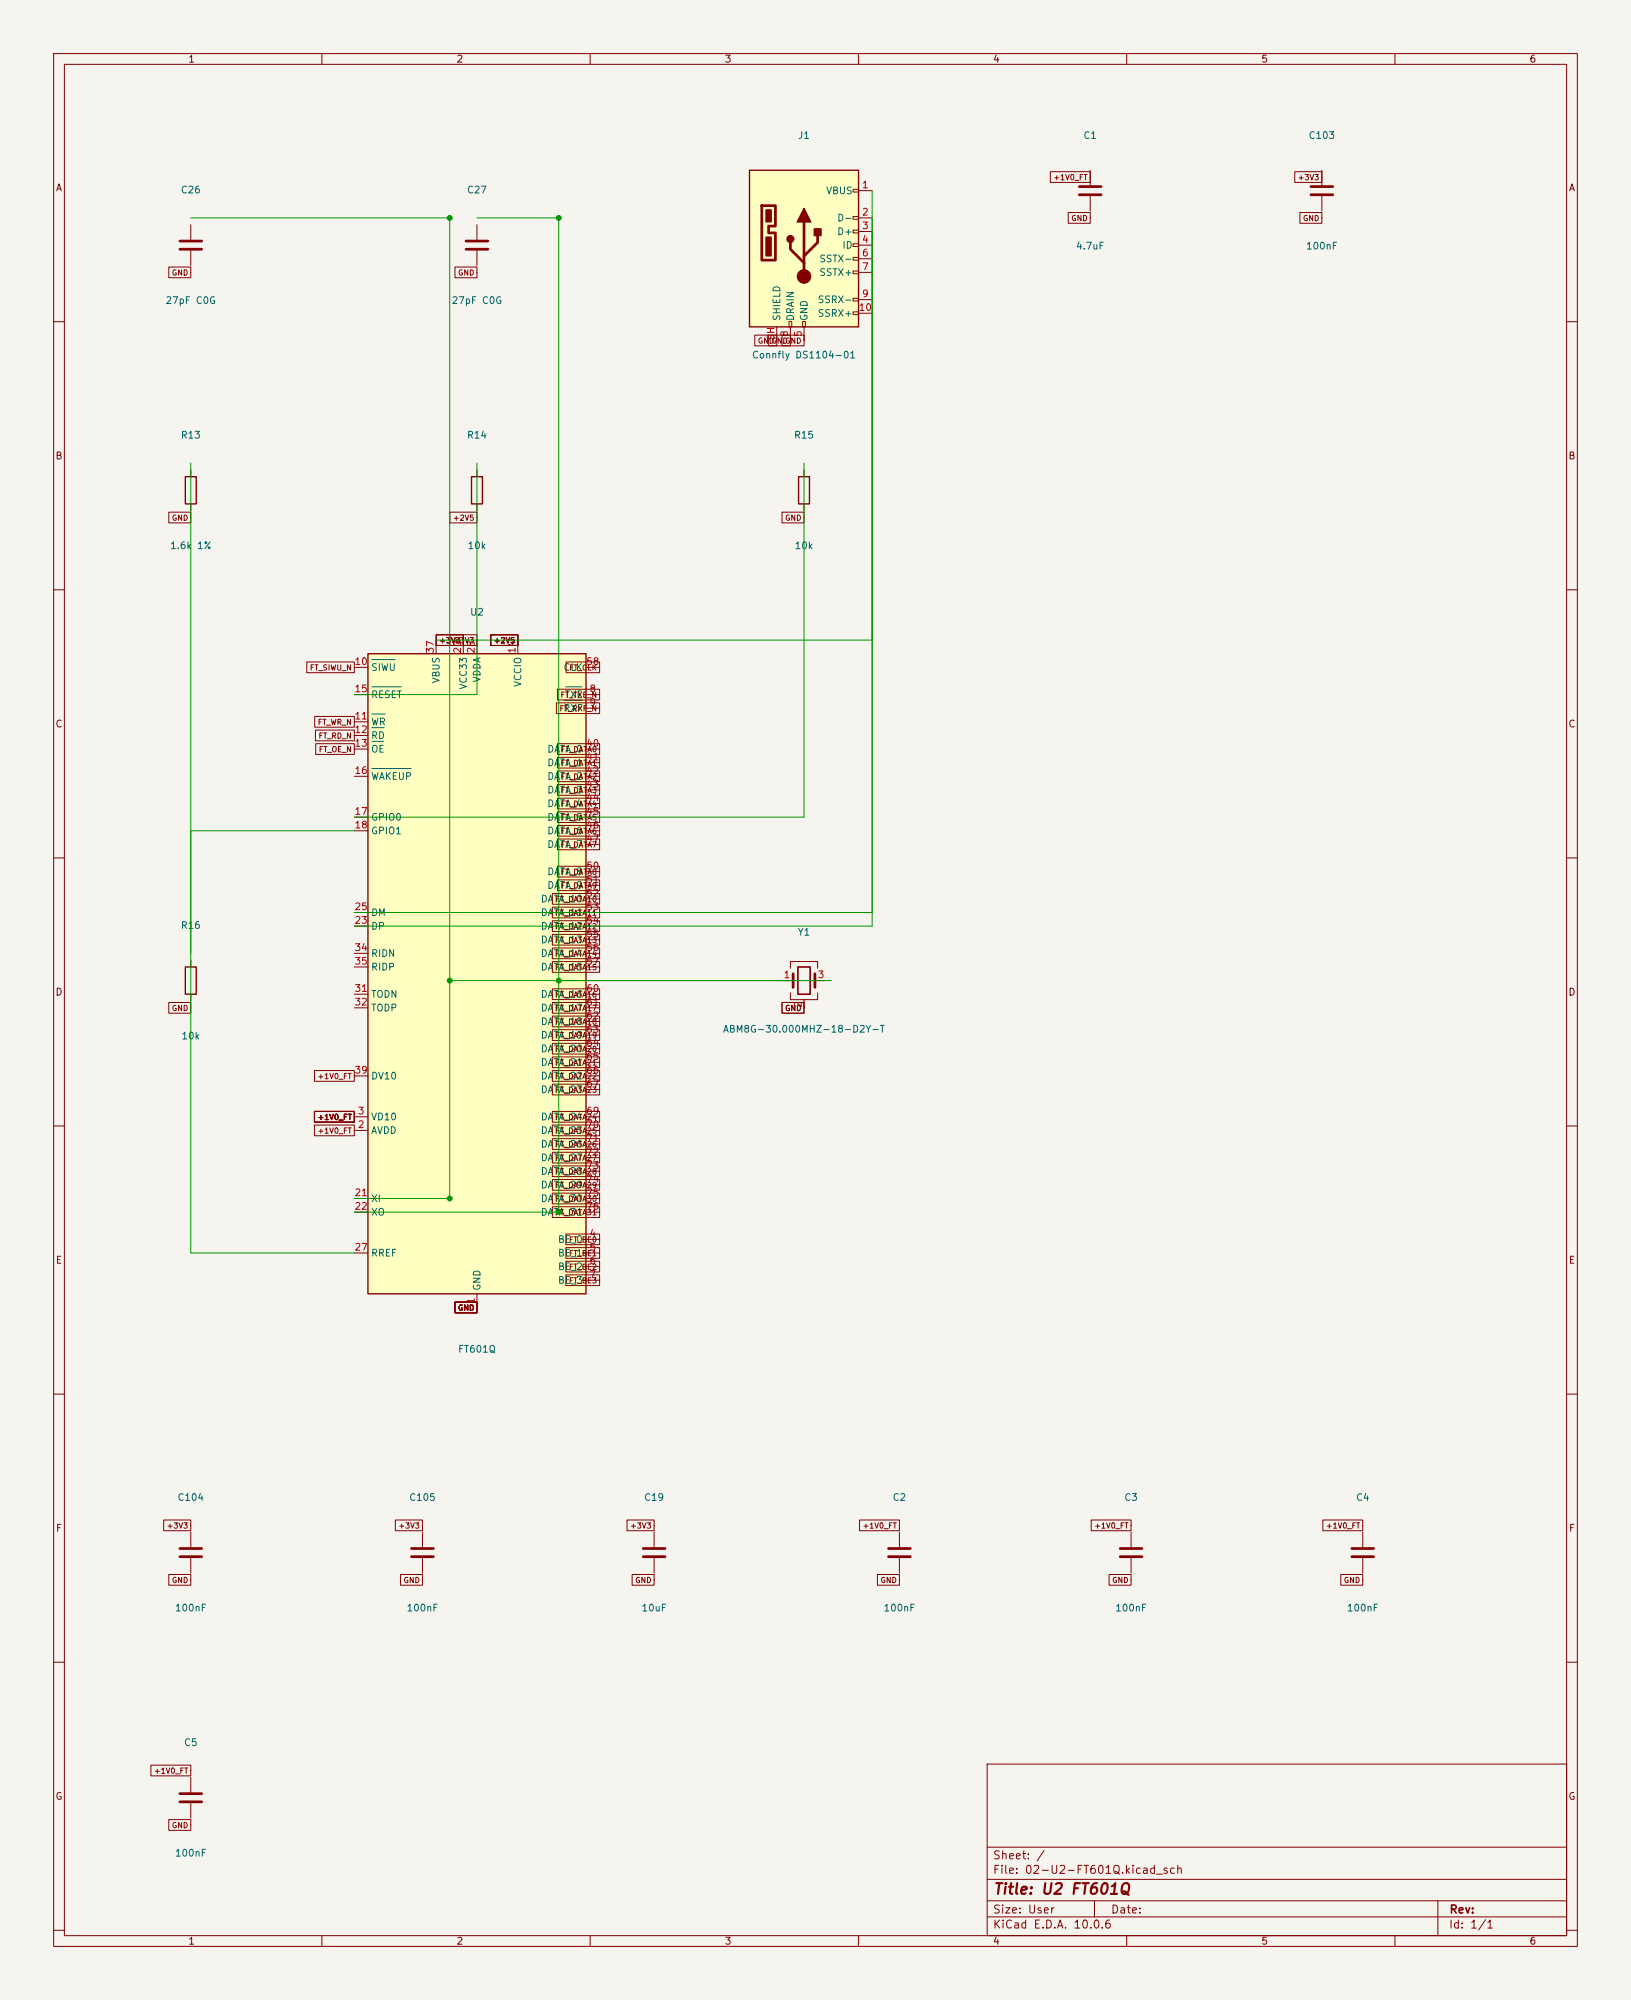
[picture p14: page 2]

1 | 2 | 3 | 4

AB

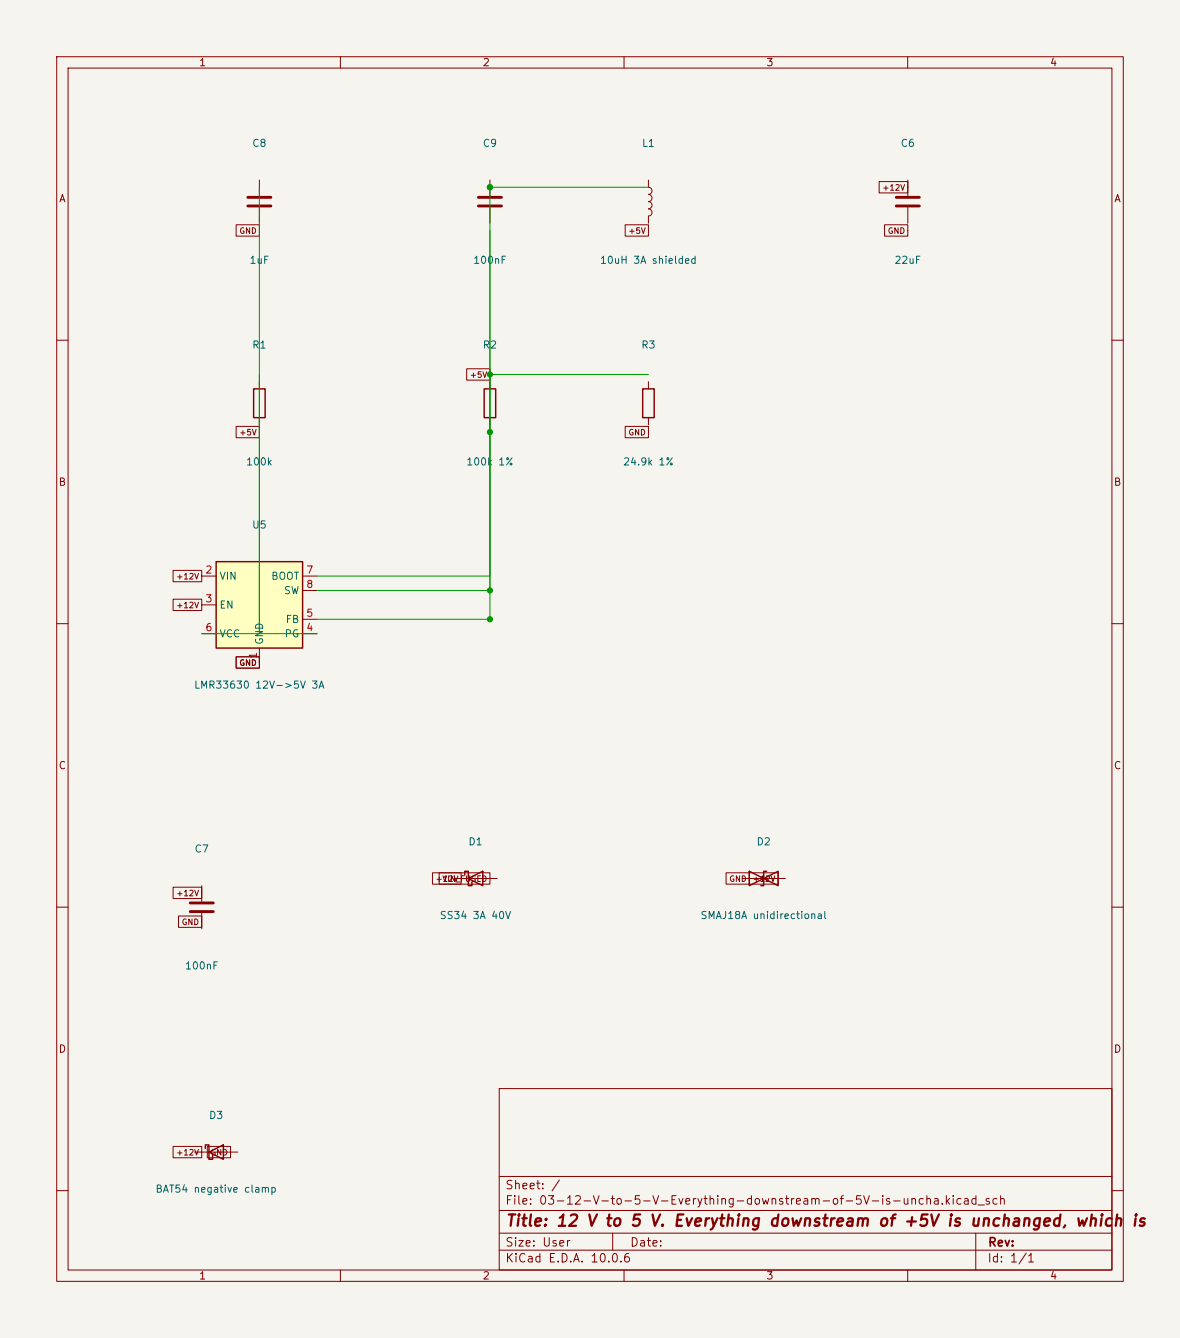
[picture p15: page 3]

Sheet: /
File: 03-12-V-to-5-V-Everything-downstream-of-5V-is-uncha.kicad_sch
Title: 12 V to 5 V. Everything downstream of +5V is unchanged, which is

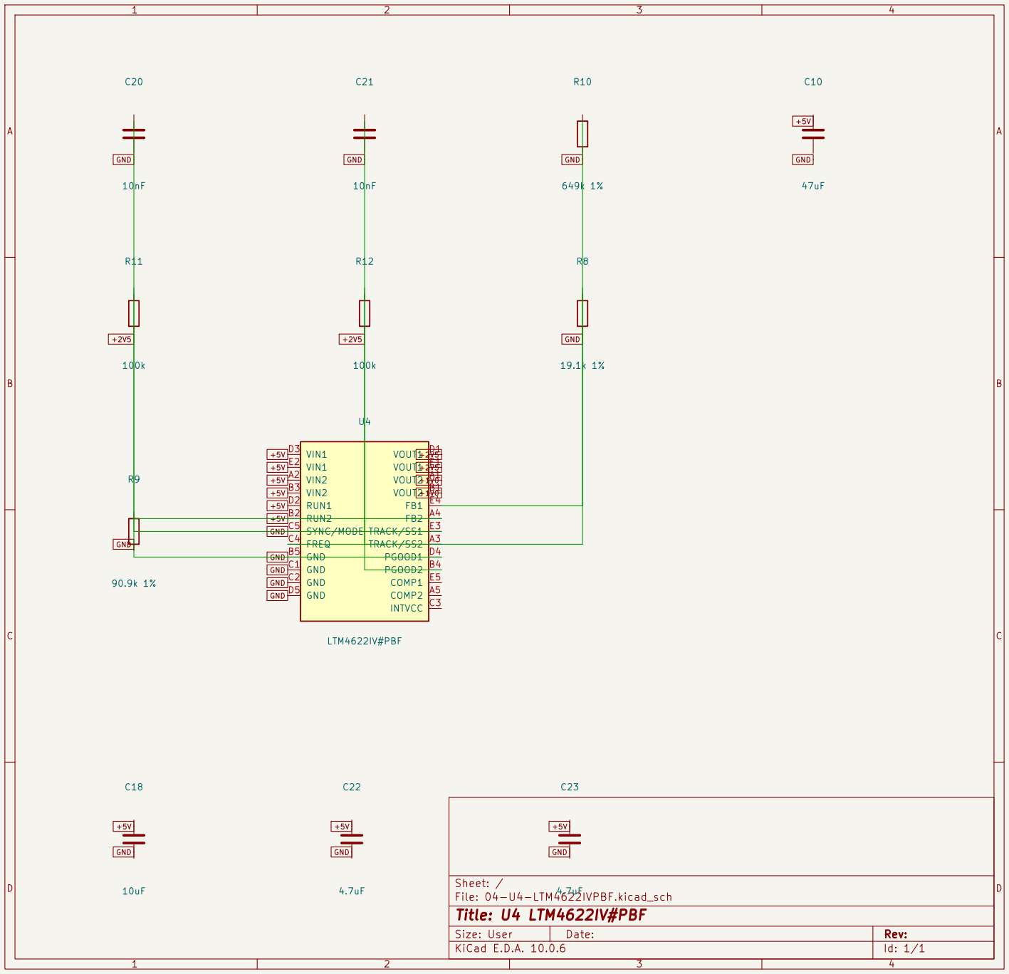
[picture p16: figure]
D Date:; Title: U4 LTM4622IV#PBF; File: 04-U4-LTM4622IVPBF.kicad_sch; Sheet: /; VOUT2 A1 VIN2 A2; TRACK/SS2 A3; FB2 A4 COMP2 A5; VOUT2 B1 RUN2 B2; VIN2 B3; PGOOD2 B4 GND B5 GND C1 GND C2; INTVCC C3; FREQ C4 SYNC/MODE C5; VOUT1 D1 RUN1 D2; VIN1 D3; PGOOD1 D4 GND D5; VOUT1 E1 VIN1 E2; TRACK/SS1 E3; FB1 E4 COMP1 E5 U4; LTM4622IV#PBF; 100k +5V GND; GND +5V; GND; +5V GND; +5V GND +5V

1 | 2 | 3
1 | 2 | 3

AB

C

D

E

AB

C

D

## E Date:

# Title: Mezzanine header: 32 element lines each beside a ground, MCLK back

## File: 05-Mezzanine-header-32-element-lines-each-beside-a-.kicad_sch

## Sheet: /

C15

### 10uF C13

47uF | 1 | 2
3 | 4
5 | 6
7 | 8
9 | 10
11 | 12
13 | 14
15 | 16
17 | 18
19 | 20
21 | 22
23 | 24
25 | 26
27 | 28
29 | 30
31 | 32
33 | 34
35 | 36
37 | 38
39 | 40
41 | 42
43 | 44
45 | 46
47 | 48
49 | 50
51 | 52
53 | 54
55 | 56
57 | 58
59 | 60
61 | 62
63 | 64
65 | 66
67 | 68
69 | 70
71 | 72
73 | 74
75 | 76
77 | 78
79 | 80
J2 Mezzanine 2x40 | R21

10k R20

10k R19

10k

C16

100nF | R18

10k C14

100nF

GND

OSC_EN_48

+12V

ID0 GND

GND

GND

GND

ELEM1

ELEM2

ELEM3

ELEM4

ELEM5

ELEM0 | GND
| GND
| GND

# GND +5V -6V_A GND

GND

ID0 OSC_EN_441 GND | GND

ID1

-6V_A

OSC_EN_48

-6V_A

+5V | GND

GND

-6V_A

-6V_A GND

GND

GND

ELEM10

ELEM11

ELEM12

ELEM13

ELEM14

ELEM15

ELEM16

ELEM17

ELEM18

ELEM19

ELEM6

ELEM7

ELEM8

ELEM9 | GND
| GND
| GND
| GND
GND +12V | GND

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
ELEM20

ELEM21

ELEM22

ELEM23

ELEM24

ELEM25

ELEM26

ELEM27

ELEM28

ELEM29 | GND
| GND
| GND
| GND
| GND
| GND
| GND
| GND
| GND
| GND OSC_EN_441 GND

GND

ID1 MUTE_N

ELEM30

ELEM31 MCLK

-6V_A

1 | 2 | 3

AB

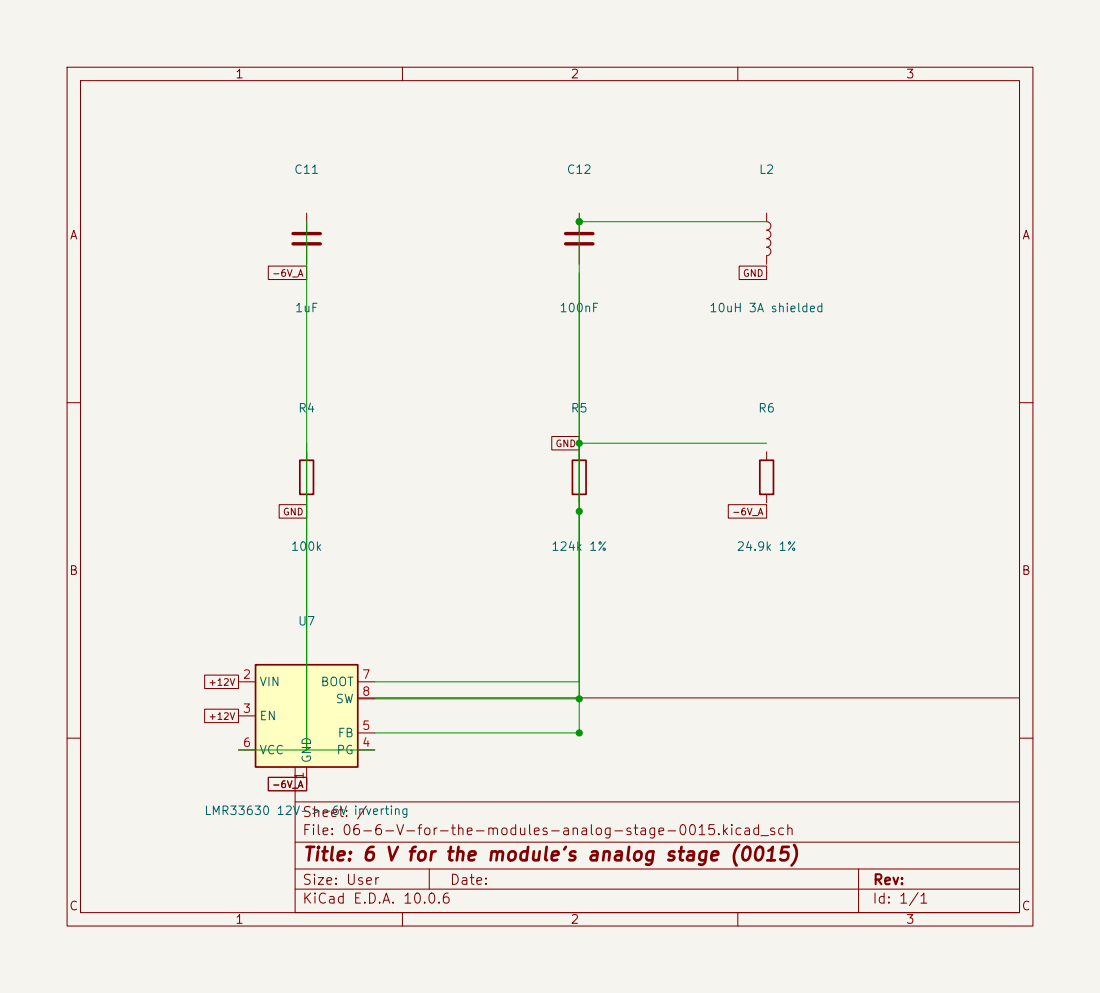
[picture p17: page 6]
C Date: KiCad E.D.A. 10.0.6; Size: User; Rev:; 10uH 3A shielded GND; VIN 2; VCC 6; BOOT 7; LMR33630 12V->-6V inverting; GND

Sheet: /
File: 06-6-V-for-the-modules-analog-stage-0015.kicad_sch
Title: 6 V for the module's analog stage (0015)

1 | 2
1 | 2

AB

C

AB

## C Date:

## KiCad E.D.A. 10.0.6

Size: User | Rev: Id: 1/1

# Title: Programming header. No programming silicon on the board: 0006

## File: 07-Programming-header-No-programming-silicon-on-the.kicad_sch

## Sheet: /

1 | 2
3 | 4
5 | 6
7 | 8
9 | 10

J3

### JTAG 2x5 1.27mm

R32

10k

R27

1k 1%

R31

1k 1%

R29

1k 1%

JTAG_TDO +2V5 CFG_DONE GND

GND

CFG_FAILED_N +2V5

JTAG_TMS

JTAG_TDI GND CFG_FAILED_N

JTAG_TCK

1 | 2

C17

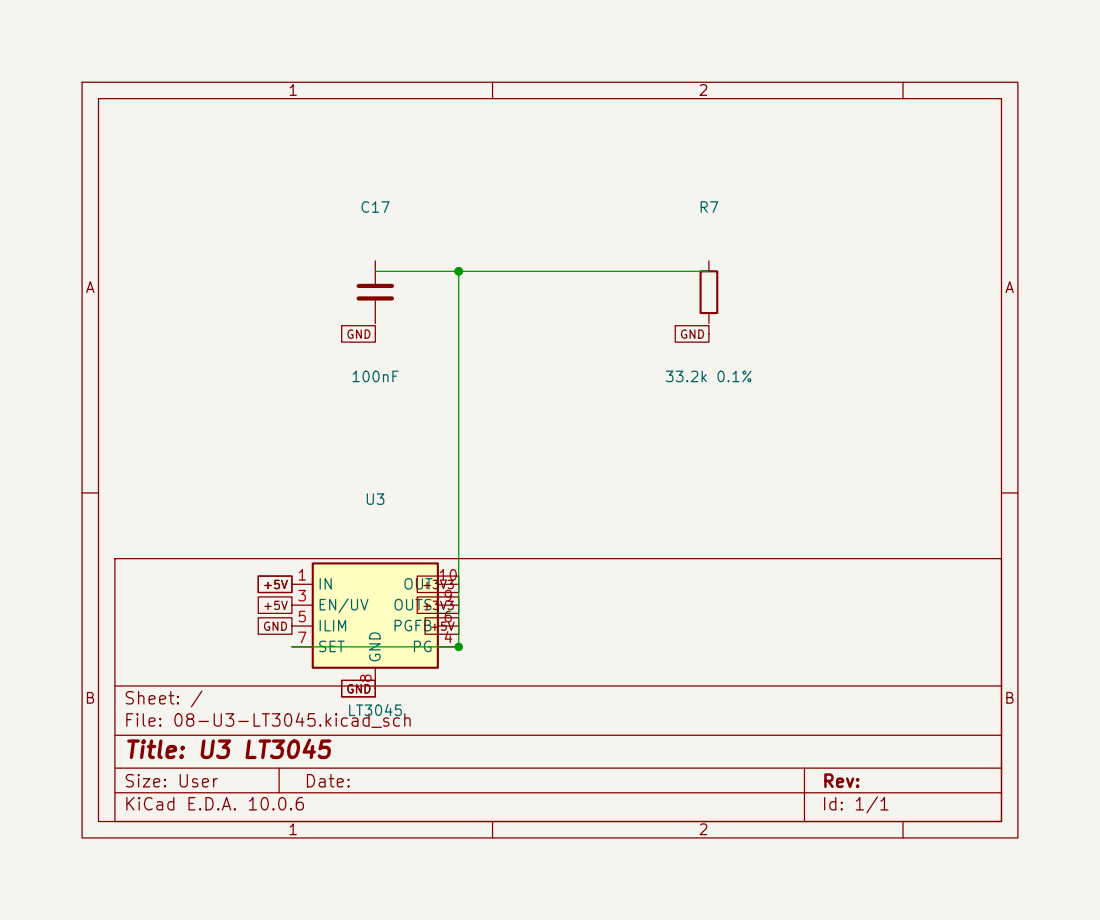
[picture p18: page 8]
AB Date:; KiCad E.D.A. 10.0.6; Size: User; Rev:; Title: U3 LT3045; File: 08-U3-LT3045.kicad_sch; Sheet: /; ILIM 5; PGFB 6; SET 7; GND; 8 OUTS 9 OUT 10 U3; +5V +3V3 +3V3 +5V +5V GND

1 | 2

A Date:; KiCad E.D.A.; Size: User; Rev:; Title: Other; File:; 09-Other.kicad_sch; Sheet: /; 1812L050/30 PPTC 0.5A hold 30V 100A; VIN_FUSED; GND F1

12 V 2.1 x 5.5 mm, centre positive 1

12 V 2.1 x 5.5 mm, centre positive

1 | 2
1 | 2
A | A Date:
KiCad E.D.A. | 10.0.6
Size: User | Rev: Id: 1/1

# Title: U6 MX25R6435F 64Mb

## File: 10-U6-MX25R6435F-64Mb.kicad_sch

## Sheet: /

CS 1

SO/SIO1 | 2 WP/SIO2 | 3 GND 4

### SI/SIO0 5

SCLK 6 | RESET/SIO3 | 7
VCC | 8 U6 MX25R6435F 64Mb

SPI_D3 +2V5

SPI_D1

SPI_D2 GND

SPI_CLK

SPI_CS_N

SPI_D0

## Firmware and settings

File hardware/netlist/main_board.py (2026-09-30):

#!/usr/bin/env python3
"""Main board netlist: USB bridge, FPGA, power tree, mezzanine header.

    KICAD10_SYMBOL_DIR=... python hardware/netlist/main_board.py

Emits a KiCad netlist and a BOM into hardware/lyrebird-main-reva/.

Every design choice here traces to a decision record. Bank allocation is
against the real ball map in the stock KiCad GateMate symbol, not invented.
"""

from __future__ import annotations

import sys
from pathlib import Path

HERE = Path(__file__).resolve().parent
sys.path.insert(0, str(HERE))

from skidl import Net, Part, generate_netlist, generate_xml  # noqa: E402
import lyrebird_parts as lp  # noqa: E402

OUT = HERE.parent / "lyrebird-main-reva"
N_ELEM = 32          # provisioned, 28 used (0008/0012)
N_DATA = 32

# Footprints for the passive sizes actually used here.
FP_C = {"0402": "Capacitor_SMD:C_0402_1005Metric",
        "0603": "Capacitor_SMD:C_0603_1608Metric",
        "0805": "Capacitor_SMD:C_0805_2012Metric",
        # Bulk on the 12 V input and the 5 V output. A 22 uF or 47 uF part
        # with usable derating at these voltages does not come in 0805.
        "1210": "Capacitor_SMD:C_1210_3225Metric"}
FP_R = "Resistor_SMD:R_0402_1005Metric"


def rails():
    # +1V0_FT is the FT601Q's own internal LDO output. It is a separate net
    # from the board's +1V0: the datasheet says that rail is "not to be used
    # for external devices", and it feeds only VD10 and AVDD on the bridge.
    n = {k: Net(k) for k in ("GND", "USB_VBUS", "VIN_RAW", "+12V", "+5V",
                             "-6V_A", "+3V3", "+2V5", "+1V0", "+1V0_FT")}
    n["GND"].drive = 7
    return n


def decouple(net_hi, net_gnd, value="100nF", size="0402"):
    c = Part("Device", "C", value=value, footprint=FP_C[size])
    c[1] += net_hi
    c[2] += net_gnd
    return c


def resistor(a, b, value, footprint=FP_R):
    r = Part("Device", "R", value=value, footprint=footprint)
    r[1] += a
    r[2] += b
    return r


def pullup(net, rail, value="10k"):
    return resistor(net, rail, value)


def build():
    lp.setup()
    v = rails()

    fpga = lp.gatemate()
    ftdi = lp.bridge()
    ldo = lp.ldo_3v3()
    buck = lp.buck_dual()
    flash = lp.spi_flash()

    # ---- FPGA power. 0009: economy mode, core at 1.0 V so the SerDes
    # supplies share it rather than forcing a second low-voltage rail.
    for name in ("VDD", "VDD_PLL", "VDD_SER", "VDD_SER_PLL"):
        for p in lp.pins_matching(fpga, rf"^{name}$"):
            p += v["+1V0"]
    # Every GPIO bank supply and the clock supply sit at 2.5 V. Nothing on
    # this board tolerates above 2.75 V (0005).
    for p in lp.pins_matching(fpga, r"^VDD_(NA|NB|EA|EB|SA|SB|WA|WB|WC)$"):
        p += v["+2V5"]
    for p in lp.pins_matching(fpga, r"^VDD_CLK$"):
        p += v["+2V5"]
    for p in lp.pins_matching(fpga, r"^GND$"):
        p += v["GND"]

    # ---- Bridge power. VCC33/VDDA from the regulator; VCCIO at 2.5 V, which
    # is the whole reason this bridge was chosen over the FT2232H (0005).
    #
    # AVDD is NOT a 3.3 V pin. The datasheet pin table gives it as "+1.0V
    # power input for PLL" with an absolute maximum of 1.4 V, and DV10 as the
    # internal LDO output to be tied to VD10 and AVDD. An earlier revision of
    # this file had AVDD on +3V3, which is a destroy-the-part error.
    for nm in ("VCC33", "VDDA"):
        for p in lp.pins_matching(ftdi, rf"^{nm}$"):
            p += v["+3V3"]
    for p in lp.pins_matching(ftdi, r"^VCCIO$"):
        p += v["+2V5"]
    for p in lp.pins_matching(ftdi, r"^GND$"):
        p += v["GND"]
    # VBUS is now a bus-presence sense input rather than the supply. The
    # board is externally powered, so the bridge has to be told when a host
    # is actually attached; wiring this to the board's own +5V would assert
    # bus presence permanently, including with no cable in the socket.
    v["USB_VBUS"] += lp.pin_named(ftdi, "VBUS")

    # Internal 1.0 V LDO: DV10 out, VD10 and AVDD in, 4.7 uF to ground, which
    # is what the datasheet asks for verbatim.
    v["+1V0_FT"] += lp.pin_named(ftdi, "DV10")
    for p in lp.pins_named(ftdi, "VD10"):
        p += v["+1V0_FT"]
    v["+1V0_FT"] += lp.pin_named(ftdi, "AVDD")
    decouple(v["+1V0_FT"], v["GND"], "4.7uF", "0805")
    for _ in lp.pins_named(ftdi, "VD10"):
        decouple(v["+1V0_FT"], v["GND"])

    # ---- USB 3.0 Micro-B receptacle. Both the SuperSpeed pairs and the
    # USB 2.0 pair land here; the bridge falls back to High Speed on a 2.0
    # host, which is also where the 500 mA ceiling applies (0009).
    #
    # Signal naming follows the USB 3.0 connector convention: on a B-type
    # receptacle SSTX is what the device transmits and SSRX is what it
    # receives, because the cable ties StdA_SSTX to the B-side SSRX.
    usb = Part("Connector", "USB3_B_Micro", ref="J1",
               value="Connfly DS1104-01",
               footprint="Connector_USB:USB3_Micro-B_Connfly_DS1104-01")
    usb["VBUS"] += v["USB_VBUS"]
    for nm in ("GND", "DRAIN", "SHIELD"):
        usb[nm] += v["GND"]
    # usb["ID"] is left open on purpose: this is a device port, not OTG.

    Net("USB_DP").connect(usb["D+"], lp.pin_named(ftdi, "DP"))
    Net("USB_DM").connect(usb["D-"], lp.pin_named(ftdi, "DM"))
    # ---- The SuperSpeed pairs are deliberately not connected (0014).
    #
    # Isolating the data link is worth more than SuperSpeed is, and no
    # galvanic isolator exists for 5 Gbps -- the ADuM4165/4166 tops out at
    # USB 2.0 High Speed. That costs nothing here: 192 kHz / 24-bit stereo is
    # 9.216 Mbit/s against High Speed's 480, so 1.9 % utilisation, and the
    # FT601Q supports High Speed natively. Leaving the pairs unrouted also
    # removes the hardest constraint in this board's layout, two 5 Gbps
    # impedance-controlled differential pairs.
    #
    # They were wired, and wired wrongly, which is what settled it. A review
    # found USB_SSRX_P/N were the only multi-node nets on the board with an
    # INPUT at every pin: the receptacle's SSRX pins are inputs and so are the
    # bridge's RIDP/RIDN, so nothing drove them. The comment here asserted a
    # crossover inside the cable as fact and reasoned from it; USB 3.0 cables
    # have no such crossover, and the transmit pair was mirrored the same way.
    # SuperSpeed would never have trained and the link would have fallen back
    # to 480 Mb/s silently -- which is, ironically, the speed the design now
    # runs at on purpose.
    #
    # If SuperSpeed is ever wanted back, the host's transmit pair goes to the
    # device's receiver (SSTX on the connector to RIDP/RIDN on the bridge, no
    # capacitors, the host has them) and the device's transmitter goes to the
    # connector's SSRX through 100 nF. That is the opposite of what was here.

    # ---- Wall wart input (0014, superseding 0009).
    #
    # The board is externally powered. USB now carries data only, and the
    # connector's VBUS reaches nothing but the bridge's sense pin. Everything
    # the old bus-power budget constrained -- 472 mA against a 500 mA host,
    # the 150 mA one-unit-load rule before enumeration, the 4.43 V worst case
    # -- stops applying here.
    #
    # 12 V rather than 5 V so the negative analog rail can eventually be made
    # by inversion instead of by a doubler. That part is not built yet: the
    # mezzanine still carries +5V and the module still has its charge pump.
    jack = Part("Connector", "Barrel_Jack", ref="J4",
                value="12 V 2.1 x 5.5 mm, centre positive",
                footprint="Connector_BarrelJack:BarrelJack_Horizontal")
    jack[1] += v["VIN_RAW"]
    jack[2] += v["GND"]

    # Resettable fuse first, so a downstream short does not depend on the
    # adapter's own protection being sane.
    #
    # 1812L050/30, chosen against the Littelfuse 1812L table rather than
    # named from memory. The line here used to say "1.1 A hold, 2.2 A trip"
    # in an 1812, which matches exactly one device in that series -- and it
    # is rated 6 Vdc, on a 12 V rail.
    #
    # Three things had to hold together and only this part does all three:
    #
    #   30 Vdc   covers 12 V nominal, the 19 V brick that fits the same
    #            barrel, and the TVS clamping at 29.2 V. The 24 V parts do
    #            not clear that last one.
    #   100 A    against an inrush reaching 27.9 A in the stiffest corner
    #            simulated. The 24 V and 33 V variants drop to 20 A, which
    #            is under it.
    #   0.50 A   hold, against 219 mA drawn. The obvious smaller choice,
    #            1812L035/30, derates to 0.20 A hold at 70 C -- below the
    #            board's own draw -- and would nuisance-trip in a warm
    #            enclosure. This part holds 0.33 A at 70 C and 0.29 A at 85.
    #
    # Trips at 1.00 A, and at 8 A within 0.15 s. R1max is 1.0 ohm, so the
    # worst-case drop at full load is 219 mV out of the volts of headroom
    # the buck has spare.
    fuse = Part("Device", "Polyfuse", ref="F1",
                value="1812L050/30 PPTC 0.5A hold 30V 100A",
                footprint="Fuse:Fuse_1812_4532Metric")
    fuse[1] += v["VIN_RAW"]
    prot = Net("VIN_FUSED")
    fuse[2] += prot

    # Reverse polarity by series Schottky rather than by a P-channel MOSFET.
    # At 12 V the 0.35 V drop costs about 210 mW and buys nothing back, which
    # would be the argument for the FET -- but there is a volt of headroom to
    # spare before the buck cares, and a diode has no gate to protect, no
    # Vgs rating to check against the input, and no body-diode conduction
    # path in the reversed case. The FET is the better answer on a 5 V rail;
    # here the simpler part is the better one.
    # Reverse polarity, and D1 is not doing this alone. With the adapter
    # backwards D1 blocks correctly, but its own reverse leakage is then the
    # only current in the circuit and it flows *out* of the protected node,
    # dragging it negative. What stops it is D2 conducting forward, which
    # pins the rail near one diode drop below ground: about -0.40 V,
    # against the LMR33630's -0.3 V absolute minimum on VIN and EN. Delete
    # D2 and the rail reaches -12.2 V. So the reverse case is held by the
    # TVS, not by the Schottky, and it is held marginally -- see the
    # unresolved -0.40 V against -0.3 V in the review.
    rev = Part("Device", "D_Schottky", ref="D1", value="SS34 3A 40V",
               footprint="Diode_SMD:D_SMA")
    rev["A"] += prot
    rev["K"] += v["+12V"]

    # Unidirectional TVS, 18 V rather than 15 V, and the reason is a
    # simulation result rather than a catalogue preference.
    #
    # 0014 claimed a 19 V laptop brick would make the TVS conduct and the
    # fuse trip. The first half is right and the second is not. A TVS
    # breakdown has a positive tempco -- 0.088 %/degC on this family -- so
    # conducting heats it, heating raises its breakdown, and the current
    # falls. The fault does not run away into a trip; it settles. At 19 V an
    # SMAJ15A lands at about 41 mA and 0.77 W with a junction near 117 degC,
    # indefinitely, while the board runs perfectly well beside it. That is a
    # heater, not a protection.
    #
    # And the protection was never needed for that case: the LMR33630 is a
    # 36 V part, so 19 V is simply an input it accepts. An 18 V standoff does
    # not conduct at 19 V at all, and still clamps a genuine surge at about
    # 29.2 V, inside the converter's rating. The TVS goes back to guarding
    # against transients, which is what a TVS is for.
    #
    # It must stay UNIDIRECTIONAL. See the reverse-polarity note below: the
    # bidirectional SMAJ18CA is one character away in a BOM line and removes
    # the only thing holding the rail out of the converter's negative limit.
    tvs = Part("Device", "D_TVS", ref="D2", value="SMAJ18A unidirectional",
               footprint="Diode_SMD:D_SMA")
    tvs["A1"] += v["GND"]
    tvs["A2"] += v["+12V"]
    # D3 pins the rail out of the converter's negative limit in the reversed
    # case, and it exists because the TVS alone does not quite manage it.
    # With the adapter backwards, D1 blocks and its own reverse leakage --
    # tens of microamps -- is then the only current in the circuit, flowing
    # out of this node and dragging it negative. D2 conducting forward is
    # what stops it, at about -0.40 V, against the LMR33630's -0.3 V absolute
    # minimum on VIN and EN. A hundred millivolts outside an absolute maximum
    # is not a place to leave a protection circuit.
    #
    # A Schottky in the same direction as D2's forward path clamps lower.
    # Simulated: the rail goes from -0.399 V to -0.233 V, inside the limit,
    # and it stays there at 12, 19 and 24 V reversed because the clamp sets
    # the level and the adapter voltage does not.
    #
    # The 100 degC leakage corner still reads -0.371 V, and it is left there
    # deliberately. Reaching it needs the SS34's 20 mA maximum leakage, which
    # is specified at 100 degC at rated reverse voltage -- and in this
    # scenario nothing in the circuit conducts, so nothing dissipates and the
    # junction sits at ambient. A diode can only be at 100 degC here if the
    # room is, which is outside anything this product claims. The applicable
    # figure is the 25 degC one.
    #
    # D3 also makes losing D2 survivable rather than fatal: with the TVS
    # removed the rail now settles at -0.37 V instead of -12.2 V.
    clamp = Part("Device", "D_Schottky", ref="D3", value="BAT54 negative clamp",
                 footprint="Diode_SMD:D_SOD-123")
    clamp["A"] += v["GND"]
    clamp["K"] += v["+12V"]
    decouple(v["+12V"], v["GND"], "22uF", "1210")
    decouple(v["+12V"], v["GND"], "100nF", "0603")

    # ---- 12 V to 5 V. Everything downstream of +5V is unchanged, which is
    # the point: the LTM4622, the LT3045 and the mezzanine all see the rail
    # they were designed against.
    # The footprint is the symbol's own default and is NOT overridden. It was,
    # with an HTSSOP-8 3x3 mm 0.65 mm-pitch land on a part whose package is
    # HSOP-8 at 3.9 x 4.9 mm and 1.27 mm pitch -- a different package
    # entirely, and unbuildable. That is the second time an override has
    # replaced a correct default with a wrong one on this board; the LT3045
    # got a 12-lead land for a 10-lead part the same way. The symbol carries
    # the right answer in its own fplist, so the rule now is to take it.
    buck5 = Part("Regulator_Switching", "LMR33630ADDA", ref="U5",
                 value="LMR33630 12V->5V 3A",
                 footprint="Package_SO:Texas_HSOP-8-1EP_3.9x4.9mm_P1.27mm_ThermalVias")
    for p in lp.pins_named(buck5, "GND"):
        p += v["GND"]
    buck5["VIN"] += v["+12V"]
    # EN to VIN: the part has its own UVLO and nothing here sequences ahead
    # of it.
    buck5["EN"] += v["+12V"]
    # One Net object, reused. Net("PG_5V") called twice creates two nets and
    # SKiDL uniquifies the second name, which is how both power-good pins and
    # both of their pull-ups ended up on four separate single-node nets --
    # resistors placed with a lead floating and flags that read a permanent
    # low. Nothing in the netlist generation complains; KiCad ERC would have,
    # on import, eventually.
    pg_5v = Net("PG_5V")
    buck5["PG"] += pg_5v
    pullup(pg_5v, v["+5V"], "100k")
    # VCC is the internal rail's own bypass, datasheet value.
    decouple(buck5["VCC"], v["GND"], "1uF", "0603")
    sw = Net("SW_5V")
    buck5["SW"] += sw
    # Bootstrap across SW to BOOT, datasheet value.
    cb = Part("Device", "C", value="100nF", footprint=FP_C["0402"])
    cb[1] += sw
    cb[2] += buck5["BOOT"]
    ind = Part("Device", "L", ref="L1", value="10uH 3A shielded",
               footprint="Inductor_SMD:L_12x12mm_H8mm")
    ind[1] += sw
    ind[2] += v["+5V"]
    # FB reference is 1.0 V, so VOUT = 1.0 * (1 + Rtop/Rbot).
    #   100k / 24.9k -> 1 + 4.016 = 5.02 V
    resistor(v["+5V"], buck5["FB"], "100k 1%")
    resistor(buck5["FB"], v["GND"], "24.9k 1%")
    decouple(v["+5V"], v["GND"], "47uF", "1210")

    # ---- -6 V for the module's analog stage (0015).
    #
    # The module used to make both analog rails itself, doubling 5 V and then
    # inverting the doubled rail. That cost 73 mA of pure conversion overhead
    # -- a third of the module -- and it is why the difference network sits at
    # 604 ohm instead of 200, forfeiting 2.1 dB: negative-rail current was
    # expensive there in a way it is not anywhere else.
    #
    # Only the NEGATIVE rail ever needed help. The output swings +/-2.83 V
    # peak and the OPA1612 reaches within 600 mV of its rails, so the positive
    # analog supply needs about 3.5 V and the mezzanine's 5 V already carries
    # it. The doubler existed only because the module made both rails
    # symmetrically from one.
    #
    # Same LMR33630 as above, wired as an inverting buck-boost: the device's
    # GND pin sits on the negative output, its SW drives the inductor back to
    # system ground, and it therefore sees VIN + |VOUT| = 18 V against a 36 V
    # rating. Reusing the part means one datasheet, one footprint and one
    # set of verified numbers rather than two.
    #
    # Feedback is referenced to the device's own ground, which is -6 V, so
    # the divider runs from system ground down to that rail and the part
    # regulates the difference: 1.0 V x (1 + 124k/24.9k) = 5.98 V.
    inv = Part("Regulator_Switching", "LMR33630ADDA", ref="U7",
               value="LMR33630 12V->-6V inverting",
               footprint="Package_SO:Texas_HSOP-8-1EP_3.9x4.9mm_P1.27mm_ThermalVias")
    for p_ in lp.pins_named(inv, "GND"):
        p_ += v["-6V_A"]            # the device's ground IS the negative rail
    inv["VIN"] += v["+12V"]
    inv["EN"] += v["+12V"]
    # Same idiom, same fault, and this one mattered more: U7's GND pin *is*
    # -6V_A, so 100 k to system ground is a pull-up relative to the device and
    # the only way this flag can be read at all. It was connected to nothing.
    pg_n6v = Net("PG_N6V")
    inv["PG"] += pg_n6v
    resistor(pg_n6v, v["GND"], "100k")
    decouple(inv["VCC"], v["-6V_A"], "1uF", "0603")
    sw_n = Net("SW_N6V")
    inv["SW"] += sw_n
    cbn = Part("Device", "C", value="100nF", footprint=FP_C["0402"])
    cbn[1] += sw_n
    cbn[2] += inv["BOOT"]
    # The inductor returns to system ground, which is what makes this
    # inverting rather than a buck.
    ind_n = Part("Device", "L", ref="L2", value="10uH 3A shielded",
                 footprint="Inductor_SMD:L_12x12mm_H8mm")
    ind_n[1] += sw_n
    ind_n[2] += v["GND"]
    resistor(v["GND"], inv["FB"], "124k 1%")
    resistor(inv["FB"], v["-6V_A"], "24.9k 1%")
    decouple(v["GND"], v["-6V_A"], "47uF", "1210")
    decouple(v["GND"], v["-6V_A"], "100nF", "0603")
    # Input bypass across the device's OWN terminals, which in this topology
    # are +12V and -6V_A rather than +12V and system ground. U7's GND pin is
    # the negative output, so the loop the switching current actually takes
    # runs between those two nets and nothing spanned them -- the input caps
    # near U5 are referenced to system ground and are not in this loop at all.
    # SNVSAN3F's VIN description says to bypass directly to the device's GND.
    #
    # This is the third fault found in U7 and all three are the same mistake:
    # reasoning about it as though its ground were the board's.
    decouple(v["+12V"], v["-6V_A"], "10uF", "1210")
    decouple(v["+12V"], v["-6V_A"], "100nF", "0603")

    # ---- 3.3 V regulator from bus voltage
    for p in ldo.pins:
        nm = str(p.name)
        if nm.startswith("IN"):
            p += v["+5V"]
        elif nm.startswith("OUT"):
            p += v["+3V3"]
        elif nm == "GND":
            p += v["GND"]
    # SET had no resistor, so the rail had no programmed voltage at all.
    # 33.2k is the E96 value nearest 33.0k and gives 3.32 V, inside the
    # FT601Q's 3.0 to 3.6 V window with room either side.
    #
    # C_SET is 100 nF here, not the 4.7 uF the helper defaults to, and the
    # reason is start-up rather than noise. The SET pin sources 100 uA and
    # PGFB is tied to IN, which disables the 2 mA fast-start circuit, so the
    # ramp is about 2.3 * R_SET * C_SET: 4.7 uF would take 359 ms. This rail
    # reaches nothing but the bridge and the flash, so the 0.8 uVRMS that
    # 4.7 uF buys is spent on two digital parts that cannot use it, while
    # the FT601Q's VCCIO comes up from the LTM4622 in microseconds and would
    # sit 355 ms ahead of its own VCC33. 100 nF brings the ramp to about
    # 7.6 ms and closes that gap. Every rail that does reach the signal keeps
    # the 4.7 uF and the specification it pays for.
    lp.lt3045_housekeeping(
        ldo, v["+5V"], v["GND"], "33.2k 0.1%",
        lambda a, b, val: resistor(a, b, val),
        lambda a, b, val: decouple(a, b, val, "0805"),
        c_set="100nF")
    decouple(v["+5V"], v["GND"], "10uF", "0805")
    decouple(v["+3V3"], v["GND"], "10uF", "0805")
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

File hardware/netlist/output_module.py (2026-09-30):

#!/usr/bin/env python3
"""Output module netlist: oscillators, divider, registers, resistors, analog.

    KICAD10_SYMBOL_DIR=... python hardware/netlist/output_module.py

There is no DAC chip. The FPGA drives element lines; this board reclocks them,
sums them through matched resistors, and filters the result (0008, 0012).

Every part is now a real one. The four that were placeholders - the oscillator,
the divider and fanout, the 16-bit register and the op amp - were selected
against their datasheets, and the parts the stock libraries do not carry have
symbols in ../symbols/lyrebird.kicad_sym with pinouts taken from those
datasheets. See ../lyrebird-dac-reva/parts-notes.md for why each one, and for
what could not be verified.
"""

from __future__ import annotations

import os
import sys
from pathlib import Path

HERE = Path(__file__).resolve().parent
sys.path.insert(0, str(HERE))

from skidl import Net, Part, generate_netlist, generate_xml  # noqa: E402
import lyrebird_parts as lp  # noqa: E402

OUT = HERE.parent / "lyrebird-dac-reva"
N_ELEM = 32          # header provisions 32; 28 used by 3-bit differential
N_USED = 28
PER_CH = 14          # 7 positive + 7 negative


def _res(a, b, value):
    r = Part("Device", "R", value=value,
             footprint="Resistor_SMD:R_0402_1005Metric")
    r[1] += a
    r[2] += b
    return r


def _cap(a, b, value, footprint="Capacitor_SMD:C_0805_2012Metric"):
    c = Part("Device", "C", value=value, footprint=footprint)
    c[1] += a
    c[2] += b
    return c


def build():
    lp.setup()
    gnd = Net("GND"); gnd.drive = 7
    v5 = Net("+5V")
    v3v3_clk = Net("+3V3_CLK")     # clock chain, its own regulator
    v3v3_ref = Net("+3V3_REF")     # element reference: sets full scale
    vpos = Net("+5V_A"); vneg = Net("-5V_A")
    # The A side of the translator, the header-facing domain, has to be 2.5 V
    # and the header only carries +5V and ground (interface.md), so the
    # module regulates it. It is a logic supply, not a reference: nothing on
    # it reaches the signal.
    v2v5 = Net("+2V5")
    # Oscillator enables after translation, in the module's 3.3 V domain.
    osc_en = {"OSC_EN_48": Net("OSC_EN_48_3V3"),
              "OSC_EN_441": Net("OSC_EN_441_3V3")}

    # ---- Mezzanine header, mating with the main board's J2
    mez = Part("Connector_Generic", "Conn_02x40_Odd_Even", ref="J1",
               value="Mezzanine 2x40",
               footprint="Connector_PinHeader_1.27mm:PinHeader_2x40_P1.27mm_Vertical")
    mez_pins = list(mez.pins)
    idx = 0

    def nxt():
        nonlocal idx
        p = mez_pins[idx]; idx += 1
        return p

    elem = []
    for i in range(N_ELEM):
        n = Net(f"ELEM{i}")
        n += nxt()
        gnd += nxt()
        elem.append(n)
    mclk_out = Net("MCLK")          # module drives this back to the FPGA
    mclk_out += nxt()
    ctrl = {}
    for sig in ("OSC_EN_441", "OSC_EN_48", "MUTE_N", "ID0", "ID1"):
        n = Net(sig); n += nxt(); ctrl[sig] = n
    # Two pins of -6 V, then the alternating tail. This mirrors the main
    # board's allocation exactly and has to: the two halves of the connector
    # agree pin for pin or nothing works, and the pair is adjacent so a
    # half-inserted connector cannot present one without the other.
    # 100 k to ground so the net is defined rather than floating while the
    # FPGA is unconfigured and its pin is high impedance -- which, with the
    # rails gated off it, means the analog stage stays off until something
    # deliberately turns it on.
    _res(ctrl["MUTE_N"], gnd, "100k")
    # The negative analog rail, flanked by ground, mirroring the main board
    # pin for pin -- the two halves of the connector agree or nothing works.
    # The flanking exists because -6 V immediately beside the ID straps, in a
    # control block with no ground pin in it, is one whisker away from a
    # GateMate GPIO that has only a 10 k pull-down between it and the rail.
    mez_neg = Net("-6V_A")
    rail_pins = {"+5V": set(), "-6V_A": set()}
    for _ in range(2):
        gnd += nxt()
    for _ in range(2):
        pin = nxt()
        mez_neg += pin
        rail_pins["-6V_A"].add(str(pin.num))
    for _ in range(2):
        gnd += nxt()
    while idx < len(mez_pins):
        pin = nxt()
        if idx % 2 == 1:
            v5 += pin
            rail_pins["+5V"].add(str(pin.num))
        else:
            gnd += pin

    # ---- Oscillators. Crystek CCHD-957 at twice the element clock (0012),
    # option X for -40 to +85 C at +/-25 ppm. Standby shuts the resonator
    # down rather than only gating the output, so an idle oscillator does not
    # radiate next to the analog section.
    #
    # Both outputs share one net, which is only legal because the datasheet
    # says the output buffer is tri-stated as well as the resonator stopped:
    # "when placed in disable mode, the internal oscillator is completely
    # shut down in addition to its output buffer being placed in Tri-State".
    # E/D is active high with 0.7 x Vcc as the minimum logic one, and an open
    # pin runs, so the translated enables drive it directly.
    osc_out = Net("OSC_RAW")
    for ref, val, en in (("Y1", "CCHD-957X-25-49.152", "OSC_EN_48"),
                         ("Y2", "CCHD-957X-25-45.1584", "OSC_EN_441")):
        y = Part("lyrebird", "CCHD-957", ref=ref, value=val,
                 footprint="lyrebird:Oscillator_SMD_Crystek_CCHD-957_9x14mm")
        y["Vcc"] += v3v3_clk
        y["GND"] += gnd
        y["OUT"] += osc_out
        y["E/D"] += osc_en[en]
    # 100 k to ground on each enable, for the same reason MUTE_N has one: an
    # open E/D pin runs, and before the FPGA is configured its pins are high
    # impedance and the translator's outputs may be too. Without these, both
    # oscillators start and drive OSC_RAW into each other -- the one net where
    # that is possible, because the shared output is only legal while exactly
    # one part is enabled. Defaulting both off is safe: nothing downstream
    # needs the element clock until the FPGA is running.
    for _en in osc_en.values():
        _res(_en, gnd, "100k")
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

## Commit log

2026-09-12 Add repository skeleton and architecture decision records
    Structure for a two-board USB audio project: a main board carrying the
    USB 3.0 bridge and the FPGA, and an output module carrying the audio
    oscillators, reclocking registers, resistor elements, and analog stage.
    Nine decision records capture the load-bearing choices and the reasoning
    behind them, including two that reversed earlier ones:
    - FT601Q replaces the FT2232H, forced by GateMate GPIO being LVCMOS to
    2.5 V with a 2.75 V absolute maximum. The FT2232H is 3.3 V only, so
    the original pairing was an over-voltage condition, not a margin issue.
    - The FPGA is the DAC. It runs an interpolator and a three-bit
    delta-sigma modulato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
2026-09-12 Resolve the PLL bypass question in the clocking notes
    The bypass path onto the global mesh works and the open toolchain selects
    it automatically, but not through the port the datasheet implies.
    A CC_BUFG driven by a clock-capable pad causes nextpnr to wire the CLKIN
    reference directly into the GLBOUT mux, keeping the VCO out of the path.
    CC_PLL does declare a CLK_REF_OUT port, but nextpnr rejects it: the bypass
    belongs to the CLKIN-to-GLBOUT path rather than to a configured PLL.
    The practical consequence is a pinout constraint. A clock on an ordinary
    pin falls back to fabric routing as a user global, which adds the jitter
    the bypass exists to avoid, and does so without raising an error.
    V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
2026-09-12 Describe both boards as code, emitting KiCad netlists
    Stock KiCad 10 libraries carry almost everything this design needs,
    including a Cologne Chip GateMate library, which removed the obstacle I
    expected to dominate this work. SKiDL reads those symbols, so pin assignment
    is against the real 324-ball map rather than invented.
    Generating rather than drawing buys one thing that matters here. A clock on
    an ordinary pin is not an error in the FPGA toolchain: the packer routes it
    through the fabric and adds the jitter the bypass path exists to avoid, with
    no warning. Because the netlist is generated, that assignment is asserted,
    and the output confirms both clocks land on clock-capable balls. Ever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
    [lyrebird_parts.py, main_board.py, output_module.py]
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2026-09-13 Document both boards: brief, power with arithmetic, and BOM
    Per-board power documents showing every rail's provenance, and bills of
    materials that count 3 selected against 12 missing on the main board, and 4
    selected against 9 placeholders and 8 missing on the module. Both power
    documents name the same boundary, the mezzanine +5 V pins downstream of the
    VBUS ferrite, and their totals agree line for line.
    Checking decision 0009's budget rather than copying it moved four lines and
    landed at 381 mA against its 380, which is closer to coincidence than to
    agreement since the differences cancel.
    The element reference line went from 25 to 56 mA, and that is the finding
    worth keeping. 0009's figur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
    [bom.csv]
2026-09-13 Close the netlist gaps, and fix five overvoltage or dead-rail bugs
    Main board unconnected pins fall from 111 to 78, the module's from 57 to 35,
    and both generate with zero errors. What remains is deliberate: unused bank
    I/O, the SerDes, pins the datasheets say not to connect, and parts never
    chosen.
    Five bugs, all mine from the original netlist commit, three of which would
    have destroyed hardware.
    AVDD on the bridge was wired to 3.3 V. It is a 1.0 V phase-locked loop supply
    with a 1.4 V absolute maximum, so every board built would have failed.
    The divided element clock reached the mezzanine directly, and the element
    reference rail was shorted onto the module identification strap. Both put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
    [lyrebird_parts.py, main_board.py, output_module.py]
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2026-09-13 Generate both boards from the netlists, and open them
    Both boards now exist as KiCad files: 133 footprints and 721 pads across 125
    nets on the main board, 42 and 308 across 82 on the module, matching the
    netlists exactly.
    tools/netlist_to_pcb.py does the import, because KiCad exposes no netlist
    reader to Python and kicad-cli's import subcommand handles foreign PCB formats
    rather than netlists. It loads each footprint, places it on a grid and attaches
    pads to nets, which is what the GUI's File, Import, Netlist does. The grid is
    legibility, not layout.
    It rebuilds from scratch, so it is right for now and wrong once routing starts;
    the note says to switch to the GUI importer then, since that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
    [lyrebird-dac.kicad_pcb, lyrebird-main.kicad_pcb]
2026-09-13 Generate readable schematics so the circuitry can be reviewed
    Both boards now have a schematic that opens in the schematic editor: 133
    symbols on the main board, 42 on the module, every part as its real symbol
    with reference and value, and every pin carrying a net label.
    No wires are drawn, and that is the design rather than a shortcut. Routing
    wires into a readable drawing is the part that cannot be automated, and it is
    where SKiDL's own schematic generator hangs on the 324-ball part. Labels avoid
    the problem entirely and stay legible at any size, so connectivity is read from
    net names rather than by tracing lines.
    Two dead ends first. SKiDL's generate_svg needs an external Node tool, and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
    [lyrebird-dac.kicad_sch, lyrebird-main.kicad_sch]
2026-09-13 Draw wires in the schematics instead of relying on net labels
    Labels alone are hard to follow, so nets of two or three pins are now drawn
    as wires and the parts sharing one are placed next to each other to keep the
    wire short. That covers 119 of the main board's 125 nets and 68 of the
    module's 82.
    The split follows what a person does by hand rather than a rule of thumb.
    Ground, the supply rails and the element bus stay as labels, because a wire
    joining 245 ground pins is not a drawing anyone can read. Everything else is
    a line you can trace.
    Parts are clustered by the nets that join them, 94 clusters on the main board
    and 19 on the module, so a wire is usually a short hop between neighbour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
    [lyrebird-dac.kicad_sch, lyrebird-main.kicad_sch]
2026-09-13 Pack the schematics into a readable shape
    Both sheets were strips: the main board ran 1765 mm wide across five bands,
    the module 1509 across three, at aspect ratios of 6.4 and 10 to 1. Nothing
    about that is followable.
    Two changes. A cluster is now laid out as a compact block rather than a
    single row, so twenty parts sharing a net form a scannable square instead of
    a line. And the blocks are shelf-packed toward the proportions of a sheet of
    paper rather than running rightward until a fixed width is hit.
    The main board now reads as 663 by 706 mm across 14 bands, the module as 414
    by 411 across 8. Roughly square rather than landscape, because shelf packing
    wastes about a third of its area an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
    [lyrebird-dac.kicad_sch, lyrebird-main.kicad_sch]
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2026-09-17 Validate against real material, and find the idle fault was the ruler
    Three threads, all still running; this commits what has landed so far so
    it survives.
    The idle-channel result overturns an open item. The 15 to 19 dB loss that
    looked like a rare loop fault is a measurement artifact: `x - x.mean()`
    is not the mean a Kaiser-windowed transform sees, and a record whose
    offset drifts across the window keeps a DC bin whose main lobe lands in
    the lowest audio bins. The same tripped record measures 143.40 dB with
    the windowed mean removed, and 143.69 dB over 2^21 with nothing
    corrected at all. The 1-in-36 rate was the rate at which one or two
    unbalanced samples lined up with the window's centre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
    [output_module.py]
2026-09-17 Measure the blast radius: two published results were the ruler, not the chain
    The idle thread finished. It now says which published numbers move and
    which do not, each measured as one record taken twice so the difference
    is the mean removal and nothing else.
    Two results were wrong.
    The 15.7 dB attributed to round-half-up is the same artifact. Corrected,
    half-up and ties-to-even differ by 0.01 dB. The giveaway was that a
    rerun reproduced the shape of the table at a different rate -- half-up
    leaves the same offset at every rate, so a fault caused by that offset
    cannot move between rates, but a lottery over records can. Convergent
    rounding still earns its place, because the static offset it r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
    [output_module.py]
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2026-09-18 Find that the negative rail carries the signal, and re-run the logs
    The module's analog stage has a load the model did not contain. Every
    milliampere of element current ends up in the negative supply: the
    elements push into a node held at 0 V, the current leaves through the
    transimpedance resistor into the amplifier's output pin, and the output
    stage sinks it to V-. That is 13.9 mA, constant at every code by
    construction, and it is signal rather than quiescent current.
    The difference network is a second such load, because the
    transimpedance outputs are never positive, and its size is a choice:
    current scales as 1/R while its own noise scales as sqrt(R). At the
    200 ohm analog.txt names it as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
    [output_module.py]
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2026-09-22 Review the module, fix two footprint faults, and correct my own claim
    The LT3045s carried a DFN-12 footprint. The symbol has 11 pins, ten
    leads and an exposed pad; the DFN-12 land has pads 1 to 13. The
    generated netlist stated the contradiction on adjacent lines, a
    DFN-10 description above a DFN-12 footprint, and nothing checks that
    pairing. Both LT3045 instances now use DFN-10-1EP_3x3mm_P0.5mm with
    the same exposed pad. The LT3094 keeps DFN-12 and is right to: that
    symbol has 13 pins.
    The oscillator enables floated before configuration. MUTE_N was given
    a 100 k pull-down for exactly this reason and these were not, while
    the comment directly above them records that an open E/D pin runs.
    Bot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
    [output_module.py]
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2026-09-22 Act on E-1 through E-5 on the main board
    E-2, the one that would have destroyed a board in the field, is fixed.
    The JTAG header handed an off-board adapter direct access to bank WA,
    and 0006 specifies an ordinary FTDI adapter -- the common ones are
    fixed 3.3 V drivers into a ball rated 2.75 V. TMS, TCK and TDI now
    carry 1k in series, with the pull-up moved to the FPGA side so the ball
    is still held high with nothing plugged in. UG1003 endorses a series
    resistor for exactly this case and recommends 10k, which cannot be used
    here: in series with the 10k pull-up Cologne Chip's own figure 3.10
    asks for, it would divide a driven low to 1.25 V. 1k holds a low at
    227 mV and bounds the clamp current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
    [main_board.py]
2026-09-24 Consolidate the reviews, and close the oscillator enable properly
    One actionable list across all five sections, in docs/review/2026-09-21/
    actions.md, ordered by what it costs to get wrong. Twelve items where a
    document or the model states something untrue, seven quantities that
    have different values in different files, seven decisions that need a
    person, and exactly one thing that would stop a board working.
    That one is the Crystek footprint's pad numbering, rotated 90 degrees
    against the datasheet's bottom view. It is left open deliberately: the
    two ways of putting pins 1 and 2 on one end differ by a mirror, so
    guessing would replace a known fault with an unknown one.
    My own oscillator-e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
    [main_board.py]
2026-09-24 Fix a supply that arrived a third of a second late
    The +3V3 rail took 359 ms to reach voltage, and the module's op amp
    positive rail 539 ms. Nothing was wrong with either choice that caused
    it. A 4.7 uF capacitor on SET is the condition for the 0.8 uVRMS that
    0009 quotes, and tying PGFB to IN is what the datasheet says to do when
    power-good is not needed -- but PGFB also gates the 2 mA fast-start
    circuit that exists to charge that capacitor, so the SET pin's 100 uA
    does the work alone and the ramp is 2.3 * R_SET * C_SET. Two correct
    decisions, quoted from the same datasheet, multiplying.
    The consequence was a sequencing fault rather than a slow boot: the
    FT601Q's VCCIO comes up from the LTM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
    [lyrebird_parts.py, main_board.py]
2026-09-24 Take power from a wall wart, and leave USB carrying only data
    0009's reasoning was sound and its budget was not. Once every part was
    costed against a datasheet rather than estimated, the board drew 472 mA
    -- 94 percent of a 500 mA USB 2.0 host, at full scale, with the fixed
    load already counted. Everything after that point was designed against
    a ceiling: the difference network at 604 ohm instead of 200, costing
    2.1 dB; MUTE_N gating the analog supplies to stay inside 150 mA before
    enumeration; the core rail gated off WAKEUP_N, which means "bus not
    suspended" rather than "enumerated"; and a charge pump whose worst-case
    input sat below its own minimum. None of those was a mistake. They were
    co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
    [main_board.py]
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2026-09-24 Find, in transient, a board that would never have powered up
    0014 said the enumeration gating of the core rail was retired with bus
    power. It was not: main_board.py still built it, and the consequence is
    not a stale comment. WAKEUP_N is high in suspend and its pull-up holds
    it high whenever the bridge is not driving it, which on an externally
    powered board with no host attached is always -- gate high, RUN2 pulled
    down, and the FPGA core rail never comes up. The board was dead without
    a USB host it no longer needs for power.
    The transient found worse than the static reading would have. CORE_RUN
    reached its pull-up before the NMOS gate crossed threshold, so channel
    2 began its soft start into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
    [main_board.py]
2026-09-24 Act on the SPICE findings: clamp the reverse case, specify what matters
    The reverse-polarity violation is fixed rather than noted. D1 blocks as
    it should, but its own leakage then drags the protected node negative
    and D2's forward drop was the only thing stopping it, at -0.399 V
    against the LMR33630's -0.3 V absolute minimum. A Schottky in the same
    direction clamps lower at the microamps that are the only current in
    that case: simulated, the rail now settles at -0.233 V, and it stays
    there at 12, 19 and 24 V reversed because the clamp sets the level and
    the adapter does not. It also makes losing the TVS survivable instead
    of fatal -- with D2 removed the rail reaches -0.37 V where it used to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
    [main_board.py, output_module.py]
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2026-09-24 Decision 5, option B: the negative rail crosses the mezzanine
    The module no longer makes its own analog supplies. The main board
    inverts 12 V to -6 V and sends it across two mezzanine pins taken from
    the ground allocation, and the module's LT3094 regulates it at the
    point of load, where its rejection is what the design leans on.
    The positive rail turned out never to have needed the charge pump. The
    output swings +/-2.83 V peak and the OPA1612 reaches within 600 mV of
    its rails, so the positive supply wants about 3.5 V -- and the
    mezzanine has carried 5 V all along. The doubler existed because the
    module made both rails symmetrically from one, not because either rail
    required it. An LT3045 s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
    [lyrebird_parts.py, main_board.py, output_module.py]
2026-09-25 Regenerate the schematics, which were eleven days behind the netlists
    The sheets and both PDFs dated 13 September against netlists from
    today. They showed a board with USB bus power, a charge pump on the
    analog module, no JTAG series protection, no oscillator pull-downs and
    none of the footprint corrections -- a board that has not existed for
    some time. Anyone opening them to review the design would have been
    reviewing the wrong one, which is worse than having no schematic.
    Regenerated from the current netlists: the main board goes from 8
    sheets to 11, picking up the wall-wart input and the inverter, and the
    module from 6 to 9 while losing the charge pump entirely. Both PDFs
    rebuilt through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
    [01-Element-resistors-Thin-film-arrays-so-elements-s.kicad_sch, 01-Precision-rails-The-element-reference-sets-full-.kicad_sch, 01-U1-CCGM1A1-BGA324.kicad_sch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]
2026-09-25 Choose the fuse against the table rather than from memory
    1812L050/30. The line it replaces said "1.1 A hold, 2.2 A trip" in an
    1812, which matches exactly one device in the Littelfuse 1812L series
    and that device is rated 6 Vdc, on a 12 V rail.
    Three constraints had to hold together and only this part does all
    three. 30 Vdc clears 12 V nominal, the 19 V brick that fits the same
    barrel, and the SMAJ18A clamping at 29.2 V -- the 24 V parts do not
    clear that last one. 100 A of Imax covers the 27.9 A of inrush the
    transient simulation found in its stiffest corner, where the 24 V and
    33 V variants drop to 20 A and sit under it.
    The third constraint is the one that picked between two plausible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
    [main_board.py]
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2026-09-25 Check whether the documents still describe the boards, and rebuild the BOMs
    Three times now the same failure has been found by accident: schematics
    eleven days behind the netlists, a simulation asserting failures
    against circuits already fixed, and power.md still listing AVDD on
    +3V3 -- a destroy-the-part bug the netlist corrected long ago and the
    document went on documenting. The netlist generators run constantly,
    everything derived from them runs occasionally, and nothing compared
    the two.
    hardware/check_freshness.py compares them. Timestamps first, which are
    cheap and weak -- a derived file older than its source is definitely
    stale, a newer one only means somebody ran something. Then BOM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
    [08-Other.kicad_sch, bom.csv]
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2026-09-26 Fix a rail programmed above what its input can deliver
    The documentation validator found an electrical fault, which is not
    where one expects to find one. U14, the module's positive analog
    regulator, had its SET resistor at 49.9k -- programming 4.99 V -- and I
    had moved its input from the charge pump's 5.69 V to the header's 5.02 V
    without touching it. Thirty millivolts of headroom against a part whose
    published dropout is 260 mV at 500 mA. The rail would not have reached
    its programmed voltage.
    45.3k now, for 4.53 V and 490 mV of headroom. The stage needs far less
    than either: it swings +/-2.83 V peak and the OPA1612 reaches within
    600 mV of its rails, so 3.43 V would do. The rails are deli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
    [04-The-bipolar-rail-decision-5-option-B-supersedes-.kicad_sch, bom.csv]
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2026-09-26 Connect two power-good nets that were connected to nothing
    The schematic validator found a confirmed fault, and it is the kind that
    reads as correct code. `Net("PG_5V")` appears twice in main_board.py --
    once to attach the buck's power-good pin, once to attach its pull-up --
    and SKiDL creates a NEW net on each call, uniquifying the second name.
    The result was four single-node nets: both LMR33630 power-good pins
    alone, and both 100 k resistors with one lead floating.
    The inverter's half mattered more than the buck's. U7's GND pin *is*
    -6V_A, so 100 k to system ground is a pull-up relative to the device and
    the only way that flag can be read at all. It was reading nothing.
    Both now use one N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
    [03-12-V-to-5-V-Everything-downstream-of-5V-is-uncha.kicad_sch, 04-U4-LTM4622IVPBF.kicad_sch, 05-6-V-for-the-modules-analog-stage-decision-5-opti.kicad_sch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]
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2026-09-27 Write the decision record everything was already citing, and strike a claim
    Twelve files referred to "decision 5" and no such record existed. The
    phrase originated in a code comment and propagated into the decision
    index itself, where a bare "5" reads as 0005. It is 0015 now -- the
    negative rail crossing the mezzanine -- and every reference points at it.
    Writing it closed five separate flags at once, because it was the missing
    live home for all of them.
    0014 claimed a "second 1.1 dB nobody was looking for" from a
    noise-optimal element resistor at 2585 ohm. I wrote that and it is wrong
    twice over, which a validation pass established and I confirmed by
    recomputing:
    * 2585 ohm is not an opt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
    [04-The-bipolar-rail-0015-superseding-0009s.kicad_sch, 05-6-V-for-the-modules-analog-stage-0015.kicad_sch]
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2026-09-28 Set U14 by solving both its bounds, and check the corner not the nominal
    The schematic validator worked my 45.3k fix through the datasheet
    tolerances rather than the nominal values and found it still negative:
    the LMR33630's own VFB spread plus 1 % divider resistors put +5V as low
    as 4.86 V, the LT3045's SET reference spans 98 to 102 uA, and its
    dropout at the 1-50 mA these rails carry is 220/275/330 mV rather than
    the 260 mV headline at 500 mA. Stacked, 45.3k leaves about -90 mV.
    A part in dropout does not fail loudly. It stops regulating and passes
    its input's ripple through, on the rail feeding six amplifiers whose
    supply rejection is the reason the regulator is there at all.
    40.2k now,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
    [output_module.py]
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2026-09-29 Flank the negative rail with ground, and keep the power review
    The power validator found the pin map I wrote put -6V_A in the column
    immediately beside ID1. On a 2x40 odd/even header pins 2k-1 and 2k share
    a column, and the control block -- MCLK, both oscillator enables, MUTE_N
    and both ID straps, pins 65 to 70 -- has no ground pin inside it at all.
    One bridge or one whisker across 1.27 mm would have put -6 V on a net
    that reaches a GateMate GPIO through nothing but a 10 k pull-down, with
    the input's clamp diode conducting and the current limited only by the
    bridge.
    The pair is now column 37, with full ground columns at 71/72 and 75/76
    either side. Adjacent to itself still, so a half-insert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
    [05-Mezzanine-header-32-element-lines-each-beside-a-.kicad_sch, 07-Mezzanine-header-mating-with-the-main-boards-J2.kicad_sch]
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2026-09-29 Fix a third footprint fault, and make the class unrepeatable
    Both LMR33630s carried an HTSSOP-8 land, 3 x 3 mm at 0.65 mm pitch, on
    a part whose package is HSOP-8 at 3.9 x 4.9 mm and 1.27 mm. A different
    part entirely, unbuildable, and repeated in two BOM rows marked
    VERIFIED. The symbol's own footprint field named the right land all
    along and an explicit override replaced it -- which is exactly how the
    LT3045 got a 12-pad DFN meant for the LT3094.
    Three of the power tree's parts have now had the wrong land pattern, so
    the useful work is not the fix. lp.assert_symbol_footprints fails the
    build when a part overrides a symbol that names its own footprint. It
    applies only where the symbol is s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
    [bom.csv]
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2026-09-30 Work the reconciliation's top five, and stop checks passing on nothing
    Four of the five are done and the fifth cannot be done from a PDF.
    The abs-max allowance is per pin, the core check covers the bridge as
    well as the FPGA and walks bridges of any pin count, and interface.md no
    longer claims the oscillator rule is enforced. What remained from that
    list is here.
    **Checks now assert they found something.** This project has now been
    bitten three times by a check reporting success because it located no
    subjects: a netlist reader looking for pin-name fields the netlist does
    not contain, assert_core_rail with its pin names matching nothing, and
    ldo_rails failing open three ways -- a value spel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
    [01-Element-resistors-Thin-film-arrays-so-elements-s.kicad_sch, bom.csv]
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
